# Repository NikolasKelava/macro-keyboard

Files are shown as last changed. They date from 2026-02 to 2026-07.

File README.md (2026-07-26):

# Macro Keyboard

A custom, wireless **Bluetooth LE macro keypad** with 12 mechanical keys, a magnetic rotary
encoder, and a 128×64 OLED built on a Nordic **nRF52840** module and running
[**ZMK**](https://zmk.dev). Keys and profiles are configurable live over ZMK
Studio; the encoder is a per-profile knob (volume / vertical scroll / horizontal
scroll / browser tabs). Battery-powered (2000 mAh LiPo) with USB-C charging.

This project was submitted to the **Hack Club Horizons** program. Its progress is logged
in [JOURNAL.md](./JOURNAL.md). The admission is still pending.

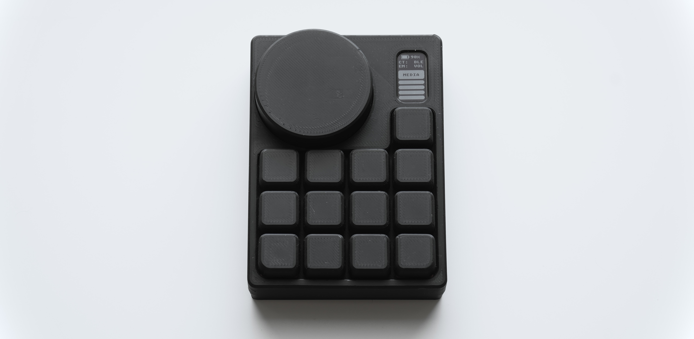
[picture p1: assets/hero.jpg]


---

## What is a macro keyboard?

A macro keyboard is a **Human Interface Device** (HID), which executes **macros** on a connected
host computer. In this sense, it functions like a conventional keyboard, serving as the 
interface between human input and a computer action.

The difference between a standard keyboard and a macro keyboard lies in their respective 
functionalities. A standard keyboard performs "normal" key bindings (e.g., numbers, letters,
and function buttons), while a macro keyboard performs macros. These can be media keys 
(e.g., volume up/down, skip title), open applications on the host computer or executing 
entire commands, performing actions that would otherwise require **multiple keystrokes on a 
standard keyboard**.

This makes it easier to navigate the operating system by **removing friction** between the user
and the host.

## What is my macro keyboard and what does it do?

**My macro keyboard has 12 macro keys, a rotary magnetic encoder, an OLED display, is battery 
powered and supports up to 7 profiles.**

The **macro assigned to each key** can be configured **per profile**. Depending on which profile is 
active, a key can have up to seven different functions. Consequently, we can perform up to **84
different actions** with our 12 keys.

The **encoder mode** can also be configured. It can act as a **scroll wheel** in both vertical and
horizontal direction, control the **volume** or switch between browser tabs on the host. These **modes 
are bound to each profile** and can be changed by assigning a key on a profile, that cycles through 
the modes of the encoder. When moving to the next keypad profile, the encoder mode changes to the 
active profile's encoder mode. Returning to the previous profile will revert the encoder mode to its 
previous state.

The **OLED display** shows the selected keypad profile, the battery capacity, the connection mode, and 
the encoder mode.

You can think of the keypad profiles as the **user layer** of the macro keypad. These profiles are 
called the "keymap", and they are the layers where the macro keyboard's functionality is configured. 
This user layer live directly on the macro keyboard, so the macros stay **the same even when changing 
host devices.** A **profile** button on the macro keyboard is used to switch between profiles.

You can **configure** the keymap and profiles in real time without recompiling or reflashing the keypad 
through [**ZMK Studio**](https://zmk.studio), a graphical user interface for ZMK keyboard firmware.

The macro keyboard connects as a keypad **via Bluetooth** or **USB**. Hosts are cross-platform (Windows, 
macOS, Linux, and iOS). The keypad can be paired with up to five hosts and conveniently switch 
between them via assigned keys on the keymap.

## Layout

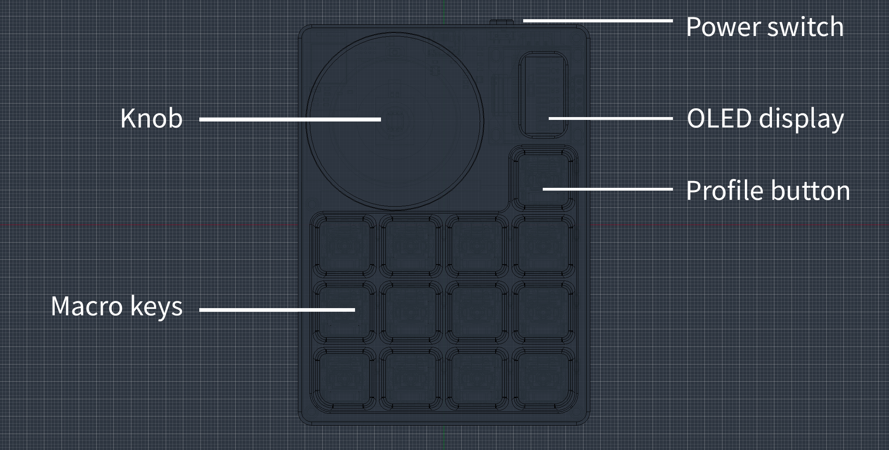
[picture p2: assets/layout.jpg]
Macro Keyboard layout


## Demo & photos

### Demo video:

[Quick demo video on youtube](https://youtube.com/shorts/6OSJ7Yoke_U)
 
### Photos: 

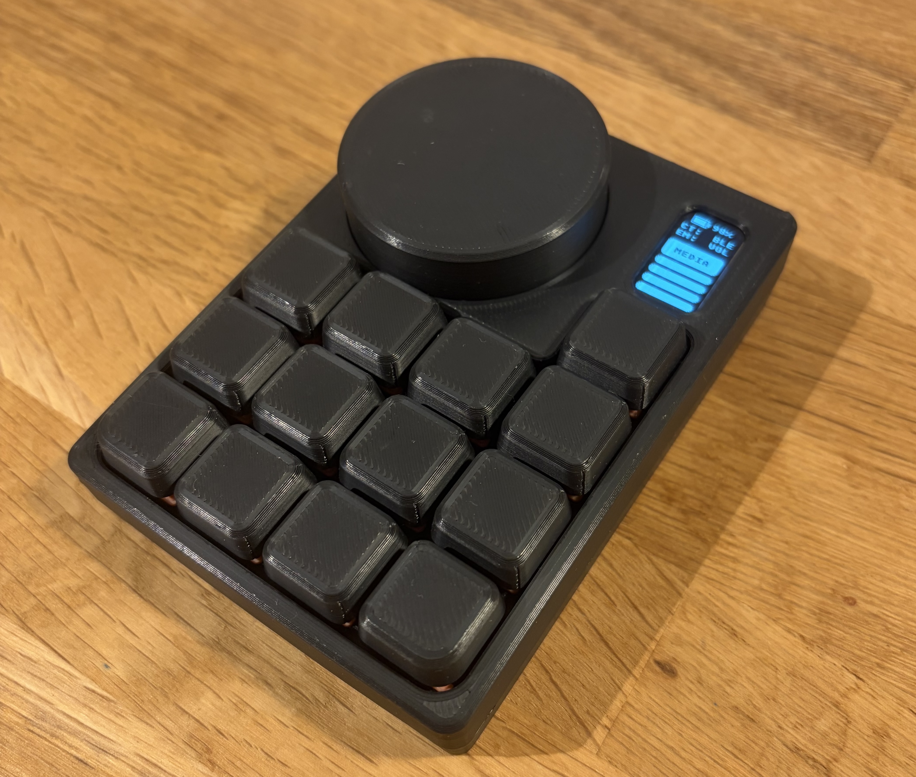
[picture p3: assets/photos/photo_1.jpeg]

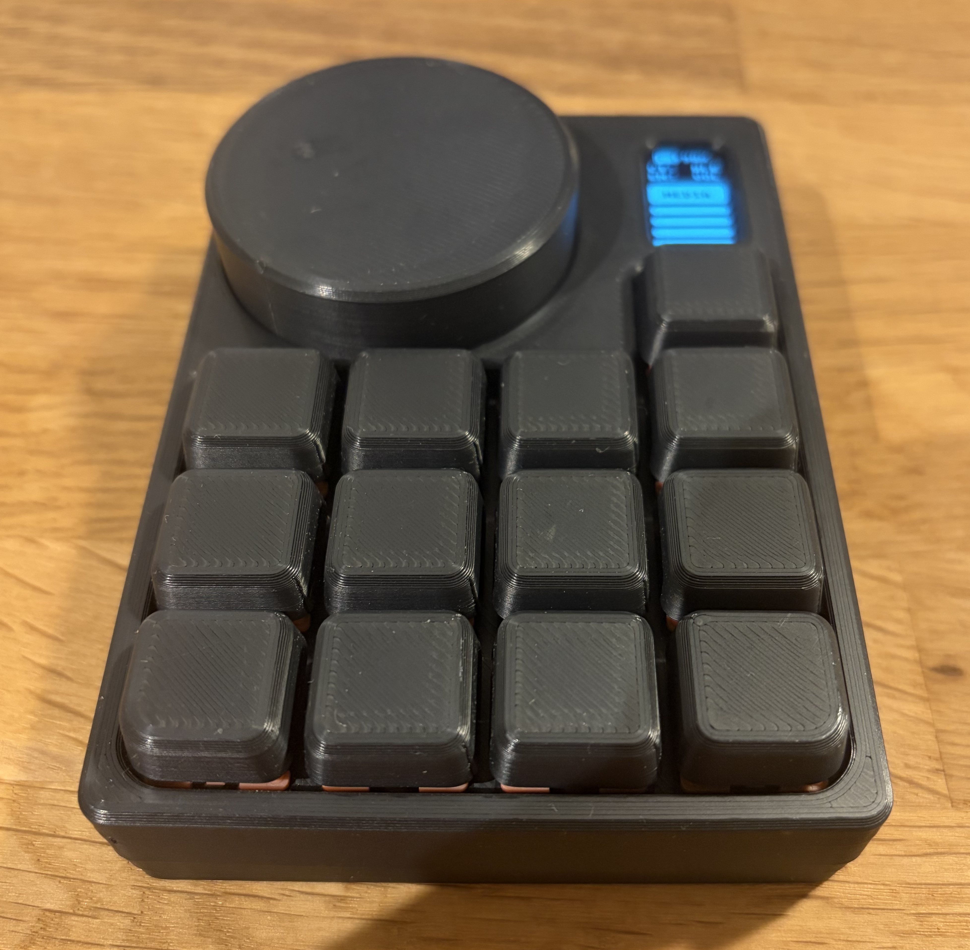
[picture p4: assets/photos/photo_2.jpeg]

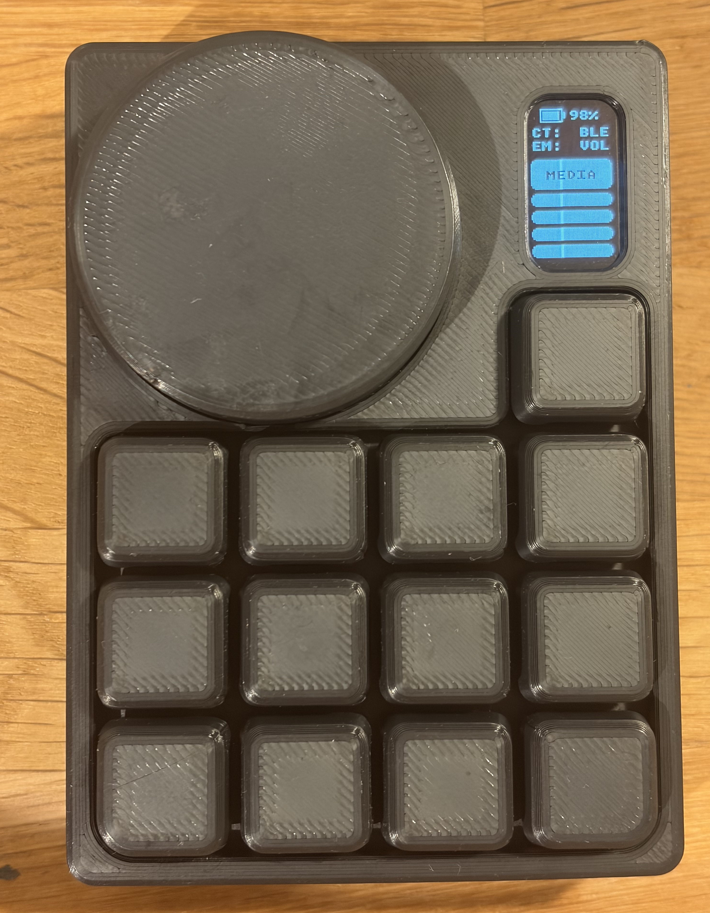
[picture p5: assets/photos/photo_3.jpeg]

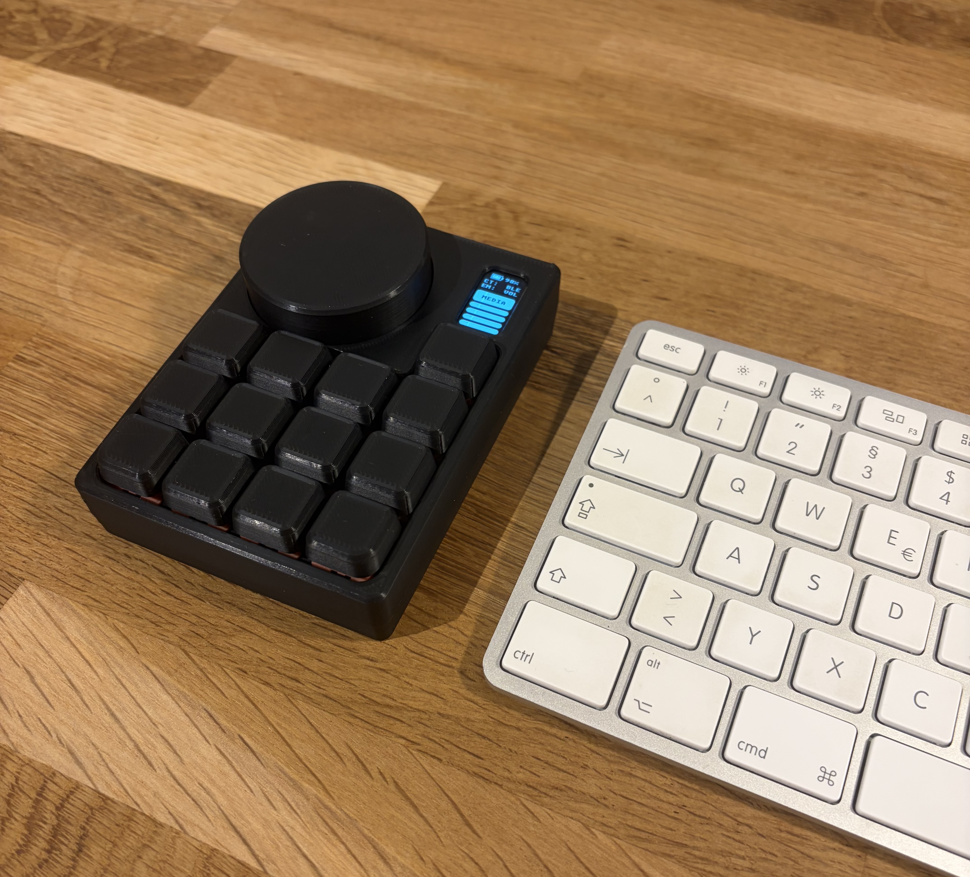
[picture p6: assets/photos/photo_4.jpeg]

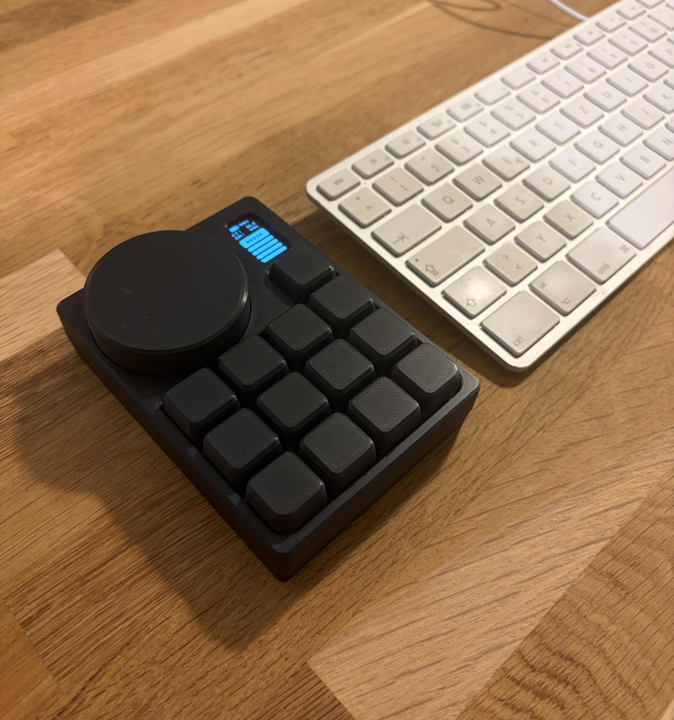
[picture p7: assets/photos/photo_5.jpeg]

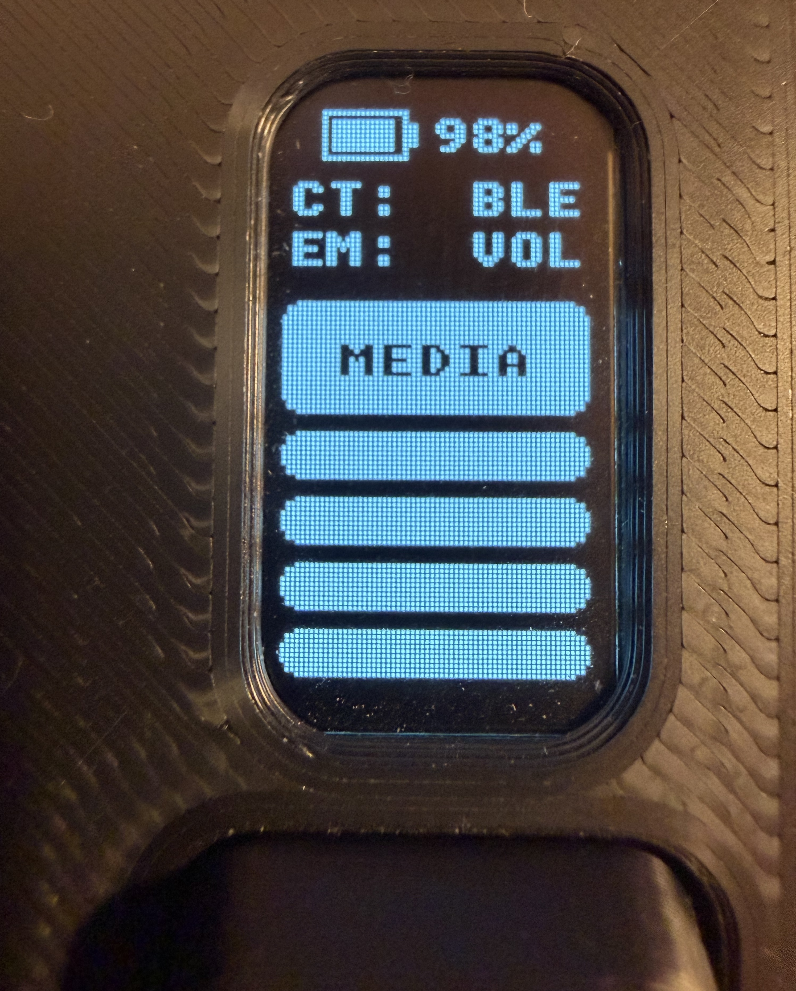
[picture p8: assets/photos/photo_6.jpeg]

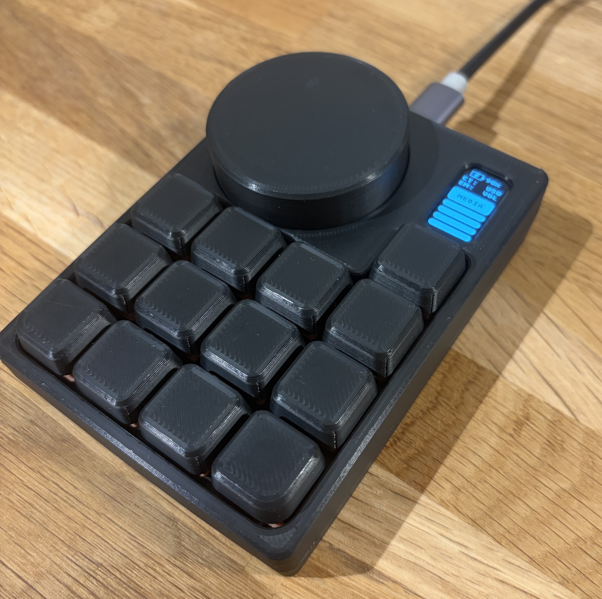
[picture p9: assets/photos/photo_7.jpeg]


## Hardware overview

| | |
|---|---|
| **MCU** | Raytac MDBT50Q-1MV2 (nRF52840 Module) |
| **Input** | 12-key matrix with mx switches (3 rows × 4 cols) + 1 profile button |
| **Encoder** | AMS AS5600 magnetic rotary encoder (over I2C) |
| **Display** | 128×64 SSD1306 OLED (over I2C, with 1 bpp) |
| **Power** | 2000 mAh LiPo, BQ24040 charger, USB-C |
| **Enclosure** | 3D printed |

## Firmware overview

The macro keyboard runs custom ZMK Firmware, configured and built over a local toolchain.
> "ZMK Firmware is an open source (MIT) keyboard firmware built on the Zephyr™ Project Real Time Operating System (RTOS)." ([Introduction to ZMK](https://zmk.dev/docs))

Full toolchain and architecture notes are in [firmware/CLAUDE.md](./firmware/CLAUDE.md).

## Repository layout

```
macro_keyboard/
├── README.md               ← you are here
├── JOURNAL.md              ← build devlog
├── assets/journal-assets/  ← images referenced from the journal
├── firmware/
│   ├── CLAUDE.md               full firmware architecture & build notes
│   ├── IMPLEMENTATION_PLAN.md  milestone-by-milestone history
│   ├── zmk-config/             ZMK config: custom board files, module, 
│   │                           AS5600 driver, behaviors
│   └── zmk                     ZMK submodule (ZMK version for my toolchain)
└── hardware/
    ├── BOM.csv          build BOM
    ├── BOM_PCB.csv      per-component board BOM (JLCPCB SMT + hand-soldered)
    ├── BUILD.md         full build and assembly guide to reproduce the macro keyboard
    ├── PCB/KiCad/Macro-Keyboard-v4/   schematic, board, Gerbers, KiCad design files
    └── CASE/                          3D-printed enclosure (Fusion + mesh exports)
```

## Bill of Materials

- **[hardware/BOM.csv](./hardware/BOM.csv)** — **Master/build cost BOM**:
  PCB fabrication, JLCPCB assembly (the parts JLC populates), shipping, the on-PCB parts I 
  solder myself (OLED, key switches, JST, SWD header), and all off-PCB parts (encoder bearing/
  magnet/knob, battery, keycaps, enclosure, screws) with the approximated cost per element.
  -> in the end: what it cost to build one unit of my macro keypad.
- **[hardware/BOM_PCB.csv](./hardware/BOM_PCB.csv)** — **PCB BOM**:
  every component that physically sits on the board; some of the parts, that need to be soldered
  onto the PCB, can't be soldered in the PCBA step, usually because those parts are to big. So I
  solder those manually. (e.g. key switches, OLED display, JST connector for LiPo)
- **[production/bom.csv](./hardware/PCB/KiCad/Macro-Keyboard-v4/production/bom.csv)** — **PCBA BOM**: 
  After manufacturing the PCB, its populated with the components in this BOM. 
  This step is the PCB assembly. Only the parts for this manufacturing step are in this 
  BOM. (e.g. nRf module, caps, resistors, usb port, etc.)

Part numbers are given only for parts that can't be substituted; common passives (resistors, 
capacitors) are specified by value/footprint and left flexible. Prices are only in `BOM.csv`.

**Per-unit cost caveat:** JLCPCB sells PCBs in quantities of at least 5. 
The per-unit total in BOM.csv is the amortized build cost, meaning that building one yourself will
cost more than the per-unit cost alone.

## Schematic, PCB & Gerbers

- **Schematic (PDF):** [Macro-Keyboard-v4.pdf](./hardware/PCB/KiCad/Macro-Keyboard-v4/Macro-Keyboard-v4.pdf)
- **KiCad source:** [hardware/PCB/KiCad/Macro-Keyboard-v4/](./hardware/PCB/KiCad/Macro-Keyboard-v4/)
- **Gerbers:** [production/Macro-Keyboard-v4.zip](./hardware/PCB/KiCad/Macro-Keyboard-v4/production/Macro-Keyboard-v4.zip)
- **SMT Assembly:** [`bom.csv` + `positions.csv`](./hardware/PCB/KiCad/Macro-Keyboard-v4/production/)
- **Case:** [hardware/CASE/](./hardware/CASE/) — Fusion source + the meshes exported for 3D printing



## Pinout

From the Macro-Keyboard-v4 schematic:

| Function | Net |
|---|---|
| Matrix columns | col0=P0.16, col1=P0.14, col2=P0.15, col3=P0.13 |
| Matrix rows | row0=P0.20, row1=P0.21, row2=P0.19 |
| I²C bus (OLED + AS5600) | SDA=P0.24, SCL=P0.25 |
| Profile button | P1.02 (diode to GND, polled) |
| Battery ADC | P0.04 (AIN2, ÷ voltage divider) |

## Firmware — build & flash

Full toolchain and architecture notes are in [firmware/CLAUDE.md](./firmware/CLAUDE.md).
In short (especially for reproducing the macro keyboard):

**Flashing:** I installed a Adafruit nRF52 bootloader on my board. With this bootloader I
can use UF2 drag and drop to flash the firmware by just double-tapping the reset button,
which mounts the keypad as a USB drive (`NRF52BOOT`), and then dragging `zmk.uf2` onto it - the build format for UF2 bootloaders. The board reflashes and reboots into the new firmware.

By default my pipeline will give both .hex and .uf2 build artifacts (that contain the
firmware) for flashing the macro keyboard. Flashing the .hex artifact over SWD with a 
debugger probe will work, but the macro keypad won't boot into the firmware!

This is because the UF2 bootloader sits right at the start of the flash partition. When 
flashing, the actual Zephyr firmware receives a place after the bootloader. It has an 
offset. The bootloader then points to the firmware when booting. When the keypad is in 
UF2 drag-and-drop mode (by double-tapping reset), the firmware after the bootloader in 
the partition is replaced. The cool thing I noticed is that the user-layer keymap won't 
be replaced because it's located farther away from the firmware. Therefore, you can 
update the firmware without losing your keymaps.

However, the defined offset for the bootloader will be applied to all artifacts when 
building the firmware. If no bootloader is installed on your macro keyboard and you flash 
via SWD, there won't be a bootloader to point to your firmware and boot it.

If you don't want to install a bootloader and want to flash the firmware directly with 
your debugger, read the section in [firmware/CLAUDE.md → Bootloader](../firmware/CLAUDE.md) "If the bootloader has to be removed".

**Build (from `firmware/zmk_toolchain/app`, ZMK toolchain):**

```bash
source /firmware/zmk_toolchain/.venv/bin/activate

west build -p -d build/macro_keyboard/m3 -b macro_keyboard -- \
  -DZMK_CONFIG="$PWD/../../zmk-config/config" \
  -DZMK_EXTRA_MODULES="$PWD/../../zmk-config/module"
```

Add `-S studio-rpc-usb-uart -DCONFIG_ZMK_STUDIO=y` for the ZMK Studio variant.
The build emits both `zmk.uf2` (drag-drop) and `zmk.hex` (SWD via `west flash -r pyocd`).

Before doing so: Follow the official [ZMK firmware document](https://zmk.dev/docs/development/local-toolchain/setup) on setting up the local Zephyr toolchain to build the ZMK firmware with macro_keyboard config. Install the current version of ZMK, which is added as a submodule to this repo. Install under the path `firmware/zmk_toolchain/`.

## Steps to reproduce

Full instructions: **[hardware/BUILD.md](./hardware/BUILD.md)**.

## Safety notes

- **LiPo battery (2000 mAh):** observe correct polarity; do not puncture, crush, or short. Charge
  only through the on-board **BQ24040** charger via USB-C. Disconnect and isolate a swollen or 
  damaged cell — do not charge it.
- The board periphere is **3.3 V** logic; do not back-feed 5 V into signal pins.
- Powered by USB-C — use a compliant cable/supply.

## AI disclosure

Firmware:
I used Claude Code when developing the firmware. It helped me with tasks such as setting up the ZMK 
firmware, configuring my custom board, writing additional modules for the OLED display and a AS5600 
driver, and behaviors. Especially for debugging, I used Claude Code.
Although it may sound like I completely handed over the firmware work to Claude, in a sense, this is
true. However, I am obviously deeply involved in the development and manage it. Claude's role is to 
speed up the process by taking over tedious tasks and also giving me good overviews on how things 
can be implemented.
I did the research on the available firmware choices and how to design the hardware around them.

Hardware:
The hardware portion of the project, which is the largest part of the project, was completely done 
without the use of an LLM or any other AI.

Anything that Hackclub specifically prohibited the use of AI for was done without it (e.g. this README.md).

## License

| Part | License | File |
|---|---|---|
| Firmware, ZMK config, scripts, docs (everything outside `hardware/`) | **MIT** | [LICENSE](./LICENSE) |
| Hardware design — KiCad schematic/PCB, Gerbers, CAD/case, BOMs (everything in `hardware/`) | **CERN-OHL-S v2** | [hardware/LICENSE](./hardware/LICENSE) |

If you reuse the hardware design, keep a notice like this with it:

```
Copyright (c) 2026 Nikolas Kelava
This source describes Open Hardware and is licensed under CERN-OHL-S v2.
You may redistribute and modify this source and make products using it under
the terms of CERN-OHL-S v2 (https://ohwr.org/cern_ohl_s_v2.txt).
This source is distributed WITHOUT ANY EXPRESS OR IMPLIED WARRANTY, INCLUDING
OF MERCHANTABILITY, SATISFACTORY QUALITY AND FITNESS FOR A PARTICULAR PURPOSE.
Please see the CERN-OHL-S v2 for applicable conditions.
Source location: https://github.com/NikolasKelava/macro-keyboard
```

Third-party code keeps its own license: [ZMK](https://github.com/zmkfirmware/zmk)
is MIT, the [Zephyr RTOS](https://github.com/zephyrproject-rtos/zephyr) is
Apache-2.0, and the [Adafruit nRF52 bootloader](https://github.com/adafruit/Adafruit_nRF52_Bootloader)
in `firmware/bootloader/` is MIT.

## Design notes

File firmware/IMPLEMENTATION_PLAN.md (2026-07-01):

# MacroKeyboard — Implementation Plan & Milestone History

> This file is the historical record of how `macro_keyboard` was built: the
> **initial functional requirements** the project started from, and the
> **milestone-by-milestone implementation strategy** that realised them.
>
> For the **current** device description, functional requirements, pinmap,
> build/flash procedure, and the distilled load-bearing constraints, see
> [CLAUDE.md](./CLAUDE.md). Where the initial requirements below differ from
> the current behaviour (e.g. a fixed 4 profiles became a flexible 1–7), the
> current behaviour in CLAUDE.md wins — this file preserves the baseline the
> plan was designed against.

## Initial Functional Requirements — Behavioral Overview

*(The original requirements at project start. Retained as the baseline; some
have since evolved — see CLAUDE.md for current behaviour.)*

1. **Connectivity**
   - Acts as a BLE HID keyboard/media device; should work OS-agnostically (Windows/macOS/Linux/iOS/Android) via standard HID.
2. **Profiles (4 total)**
   - A single hardware button cycles active profile 1→2→3→4→1.
   - Each profile defines:
     - Key macros (media keys, shortcuts, app-launch sequences where supported by host OS)
     - Encoder behavior (volume or scroll; direction/axis can differ per profile)
3. **Display**
   - Always shows:
     - Battery indicator (percentage/level derived from ADC measurement)
     - Profile list 1–4, with active profile visually marked
   - Display updates on profile change and periodically for battery status.
4. **Macros / Keymap editing**
   - All macros and key bindings must be editable via ZMK Studio.
   - Ensure the configuration includes whatever is required by the current ZMK Studio workflow (per latest ZMK docs).
5. **Power**
   - Battery ADC reading is exposed to the firmware (and optionally to UI).
   - Aim for low-power behavior consistent with ZMK defaults (sleep/idle as supported).

## Implementation Strategy — Milestones

### Milestone 1 — Build reliably.   [DONE]

Board recognised by Zephyr/ZMK (board.yml, Kconfig.*, DTS, defconfig); matrix scans 3x4; profile button wired (input-only at this stage); dev + studio variants build pristinely.

### Milestone 2 — UI infra + battery sense.   [DONE]

I2C0 enabled (P0.24 SDA / P0.25 SCL); ssd1306@0x3c node + chosen `zephyr,display = &oled`; `CONFIG_ZMK_DISPLAY=y` enables LVGL; battery voltage-divider on AIN2 with `CONFIG_ZMK_BATTERY_REPORTING=y`. Visuals not yet exercised on hardware.

### Milestone 3 — Profiles + profile-button cycle.   [DONE]

- `macro_keyboard.keymap` defines 4 layers (media / productivity / browser / bt). Each layer's pos-12 binding is `&profile_next`.
- `&profile_next` is a custom ZMK behavior in `module/src/behavior_profile_next.c` that reads `zmk_keymap_highest_layer_active()` and advances mod 4 — so cycling is consistent regardless of which layer's binding fires.
- Profile button uses kscan-composite combining the 12-key matrix (`zmk,kscan-gpio-matrix`) and a 1-key direct kscan (`zmk,kscan-gpio-direct` on P1.02) at row_offset=3. Matrix-transform is 4r x 4c with map[12] = RC(3,0). The diode-clamped pressed voltage (~0.7V) is marginal for nRF52 GPIO interrupts, so `CONFIG_ZMK_KSCAN_DIRECT_POLLING=y` polls instead. Matrix kscan unaffected.
- Physical layout places the profile button at (300, 0) — above the top-right matrix key — so Studio renders it where the user actually presses.
- `&studio_unlock` retained on layer 0 key 8 (FR §4: at least one layer).
- macOS-style shortcuts: productivity / browser layers use LG (Cmd), not LC (Ctrl). Edit in Studio for non-Mac hosts.
- Hardware-verified: profile cycling works; per-layer keypresses produce correct HID output. Studio's active-layer indicator is currently not showing — deferred to M6.

### Milestone 4 — Display.   [DONE]

`macro_keyboard.conf` selects CUSTOM:

```
CONFIG_ZMK_DISPLAY=y
CONFIG_ZMK_DISPLAY_STATUS_SCREEN_CUSTOM=y
CONFIG_ZMK_WIDGET_BATTERY_STATUS=y   (kept to pull LV_USE_LABEL in)
```

`module/src/status_screen.c` is the screen body, gated on `CONFIG_ZMK_DISPLAY_STATUS_SCREEN_CUSTOM` in `module/CMakeLists.txt`.

**Layout** (logical 64w x 128h portrait — the panel is physically 128x64 landscape and we rotate via a custom flush callback, see "Rotation"):

- battery row, centred horizontally at the top of the rotated canvas: a custom battery icon ("[==] NN%"). Drawn crisp for the 1bpp panel — LVGL renders the 4bpp anti-aliased Montserrat font (and the FontAwesome LV_SYMBOL battery/charge glyphs baked into it) by thresholding luminance at 127 onto I1, which makes them bulky/fuzzy with stray edge pixels. So the row uses NO fonts/symbols for the icon: the percentage is lv_font_unscii_8 (true 1bpp, 8 px, no AA) and the battery is full-opacity axis-aligned rectangles (body outline + nub + level-proportional fill). While charging the interior is filled solid and a 7x9 lightning bolt (hand-drawn 1bpp lv_canvas, OFF/dark pixels on the lit fill, spanning the full interior height) is overlaid as a cut-out. battery_update re-centres the whole row each update. NOT a polarity bug — polarity is correct (else the whole screen would invert). Requires `LV_FONT_UNSCII_8=y` and `LV_USE_CANVAS=y` (pinned in board Kconfig.defconfig). Subscribes to zmk_battery_state_changed + zmk_usb_conn_state_changed for live cable/SoC updates.
- centred column below: four 52x22 cells (radius 8) stacked vertically (6 px gap, first cell top at y=16, last cell bottom at y=122). The 6 px left/right margin and 6 px bottom margin to the screen edge are equal by design. Each cell is an lv_obj container; default style is a rounded outline with transparent fill, active style (LV_STATE_CHECKED) is a solid fill with an inverted text_color the child digit label inherits. The digit uses lv_font_unscii_16 (1bpp) so the active (inverted) digit's stems stay pixel-identical to the inactive ones — a 4bpp font thresholds asymmetrically on inversion and the selected digit renders ~1 px thinner. profile_update toggles LV_STATE_CHECKED. Cells need to be containers (not bare labels with bg styles) because in LVGL v9 lv_label doesn't draw its own background reliably.
- "active profile" is derived from `zmk_keymap_highest_layer_active()`, same source the profile_next behavior advances. Layers 0..3 map 1:1 to profiles 1..4; indices outside that range fall back to slot 0.

Both widgets use ZMK_DISPLAY_WIDGET_LISTENER (see `app/include/zmk/display.h`), which marshals state updates from the system work queue onto the dedicated display work queue under a mutex — same pattern used by ZMK's stock battery_status / layer_status widgets.

**Rotation.** LVGL v9's `lv_display_set_rotation()` only updates the logical resolution; Zephyr's `lvgl_flush_cb_mono` writes LVGL's logical coords straight to the panel and does not transform pixels, so on this stack the call alone is a no-op for rendering. `status_screen.c` installs its own rotated_flush_cb via `lv_display_set_flush_cb` after rotation is set: the callback walks the LVGL 1bpp pixel buffer bit by bit, rotates 270° CW into a static 1100-byte scratch buffer, recomputes the area from logical (64x128) to physical (128x64) coordinates, then delegates to `lvgl_flush_cb_mono` (declared extern from `zephyr/modules/lvgl/lvgl_display_mono.c`) which handles the SSD1306 page-major packing. Direction (270° vs 90°) was picked by hardware test; the device is mounted with the panel's physical left edge at the user's top. The default `lvgl_rounder_cb_mono` is reused unchanged because it aligns both x and y to 8 (the SSD1306 is MONO_VTILED), and both axes stay 8-aligned through our rotation.

**Polarity.** The DTS has no `inversion-on`, so the SSD1306 driver reports PIXEL_FORMAT_MONO01 — in that format `lv_color_white()` maps to an OFF pixel and `lv_color_black()` to a LIT pixel. theme_mono is calibrated for this convention, so the screen leaves bg/text to the theme and only swaps white<->black inside the cell styles where we want the inverse (lit cell outlines/fill, OFF digit when active).

**Six Kconfig settings are load-bearing** (all pinned in board Kconfig.defconfig under `if LVGL` / `if ZMK_DISPLAY`). Removing ANY of them silently hangs the firmware at boot and BLE/USB never enumerate:

1. `LV_COLOR_DEPTH_1` + `LV_Z_BITS_PER_PIXEL=1` — match the 1bpp SSD1306. Default RGB565/32bpp makes LVGL allocate a framebuffer too large for the LV mem pool; you see noise + hang.
2. `LV_Z_VDB_SIZE=64` — Zephyr default of 10% trickles partial flushes faster than I2C can serve; display work queue starves.
3. `ZMK_DISPLAY_WORK_QUEUE_DEDICATED` — isolates display work from the system work queue (where BLE advertising + USB-HID TX run). Without this any LVGL stall takes BLE/USB down with it.
4. `LV_USE_THEME_MONO=y` — BUILT_IN auto-implies it, CUSTOM does not. Without it LVGL has no default font on the display, lv_label_create renders with NULL font → hardfault → BLE/USB die too.
5. `LV_FONT_MONTSERRAT_16` + `LV_FONT_DEFAULT_MONTSERRAT_16` — same story: BUILT_IN sets them inside its `if` block; CUSTOM doesn't.
6. `LV_Z_MEM_POOL_SIZE=12288` — ZMK's `app/src/display/Kconfig` sets this default to 4096 only when STATUS_SCREEN_BUILT_IN is selected. With CUSTOM it falls back to Zephyr's 2048-byte default — not enough for even theme_mono + screen + one label, so lv_obj_create silently returns NULL and the next deref hardfaults, taking BLE/USB down. 8192 covered the original M4 layout; the crisp battery-icon rework added the body/nub/fill objects + the charge-bolt canvas, so we pin 12288 in board Kconfig.defconfig with measured headroom. (~4 KB extra RAM, well within budget.)

#### M4 — Resolved: CUSTOM Hang Root Cause Was LV_Z_MEM_POOL_SIZE

The "all 5 Kconfig settings match BUILT_IN exactly and CUSTOM still hangs" puzzle was solved by diffing a pristine CUSTOM `.config` against the working BUILT_IN `.config`. The only meaningful difference (beyond the screen choice and the widgets we don't enable) was:

```
CONFIG_LV_Z_MEM_POOL_SIZE: 4096 (BUILT_IN) vs 2048 (CUSTOM)
```

ZMK's `app/src/display/Kconfig` has `default 4096 if STATUS_SCREEN_BUILT_IN` on that symbol — so flipping to CUSTOM silently drops the LVGL allocator pool to Zephyr's 2048-byte default. theme_mono + screen + label can't all fit, lv_mem_alloc returns NULL, and the next deref hardfaults the display thread — which the kernel can't recover from since several init-time submitted works share the same crashed context, explaining why BLE/USB never enumerate either.

Fix: pin `config LV_Z_MEM_POOL_SIZE default 4096` in board Kconfig.defconfig under `if LVGL` so it applies regardless of screen choice. After the fix the pristine CUSTOM `.config` differs from BUILT_IN only in the intended places (screen choice + widget enables). (Later bumped to 12288 for the battery-icon rework — see load-bearing setting #6 above.)

### Milestone 5 — AS5600 magnetic encoder.   [DONE]

**Driver** (`module/drivers/sensor/as5600/`). Custom DT compatible `nikolas,as5600` — NOT Zephyr's built-in `ams,as5600`, which would double-instantiate (Zephyr ships a driver for that compatible). The AS5600 has no IRQ wired to the MCU (its OUT pad P0.29 is unused), so the driver POLLS: a dedicated thread (kept off the system work queue so a blocked I2C read on the OLED-shared bus can't stall BLE/USB) reads RAW ANGLE (0x0E/0x0F) every poll-period-ms (5), and synthesises the SENSOR_TRIG_DATA_READY trigger ZMK's keymap-sensors subsystem requires. It reports rotation **delta in degrees** on SENSOR_CHAN_ROTATION (val1 whole, val2 micro), only once ≥1° has accumulated (carrying the remainder) — a report with val1==0 hits a legacy "val2 is a raw tick count" path in ZMK's sensor-rotate behaviour.

Two signal-conditioning stages (both Kconfig, in the driver's Kconfig):

- `AS5600_SMOOTHING_SHIFT` (1): light wrap-aware EMA low-pass on the angle.
- `AS5600_DEADBAND_COUNTS` (4): ignore motion within N counts of a reference angle; advance the reference only on real movement.

The deadband is LOAD-BEARING, not cosmetic: a still magnet jitters ±1-2 LSB on RAW angle; without the deadband that random-walks past the 1° report threshold ~1×/s, raising spurious sensor events. ZMK's activity monitor (`app/src/activity.c`) subscribes to zmk_sensor_event, so those events reset the idle timer — the board never idles (display never blanks, never deep-sleeps) AND the constant sensor→behaviour→HID churn eventually hung the board over USB. Adding the deadband fixed both.

Also load-bearing: `AS5600_STARTUP_DELAY_MS` (1000) — the thread waits before its first I2C read so the OLED/BLE/USB finish init first (touching the shared bus during OLED init was an intermittent boot hang); and `AS5600_THREAD_STACK_SIZE` (2048) — the thread is the context in which the whole sensor→behaviour→HID chain runs synchronously.

**Per-profile mode** (custom firmware — ZMK STUDIO CANNOT EDIT ENCODER/SENSOR BINDINGS in this ZMK version: keymap proto is key-position only). `encoder_mode.c` holds one mode per profile (= per layer) in RAM: volume / vertical-scroll / horizontal-scroll / TABS. Defaults {vol, vscroll, tabs, vol} (browser profile defaults to tabs). `&enc_dispatch` is the sensor-binding on every layer; it reads the active profile's mode each tick and acts. `&enc_mode_next` (key, pos 11) cycles the mode. (Persisting across reboot deferred — M6.)

**Actions & resolution** (all DT props on `&enc_dispatch`; it quantises accumulated micro-degrees per-mode, carrying the sub-tick remainder):

- volume → `&kp C_VOL_UP/DN`, coarse (volume-triggers-per-rotation 14).
- tabs → `&kp LC(TAB)/LC(LS(TAB))` (next/prev browser tab; Ctrl+Tab works cross-browser on macOS), coarse (tab-triggers-per-rotation 12).
- V/H scroll → wheel reports to the `&msc` input device, finer (scroll-triggers-per-rotation 120). Needs `CONFIG_ZMK_POINTING=y`. NOT the `&msc` *behavior* (a velocity×time model for held keys, ≈0 per tick) — uses input_report_rel on the `&msc` input device.
- CW = volume-up / scroll-up / scroll-right / next-tab.

**Scroll feel is HOST-OWNED, not firmware** (hard-won; don't re-litigate). macOS:

- IGNORES the high-res Resolution Multiplier for this device (SMOOTH_SCROLLING on vs off builds felt identical);
- VELOCITY-CAPS the report RATE — more reports/s does NOT scroll faster (verified with 10× reports, and USB vs BLE: all identical);
- honours per-report MAGNITUDE, but native macOS adds its own accel "jump" and LinearMouse normalises magnitude to a fixed distance.

So firmware emits a CLEAN LINEAR line-delta stream (d_scroll = ticks × scroll-units, scroll-units=1, NO firmware acceleration) and a host smooth-scroll app owns smoothing+accel+inertia. Mac Mouse Fix (set to "use macOS settings") gives smooth+accel+precision and also fixes VS Code fast-scroll. Base scroll speed = scroll-triggers-per-rotation. SMOOTH_SCROLLING left y (harmless on macOS, helps high-res-aware hosts).

**USB HANG (resolved).** The sensor→behaviour→HID chain runs synchronously in the AS5600 poll thread (sensors.c non-ISR path runs the trigger in caller ctx), and each USB HID send blocks on a 30 ms semaphore (`app/src/usb_hid.c`). A fast spin fires the sensor ~200 Hz; ONE HID REPORT PER TICK sustained wedges USB HID TX and hangs the board (a host polling hiccup → 30 ms stall). Fix: `&enc_dispatch` COALESCES scroll line-deltas and emits at most once per scroll-min-interval-ms (12 ≈ 83/s, below the always-stable BLE rate), carrying the signed remainder so no rotation is lost; macOS rate-cap + app smoothing make it imperceptible. (The rate is what hung it, not the report path.)

Hardware-verified: volume + V/H scroll + tabs per profile, mode key cycles, display blanks at rest, no USB/BLE hang under sustained scrolling.

### Milestone 6 — Power + ZMK Studio polish.   [MOSTLY DONE — core HW-verified; remaining: user HW checks (BLE multi-host, battery % calibration, on-battery power draw)]

**Status-screen rework** [DONE, HW-verified]. Reworked the M4 layout: top battery row (unchanged), then `CT:` (connection type USB/BLE, from `zmk_endpoints_selected().transport`, subscribed to `zmk_endpoint_changed`) and `EM:` (encoder mode VOL/VSCR/HSCR/TABS, subscribed to the new `zmk_encoder_mode_changed` event) split labels (prefix left edge / value right edge, unscii_8), then a vertical profile column. The active profile is a full-height rounded cell with its layer name (unscii_8, ≤7 chars) inverted inside; inactive profiles are squeezed filled bars whose height scales to the live profile count. Cells are hand-drawn into a 1bpp `lv_canvas` (a sub-pixel symmetric rounded-rect rasterizer — crisp corners, no LVGL bevel) with direct bitmap writes + one `lv_obj_invalidate` per update (per-pixel `lv_canvas_set_px`/`fill_bg` invalidate per call → switch lag; avoid). Canvas gotcha: the I1 buffer has an 8-byte in-buffer palette that `lv_draw_buf_goto_xy` skips but `LV_CANVAS_BUF_SIZE` doesn't reserve — size the buffer with `+ palette_bytes` and take the bitmap base from `lv_draw_buf_goto_xy(buf,0,0)`.

**Flexible profile count + Studio add/delete** [DONE, HW-verified]. Keymap is now 5 blank profiles (`&none` except pos 3 `&enc_mode_next`, pos 12 `&profile_next`; P1 keeps `&studio_unlock` pos 8) + 2 `status = "reserved"` spare slots (P6, P7) → up to 7 (the screen's `MAX_PROFILES`). With reordering on (auto-selected — see below), `ZMK_KEYMAP_LAYERS_LEN` counts all 7; only the 5 okay layers start active, reserved ones are INVAL spares Studio's "add layer" fills. The dev variant (Studio RPC transport absent) excludes reserved layers entirely (stays at 5). `&profile_next` (`behavior_profile_next.c`) and `encoder_mode.c` size/wrap on the *live* valid-layer count, so cycling tracks adds/removes. `menuconfig ZMK_STUDIO` (in `macro_keyboard.conf`) selects `ZMK_STUDIO_RPC` for non-split boards → which selects BOTH `ZMK_KEYMAP_LAYER_REORDERING` and `ZMK_KEYMAP_SETTINGS_STORAGE`, in *both* variants. So Studio add/remove/rename of profiles persists in NVS.

**AS5600 activity-gating (power)** [DONE, HW-verify pending]. The poll thread now backs off from `poll-period-ms` (5 ms) to `CONFIG_AS5600_IDLE_POLL_PERIOD_MS` (100 ms) whenever `zmk_activity_get_state() != ZMK_ACTIVITY_ACTIVE` — cutting the ~200 wakeups/s that blocked the SoC's low-power idle while the (deadbanded, event-free) magnet sits still. The first notch after idle raises a sensor event → activity resets to ACTIVE → fast poll resumes next loop (self-correcting; worst-case first-notch latency = the idle period). The driver is its own `zephyr_library` subdir, so its `CMakeLists.txt` needs the `app/include` path added explicitly to reach `<zmk/activity.h>`.

**Encoder-mode persistence** [DONE, HW-verified]. `encoder_mode.c` persists the per-profile modes array to NVS under `encmode/modes` via a `SETTINGS_STATIC_HANDLER_DEFINE` (loaded by ZMK's `settings_load()` at boot) + a `settings_save_one` on each `encoder_mode_cycle()`. The save is dispatched **immediately** (`k_work_reschedule(..., K_NO_WAIT)` on the system wq, NOT the 60 s `ZMK_SETTINGS_SAVE_DEBOUNCE`) so a mode change survives an immediate power-off; rapid cycles in one wq tick still coalesce. Blob size is stable (compile-time `PROFILE_COUNT`); a length mismatch on load falls back to the firmware defaults.

**Status-screen cell geometry** [DONE, HW-verified]. Two refinements over the rework above: (1) every cell (active + inactive) uses one fixed `CELL_RADIUS` (5) for its round-off — the old radius = squeezed/2 only looked right at count 5, giving a bevel/too-small corner at other counts; (2) inactive cells are capped at `MAX_SQUEEZED_H` (10 px) and the column is NOT stretched to the bottom edge, so e.g. with 2 profiles the unselected cell is a 10 px pill with free space below rather than a giant bar. Inactive height only shrinks below 10 px (to the 5 px floor) when too many profiles exist to fit.

**USB crash — root cause: clipped I1 canvas image → LVGL RGB565 layer OOB** [RESOLVED, HW-verified]. Symptom: with USB connected the board went totally unresponsive (a few minutes at first; once `HW_STACK_PROTECTION`+reboot were added it became an immediate reboot-loop on USB), recovering the instant USB was unplugged; never on BLE. The one thing drawn ONLY on USB is the **battery charging icon** (the lightning bolt). Diagnosed on-screen, no debugger: (1) `FLT display queue r26` = a fault in ZMK's **display work queue**; the PC was garbage because r26 = `K_ERR_ARM_BUS_IMPRECISE_DATA_BUS` (imprecise → the stacked PC points at a *later* instruction). (2) Setting `ACTLR.DISDEFWBUF` (disable the Cortex-M write buffer) made faults **precise** → next capture `FLT display queue r19 pc=…` where r19 = `K_ERR_ARM_MEM_DATA_ACCESS` and the PC resolved to **`argb8888_image_blend` in `lv_draw_sw_blend_to_rgb565.c`** — LVGL blending through an **RGB565** path in a `LV_COLOR_DEPTH_1` build. Root cause: the bolt was an lv_canvas **image that was a clipped child of the bordered `batt_body` container and overlapped `batt_fill`**, so LVGL allocated an **RGB565 intermediate layer** whose buffer math is wrong for 1bpp, and the blend ran out of bounds → MPU data-access fault. `col_cbuf` never crashed because it's a **standalone, unclipped, direct child of the screen**. Fix: make the charge graphic exactly that — ONE interior-sized (16x9) standalone I1 canvas that is a direct child of `screen`, solid lit fill + bolt punched out, positioned in absolute coords in `battery_update`, with `batt_fill` HIDDEN while charging (no overlap). **Lessons: (a) on a 1bpp display, avoid making an lv_canvas/image a clipped child of a styled/bordered container or overlapping another obj — it triggers an RGB565 intermediate-layer path that's broken for `LV_COLOR_DEPTH_1`; keep decorative canvases as standalone direct children of the screen like `col_canvas`. (b) An imprecise bus fault (reason 26) has a useless PC — set `ACTLR.DISDEFWBUF` to force precise faults before trusting the captured PC. (c) Every I1 `lv_canvas` static buffer must add `LV_COLOR_INDEXED_PALETTE_SIZE(I1)*4` (=8 B, `I1_PALETTE_BYTES`) on top of `LV_CANVAS_BUF_SIZE` — a real latent bug fixed for both canvases, though not the crash cause here.**

Kept as resilience/robustness alongside the fix (permanent): `CONFIG_HW_STACK_PROTECTION=y` (MPU guard — was OFF despite `CONFIG_ARM_MPU=y`) and `module/src/fatal.c` overriding Zephyr's weak `k_sys_fatal_error_handler` (which spins forever) with `sys_reboot()` (needs `CONFIG_REBOOT=y`) so a fault recovers instead of hanging. The speculative stack bumps from the hunt (`USB_NRFX_WORK_QUEUE`, `MAIN`, AS5600) were **reverted** once the LVGL cause was found — they were never the issue. The USB-only timing was because on USB the board never deep-sleeps (`is_usb_power_present()` skips the sleep path) so it kept rendering the bolt, whereas on battery it deep-sleeps at the 15-min `ZMK_IDLE_SLEEP_TIMEOUT`.

*No-debugger fault-capture recipe (used here, since removed — reuse if a fault recurs).* A temporary `k_sys_fatal_error_handler` override recorded the faulting thread name (needs `CONFIG_THREAD_NAME=y`) + reason + PC into a `__noinit` struct — which survives the warm reboot AND a USB unplug while the LiPo keeps RAM powered — and `status_screen.c` showed `FLT <thread> r<reason> pc<hex>` on the next clean boot. Decoding: reason is `enum k_fatal_error_reason`, but ARM adds arch-specific codes at `K_ERR_ARCH_START = 16` (e.g. 19 = `K_ERR_ARM_MEM_DATA_ACCESS`, 26 = `K_ERR_ARM_BUS_IMPRECISE_DATA_BUS`); map the PC with `arm-zephyr-eabi-addr2line -e zmk.elf`. For an imprecise fault (26) the PC is useless until you set `ACTLR.DISDEFWBUF` (0xE000E008 bit 1) to force precise faults. All of that scaffolding (`fault_record.h`, the capture, the DISDEFWBUF init, `THREAD_NAME`) was stripped after the fix was confirmed.

**Studio active-layer indicator** [RESOLVED — not a firmware issue]. The keymap RPC `Notification` message (`zmk-studio-messages/keymap.proto`) carries only `unsaved_changes_status_changed`; there is no active-layer-changed notification in this ZMK Studio version, and the docs list no live active-layer indicator. So Studio cannot highlight the hardware-active layer — by design, not misconfig. The on-device OLED profile column already serves that role.

**Remaining (user HW verification only):**
- BLE multi-host: config supports 5 paired hosts (`BT_MAX_PAIRED=5`, `BT_MAX_CONN=5`). Host-switching keys (`&bt BT_SEL n`, `&bt BT_CLR`, `&out`) are NOT pre-bound (keymap is all-`&none` by request) — assign in Studio to test/switch across hosts.
- Battery divider: DTS scaling is correct for the measured hardware (330k Batt+→VD_ADC, 1M VD_ADC→GND → `output-ohms=1000000`, `full-ohms=1330000`, ×1.33). Remaining is calibrating the on-screen % against a multimeter reading of the pack.

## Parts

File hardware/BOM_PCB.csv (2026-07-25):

Reference | Value | Datasheet | Footprint | Qty | DNP
C1,C2,C4,C5,C8,C13 | 10uF | ~ | Capacitor_SMD:C_0603_1608Metric | 6
C3,C6,C7,C9,C11,C12,C14,C15,C16 | 0.1uF | ~ | Capacitor_SMD:C_0603_1608Metric | 9
D1,D13,D14,D15,D16,D17,D18,D19,D20,D21,D22,D23,D24 | Diode |  | ScottoKeebs_Components:Diode_SOD-123 | 13
IC1 | AS5600-ASOT |  | as5600-footprint:SOIC127P600X175-8N | 1
J2 | OLED_128x64 |  | ScottoKeebs_Components:OLED_128x64 | 1 | x
J5 | JST_03 |  | Connector_JST:JST_XH_B3B-XH-AM_1x03_P2.50mm_Vertical | 1 | x
JUSB1 | USB_C_Receptacle_USB2.0 | https://www.usb.org/sites/default/files/documents/usb_type-c.zip | Connector_USB:USB_C_Receptacle_GCT_USB4105-xx-A_16P_TopMnt_Horizontal | 1
L1 | 10 µH, ≥ 80 mA | ~ | Inductor_SMD:L_TDK_MLZ1608 | 1
R1,R2 | 5.1k | ~ | Resistor_SMD:R_0603_1608Metric | 2
R3 | 2k | ~ | Resistor_SMD:R_0603_1608Metric | 1
R4,R5 | 10k | ~ | Resistor_SMD:R_0603_1608Metric | 2
R6 | 240k | ~ | Resistor_SMD:R_0603_1608Metric | 1
R10 | 330k | ~ | Resistor_SMD:R_0603_1608Metric | 1
R11 | 1M | ~ | Resistor_SMD:R_0603_1608Metric | 1
R13,R14 | 4.7k | ~ | Resistor_SMD:R_0603_1608Metric | 2
R15 | 1k | ~ | Resistor_SMD:R_0603_1608Metric | 1
S1,S13,S14,S15,S16,S17,S18,S19,S20,S21,S22,S23,S24 | Keyswitch | ~ | ScottoKeebs_MX:MX_PCB_1.00u | 13 | x
SW1 | POWER-SWITCH | ~ | Button_Switch_SMD:SW_SPDT_PCM12 | 1
SW4 | RESET | ~ | Button_Switch_SMD:SW_SPST_B3U-1000P | 1
U2 | USBLC6-2SC6 | https://www.st.com/resource/en/datasheet/usblc6-2.pdf | ScottoKeebs_Components:ESD_SOT-23-6 | 1
U4 | BQ24040DSQR |  | BQ24040DSQR:SON40P200X200X80-11N | 1
U6 | MDBT50Q-1MV2 | https://www.raytac.com/download/index.php?index_id=43 | RF_Module:Raytac_MDBT50Q | 1
X1 | Q13FC1350000400 | https://www.lcsc.com/datasheet/lcsc_datasheet_2404180925_Seiko-Epson-Q13FC13500004_C32346.pdf | PCM_JLCPCB:FC-135R_L3.2-W1.5 | 1

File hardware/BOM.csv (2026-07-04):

Component | Qty per keyboard unit | Unit Cost (€) | Qty of components in line | Line Cost (€) | Notes | Vendor for non LCSC Parts
PCB fabrication (JLCPCB) | 1 | 5,11 € | 5 | 25,57 € | bare board; min order qty 5
PCB shipping | 1 | 8,35 € | 5 | 41,76 €
PCBA assembly + JLC-sourced parts | 1 | 21,67 € | 5 | 108,35 € | parts JLC populates — production/bom.csv
PCB customs duties & taxes | 1 | 6,21 € | 5 | 31,03 €
PCB order Total (Line) |  |  |  | 206,71 €
OLED 128x64 SSD1306 module | 1 | 3,53 € | 3 | 10,59 € | on-PCB, self-soldered | Amazon
(MX) switches (Akko Rosewood) | 13 | 0,44 € | 45 | 19,99 € | on-PCB, self-soldered | Amazon
JST XH 3-pin connector | 1 | 0,08 € | 100 | 8,19 € | on-PCB, self-soldered | Amazon
Encoder (608) ball bearing | 1 | 0,60 € | 10 | 5,99 € | off-PCB | Amazon
Encoder magnet (5*2 mm) | 1 | 0,07 € | 100 | 6,99 € | off-PCB | Amazon
LiPo battery 2000mAh | 1 | 11,00 € | 1 | 11,00 € | off-PCB | (2pin) Amazon
Enclosure + Keycaps + Encoder knob | 1 | 4,00 € | 1 | 4,00 € | 3D printed (ca. 150g)
Enclosure screws (M2*12) | 4 | 0,22 € | 25 | 5,40 € | ISO 14580 | Wuerth
Enclosure threaded inserts (M2*3) | 4 | 0,10 € | 100 | 9,90 € | for 3D printed enclosure | cnckitchen
TOTAL build cost (per unit) |  | 61,38 €

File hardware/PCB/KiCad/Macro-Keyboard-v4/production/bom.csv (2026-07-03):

Designator | Footprint | Quantity | Value | LCSC Part #
C1, C13, C2, C4, C5, C8 | 0603 | 6 | 10uF
C11, C12, C14, C15, C16, C3, C6, C7, C9 | 0603 | 9 | 0.1uF
D1, D13, D14, D15, D16, D17, D18, D19, D20, D21, D22, D23, D24 | Diode_SOD-123 | 13 | Diode | C81598
IC1 | SOIC127P600X175-8N | 1 | AS5600-ASOT | C79815
JUSB1 | USB_C_Receptacle_GCT_USB4105-xx-A_16P_TopMnt_Horizontal | 1 | USB_C_Receptacle_USB2.0 | C165948
L1 | L_TDK_MLZ1608 | 1 | 10 µH, ≥ 80 mA
R1, R2 | 0603 | 2 | 5.1k
R10 | 0603 | 1 | 330k
R11 | 0603 | 1 | 1M
R13, R14 | 0603 | 2 | 4.7k
R15 | 0603 | 1 | 1k
R3 | 0603 | 1 | 2k
R4, R5 | 0603 | 2 | 10k
R6 | 0603 | 1 | 240k
SW1 | SW_SPDT_PCM12 | 1 | POWER-SWITCH
SW4 | SW_SPST_B3U-1000P | 1 | RESET | C720477
U2 | ESD_SOT-23-6 | 1 | USBLC6-2SC6 | C2827654
U4 | SON40P200X200X80-11N | 1 | BQ24040DSQR
U6 | Raytac_MDBT50Q | 1 | MDBT50Q-1MV2
X1 | FC-135R_L3.2-W1.5 | 1 | Q13FC1350000400 | C32346

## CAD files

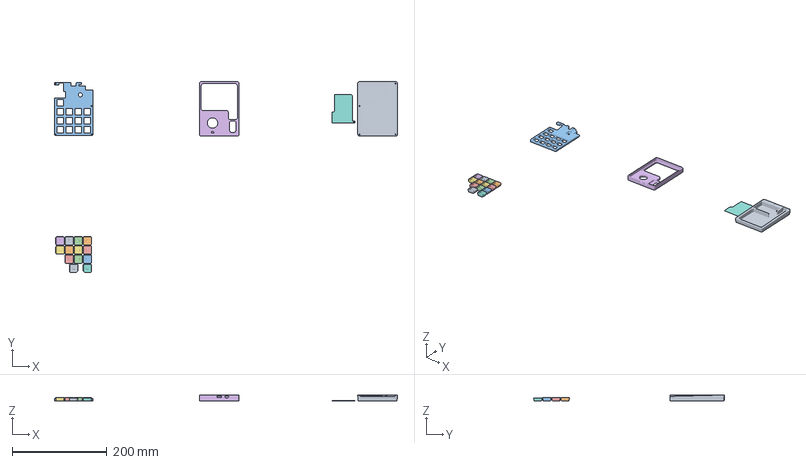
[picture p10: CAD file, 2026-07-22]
hardware/CASE/macro_keyboard_v4.3mf
723.9 x 402.7 x 12.9 mm
BOTTOM.obj
Körper5.obj x 11
SWITCHPLATE.obj
TOP.obj
BATTERYCOVER.obj
Körper1.obj x 2

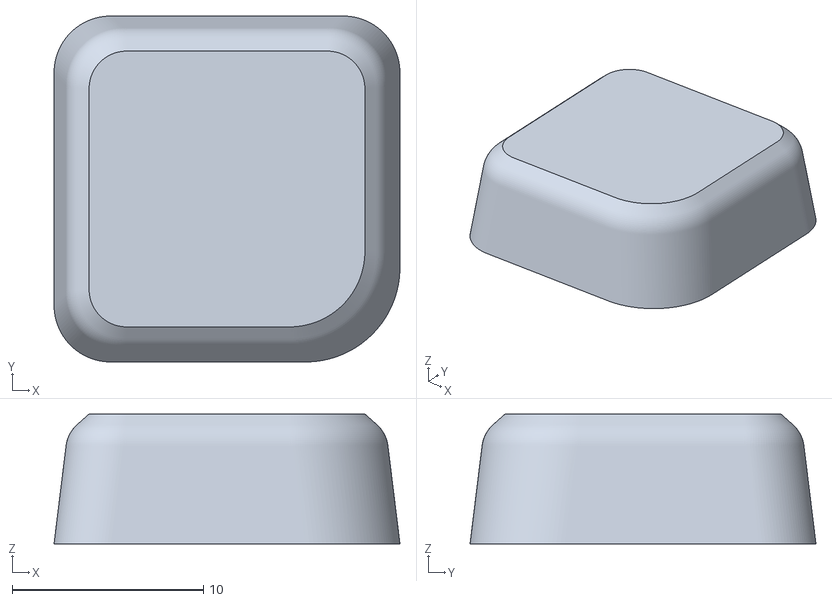
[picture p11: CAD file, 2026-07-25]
hardware/CASE/meshes/keycap-corner-right.obj
18.1 x 18.1 x 6.80

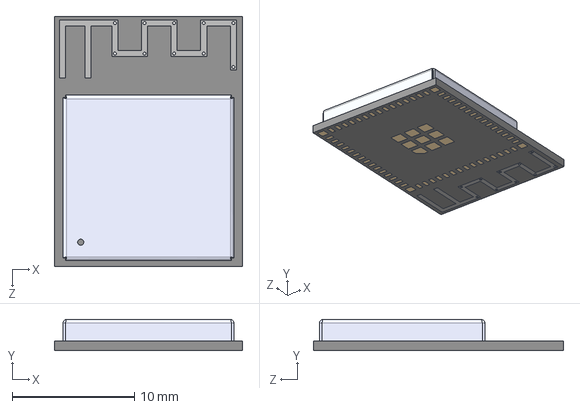
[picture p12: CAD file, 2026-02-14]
hardware/DATASHEETS:DATA/ESP32_S3_MINI_1_N8/ESP32-S3-MINI-1-N8.step
15.4 x 2.55 x 20.5 mm

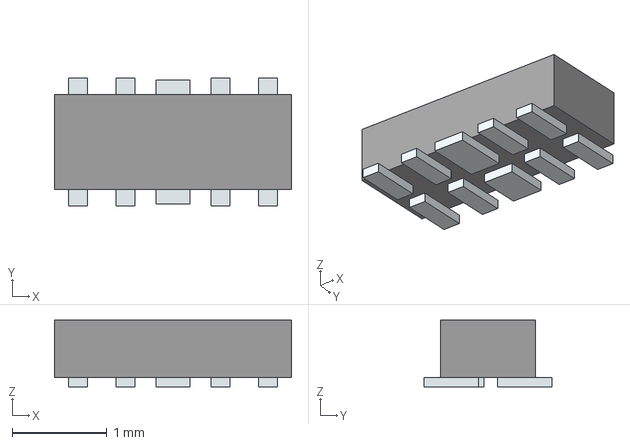
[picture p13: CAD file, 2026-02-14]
hardware/DATASHEETS:DATA/LIB_D3V3XA4B10LP-7/3D_MODEL_D3V3XA4B10LP-7.stp
2.50 x 1.35 x 0.705 mm
Pins

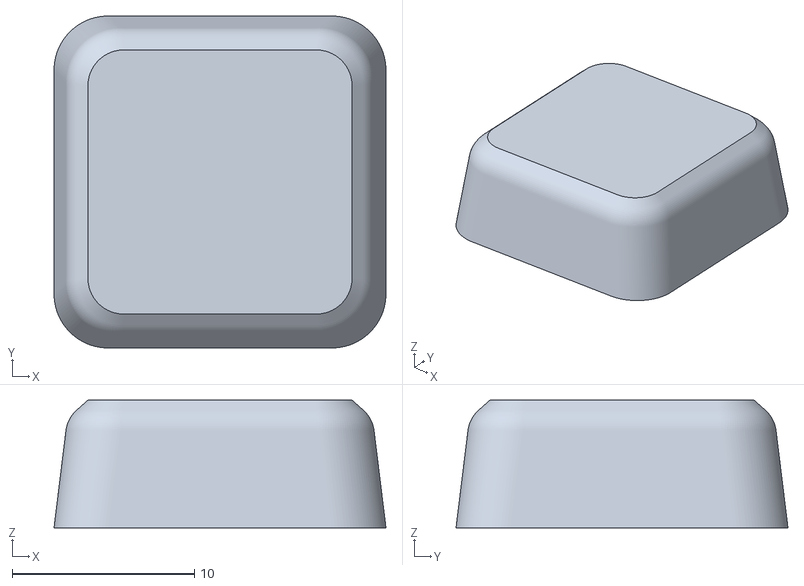
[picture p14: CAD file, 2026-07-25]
hardware/CASE/meshes/keycap.obj
18.2 x 18.2 x 7.00

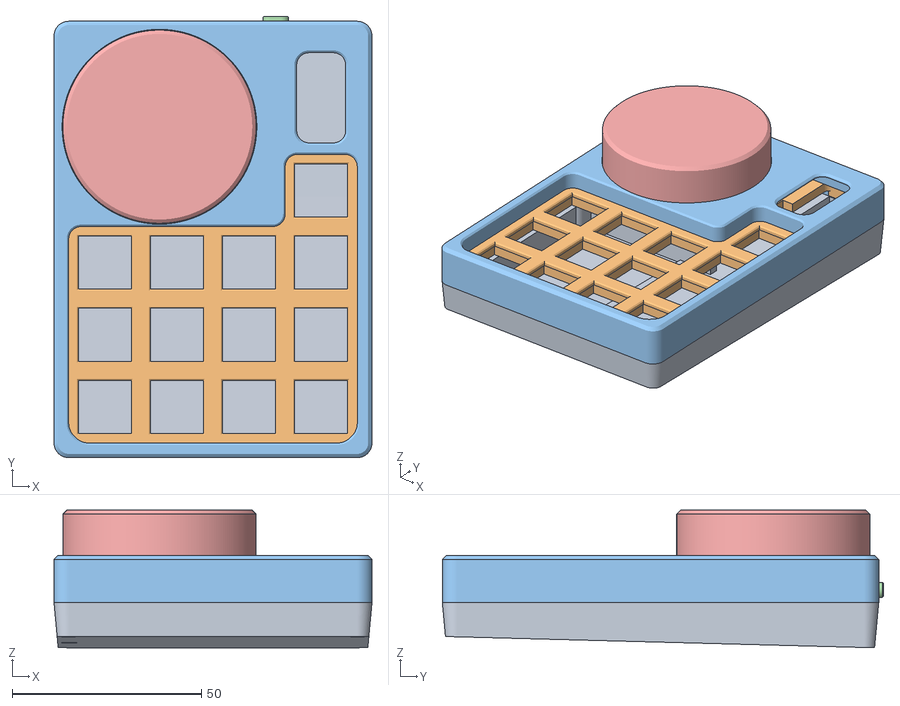
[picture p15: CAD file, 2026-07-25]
hardware/CASE/meshes/enclosure+knob.obj
84.0 x 116.5 x 36.3
BOTTOM
SWITCHPLATE
TOP
POWER-SWITCH
WHEEL

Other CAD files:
hardware/CASE/meshes/keycap-corner-left.obj

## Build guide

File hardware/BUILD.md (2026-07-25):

# Build & Assembly Guide

Full instructions to build one Macro Keyboard from scratch.

This guide is for the enclosure version #1 with PCB version #4 of the PCB (v4.1).
This PCB version currently has 2 major issues, which will be resolved in a future revision,
which is not released currently - this guide will help you fix these issues.
If you can wait on a revision (whose release date is not guaranteed), I would, because the
fixes are not beautiful.

## 1. Parts & tools

**Parts:** source full list in [BOM.csv](./BOM.csv); (on-PCB component list under [BOM_PCB.csv](./BOM_PCB.csv))

**Tools**
- for enclosure fabrication: 3D printer
- for soldering: soldering iron + solder + solder mat (+ flux + soldering wick)
- for assembly: TX6 screw driver (for screws) (+ double sided tape) 
- for first bootloader install: SWD programmer (DAPLink/pyOCD) or JTAG with [Cortex Debug (10-pin) connector](https://developer.arm.com/documentation/101416/0100/Hardware-Description/Target-Interfaces/Cortex-Debug--10-pin-)
- for alignment of the SwitchPlate: 4 M2 nuts

## 2. Order the PCB

Read up a little on PCB manufacturing so you know what PCBs are, which manufacturer 
to choose, and what settings to specify when you order the PCBs.
I used JLCPCB because they also offer a PCBA service with components that I can either 
send to them or have sourced directly from their LCSC warehouse, which makes it easy 
to select parts and have them assembled right away.

You can also assemble the components yourself, but I didn’t dare to do it because the
SMD components often have very small pads and it’s easy to damage them. Besides the risk,
there’s little point in doing it yourself because it isn’t significantly cheaper.

1. Fabrication files: Gerbers are under [production/Macro-Keyboard-v4.zip](./PCB/KiCad/Macro-Keyboard-v4/production/);
                      `bom.csv` and `positions.csv` for PCBA are under [production/](./PCB/KiCad/Macro-Keyboard-v4/production/)
                      
2. Upload Gerbers to JLCPCB; choose board options - the Gerbers usually carry the relevant information on the PCB,
like size, layer count, via positions, etc. Check that the layer count is set to 4 and the manufacturer can support
the required tolerances and other parameters with the selected service. - The manufacturer usually provides these
under their capabilities (have a look at there website).
My PCBs were manufactured without any problems by JLCPCB.

3. For SMT assembly, submit the parts in [bom.csv](./PCB/KiCad/Macro-Keyboard-v4/production/bom.csv) 
with the positions file. 
I checked that in this BOM only the parts to be populated are included, but checking again doesn't hurt.
So if you notice (for example), that mx key switches are included, take them out.
The parts, that should not be populated and are on the PCB, are marked as DNP (do not populate) in the
[BOM_PCB.csv](./BOM_PCB.csv): key switches, OLED display, JST connector for LiPo
Pic the top side of the PCB to be populated, check the capabilities of the SMT assembly service of your
manufacturer and then you should be good to go.

## 3. Print the enclosure + knob + keycaps

Case files: [CASE/](./CASE/)
There you can find the mesh exports (as .obj files) from CAD, the Autodesk Fusion source (my CAD program of choice) 
and my Bambu Studio project (if you wonder how to rotate the parts).
The enclosure is designed for FDM 3D printing.

Material:
I would recommend PETG for the Switch-Plate, because it needs to be more flexible then the rest of the enclosure
Everything else of the enclosure can be printed in every other rigid filament of your choice. I used PLA.

Print Bed:
I would recommend a smooth print bed for the surfaces of the prints.

In terms of print settings:
Those are not parts, which need to withstand a lot of force, nor do they need to be the most dimensionally
accurate: I designed the parts with tolerances for my FDM 3D Printer (a Bambulab P1S). If yours needs different
tolerances you can adjust them in the Fusion Source either in the related sketch or by moving the face manually.

For the whole enclosure and knob there are no supports need, but I would recommend to add support to the TOP part
at the place in the attached picture.

Place supports, where the print is colored dark blue:
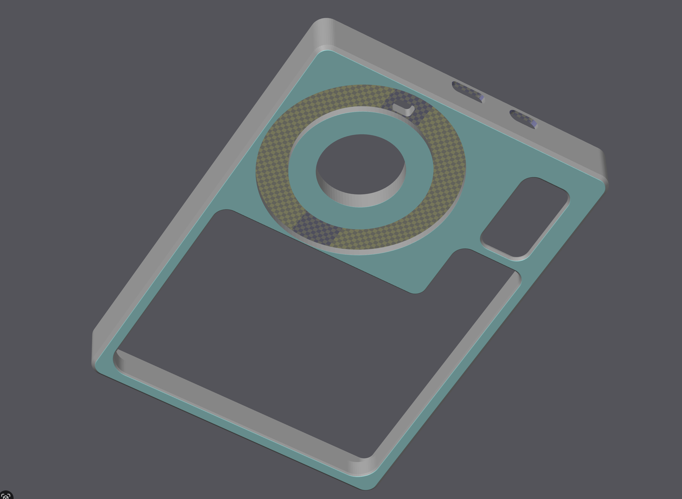
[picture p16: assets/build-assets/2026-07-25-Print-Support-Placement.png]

This is how it looks sliced:
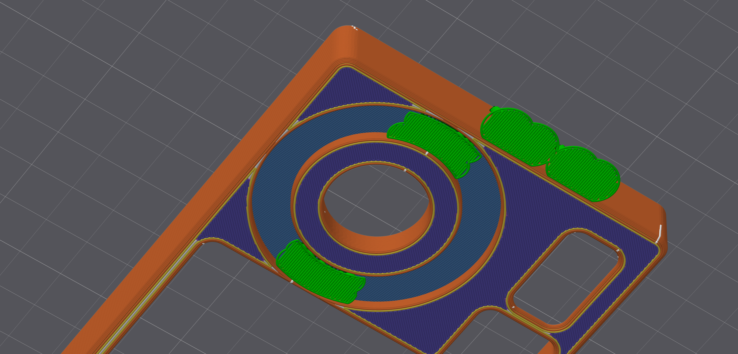
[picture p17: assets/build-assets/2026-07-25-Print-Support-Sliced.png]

This is how the part looks after the supports are removed:
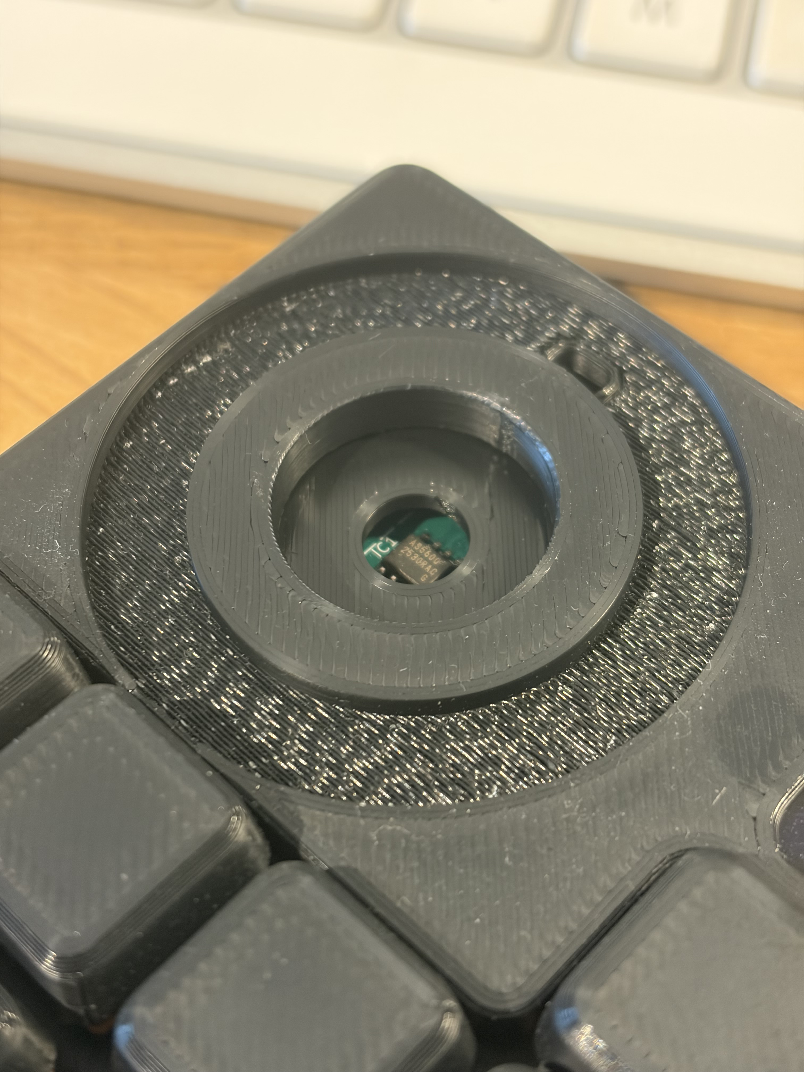
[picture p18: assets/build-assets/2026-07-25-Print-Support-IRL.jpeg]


Now Print the enclosure + knob + keycaps!

## 4. Assembly + Hand Soldering

All of the components are under the [BOM.csv](./BOM.csv). Make sure you have them, before you continue.

### Preparation: 
Before you can assemble the macro keyboard you need to
- install 4 threaded inserts into the TOP enclosure part.

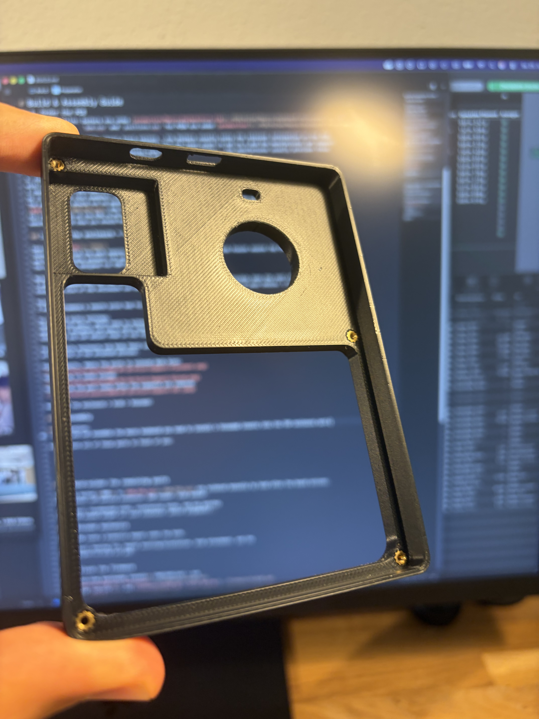
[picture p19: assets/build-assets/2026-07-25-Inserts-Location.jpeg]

- put the magnet into the slot of the knob + add the bearing.

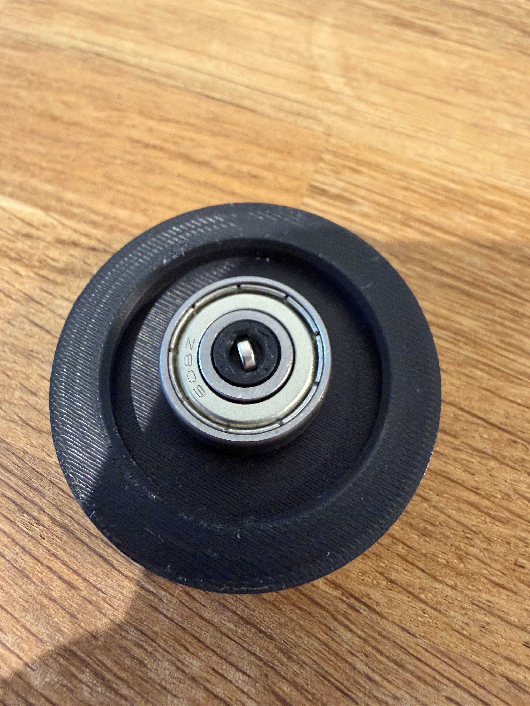
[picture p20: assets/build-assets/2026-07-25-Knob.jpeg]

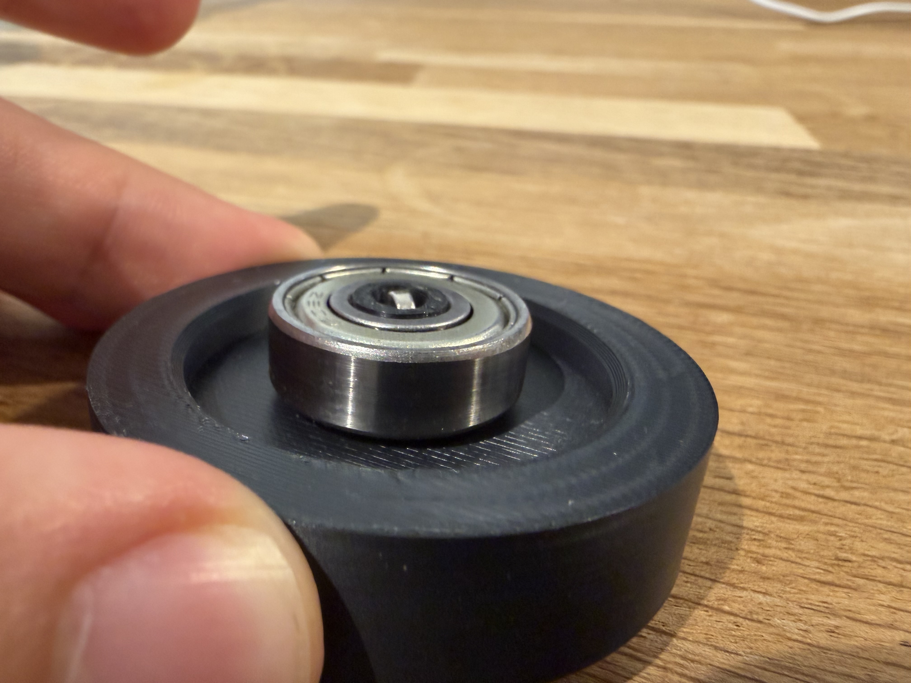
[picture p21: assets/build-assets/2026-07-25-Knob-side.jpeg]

- install double sided tape on the battery cover.

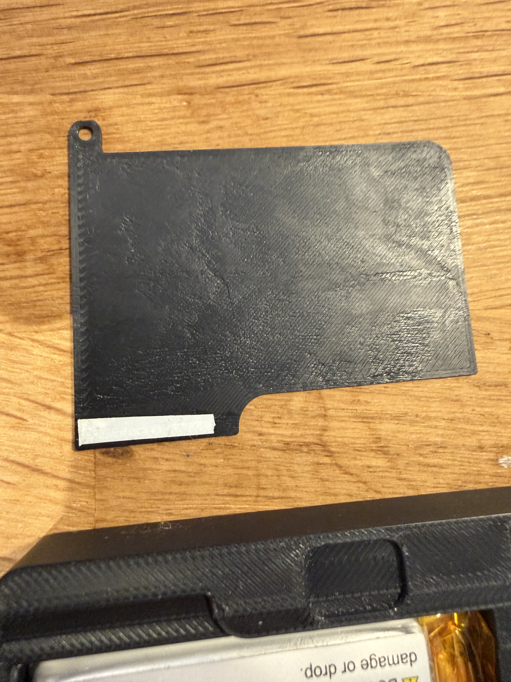
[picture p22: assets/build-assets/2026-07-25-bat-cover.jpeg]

- install double sided tape in the BOTTOM of the enclosure and put the battery in.

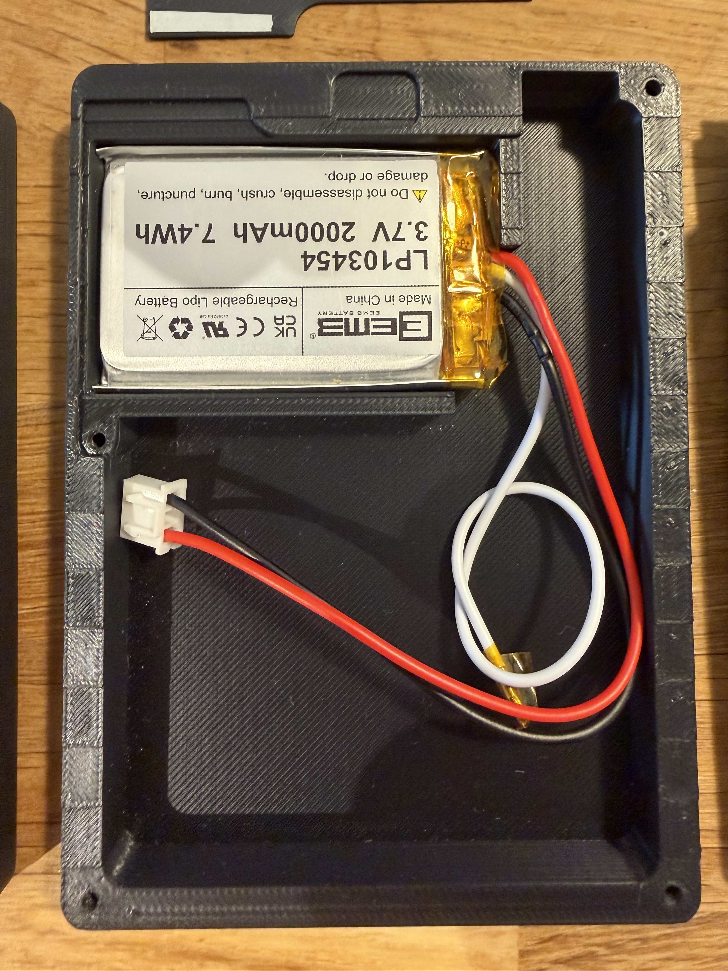
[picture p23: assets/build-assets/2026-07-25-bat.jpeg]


Now you have all of these parts in front of you:
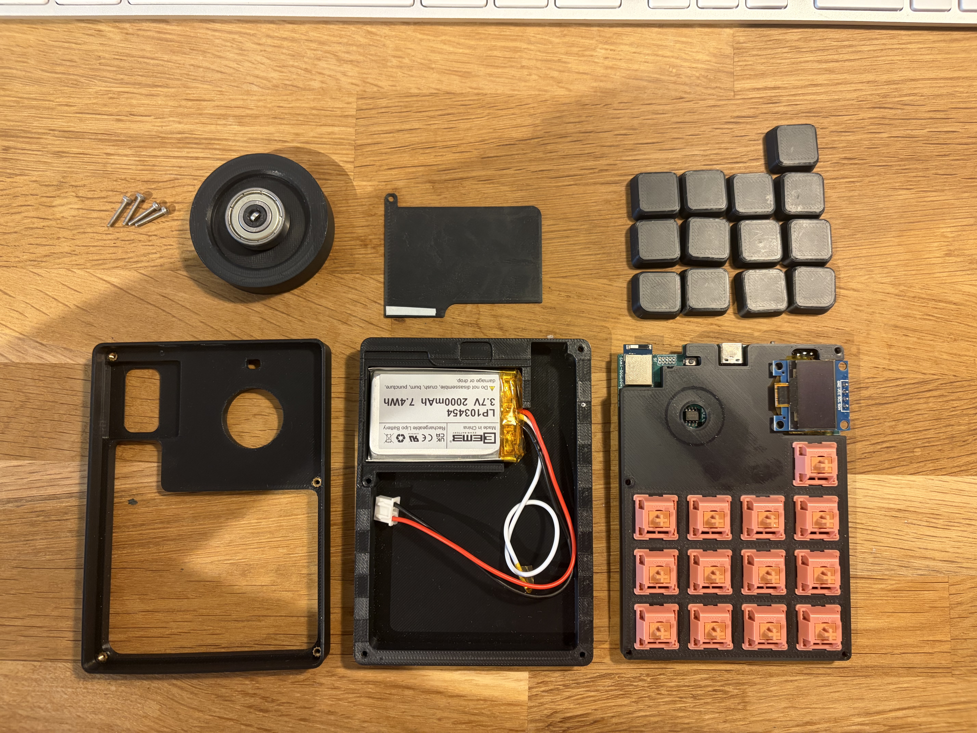
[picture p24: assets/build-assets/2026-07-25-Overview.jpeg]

(I already put the key switches and OLED display in place.)

### Hand soldering the remaining parts:
The parts marked **DNP** in [BOM_PCB.csv](./BOM_PCB.csv) are soldered manually by hand after the board arrives:
key switches, JST battery connector, SWD header, OLED module

Secure the SwitchPlate with 4 M2 nuts and make sure the Plate is aligned.
Then just pop in the Switches and solder them on from the backside of the PCB:

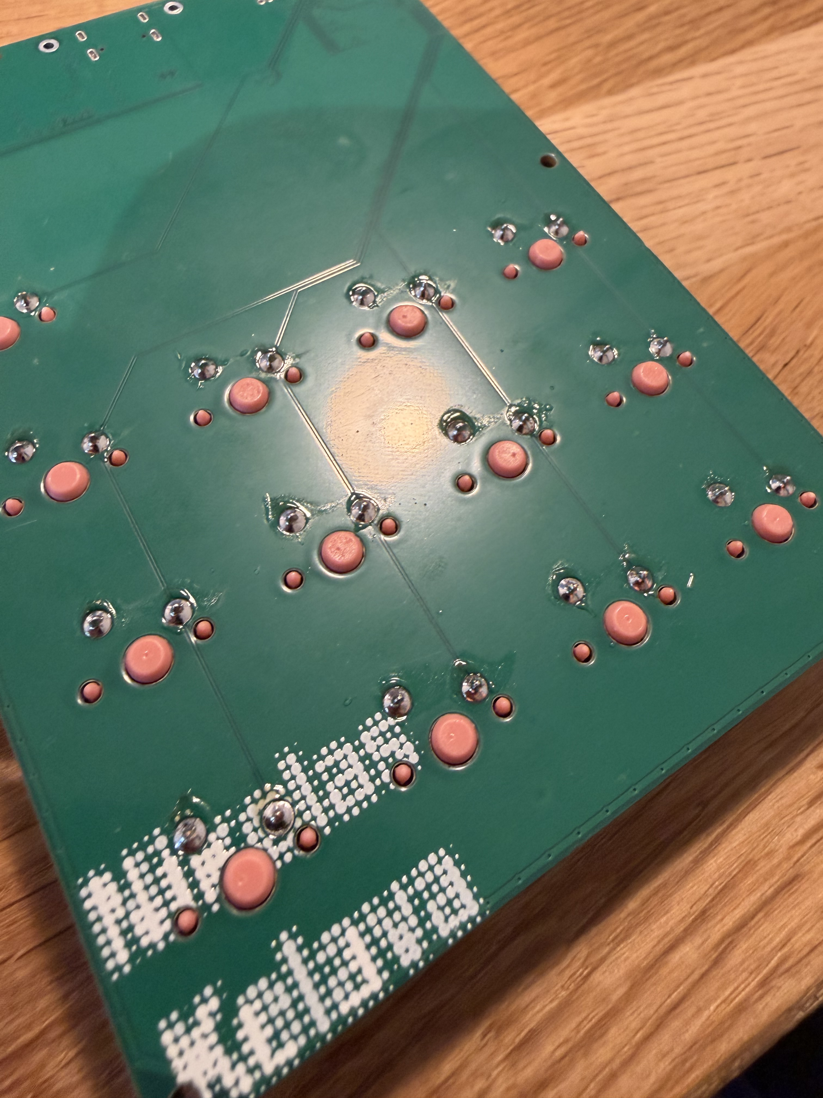
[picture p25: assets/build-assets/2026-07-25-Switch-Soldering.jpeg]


Put on the TOP of the enclosure and make sure the OLED is aligned: (When putting on the TOP, make sure to watch the power switch.)

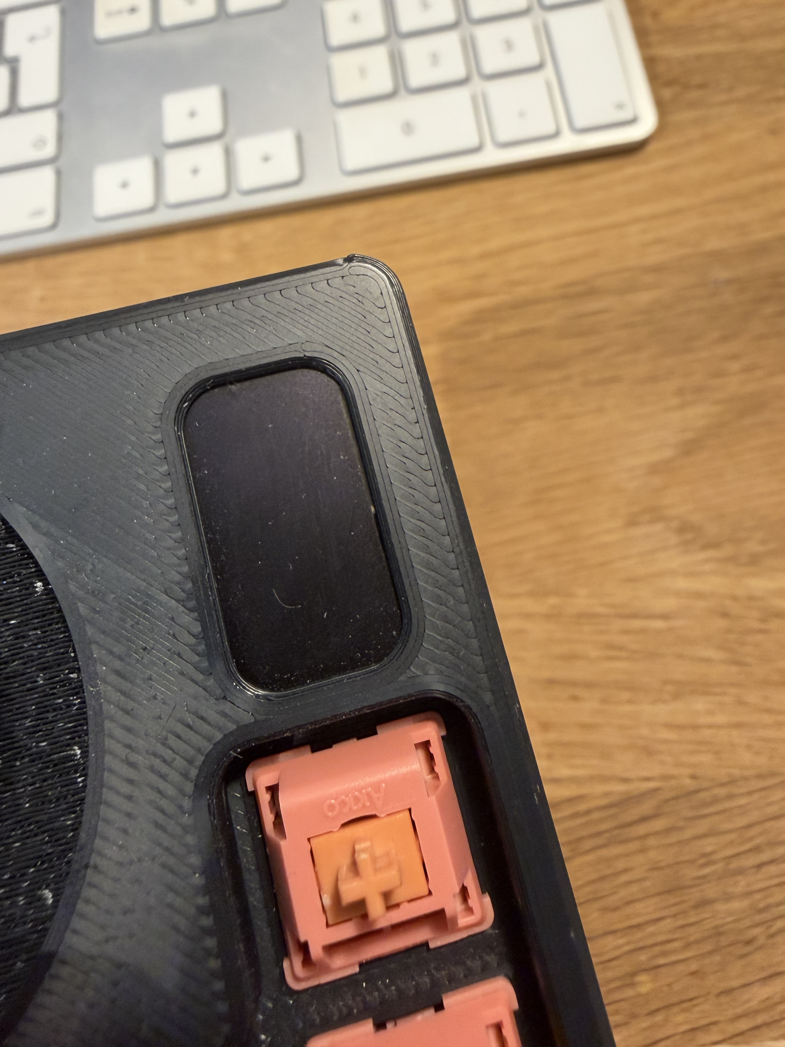
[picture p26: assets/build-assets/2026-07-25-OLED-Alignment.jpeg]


Solder the OLED.

Put in the JST connector on the bottom of the PCB and solder it.
But!!!! With the current version of the PCB, the JST XH2 connector has wrong polarity, because I forgot to flip
the blueprint in the PCB design! So what you will do is: Rotate the pins on the horizontal connector by 180°,
so when putting in the connector, it faces the right way into the PCB!!! (If you don't the polarity doesn't match
and you will notice it even before you get a short, because the connector would face outside of the PCB.)

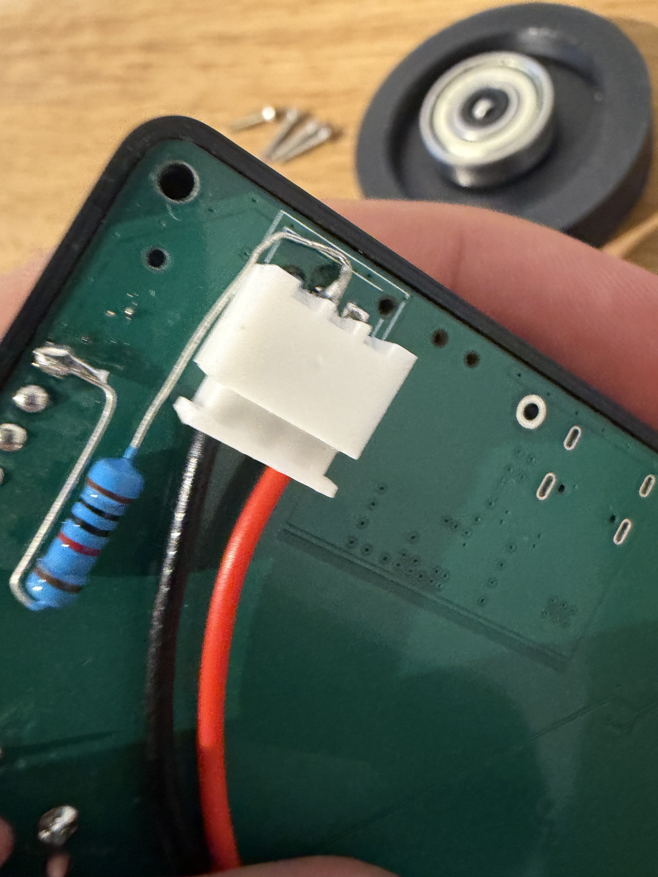
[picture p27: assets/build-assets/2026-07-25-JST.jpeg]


This is what it should look like.

I will release another version of the PCB, with 2 Fixes:
1. Moderate issue: "July 1: Fixed the LiPo not being charging" in JOURNAL.md
2. Plus the power delivery issue (brownout) that takes down the whole periphere of the PCB: OLED and AS5600 encoder

If I haven't removed this block, you will need to read the corresponding JOURNAL.md entry and it's fix.

### Assembly:

Put on the battery cover like so:

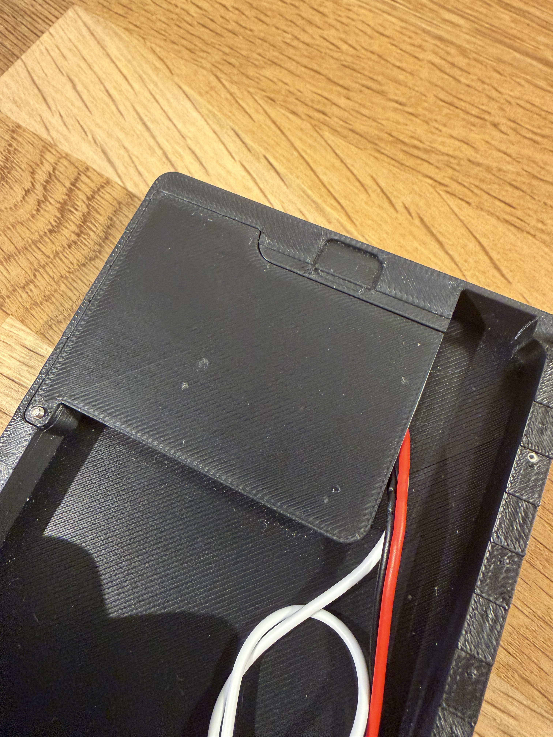
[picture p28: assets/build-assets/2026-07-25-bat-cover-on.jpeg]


Then connect the battery to the JST connector:



Then align the two halves of the enclosure as followed:

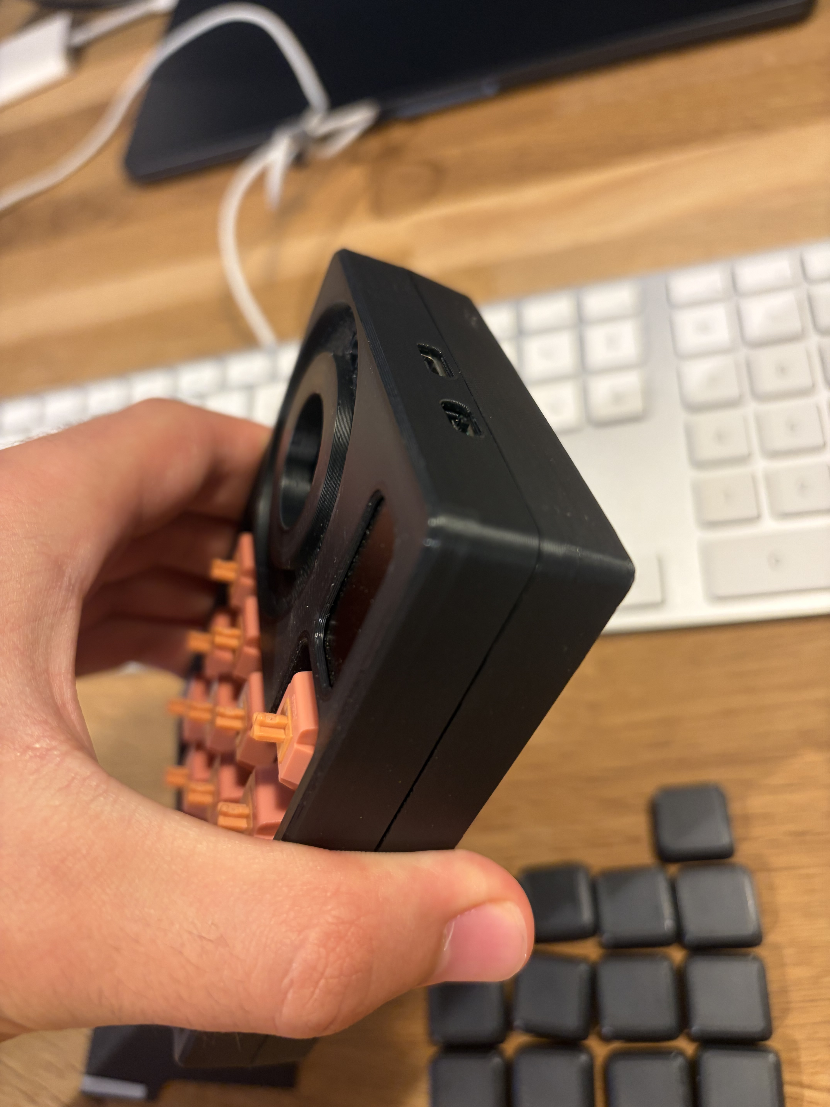
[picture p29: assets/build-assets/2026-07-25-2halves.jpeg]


Tighten down all 4 screws alternating:

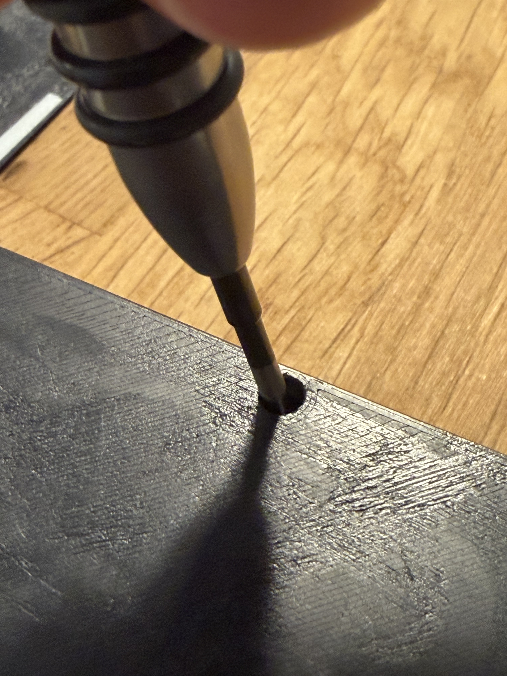
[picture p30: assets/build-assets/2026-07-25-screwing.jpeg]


Then you will be left with this:

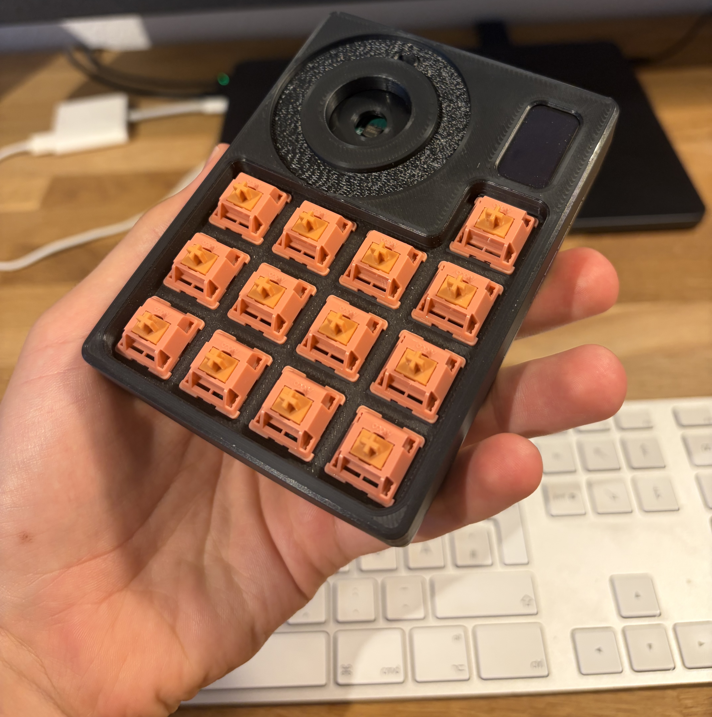
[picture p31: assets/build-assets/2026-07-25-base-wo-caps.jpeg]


Put on the keycaps:

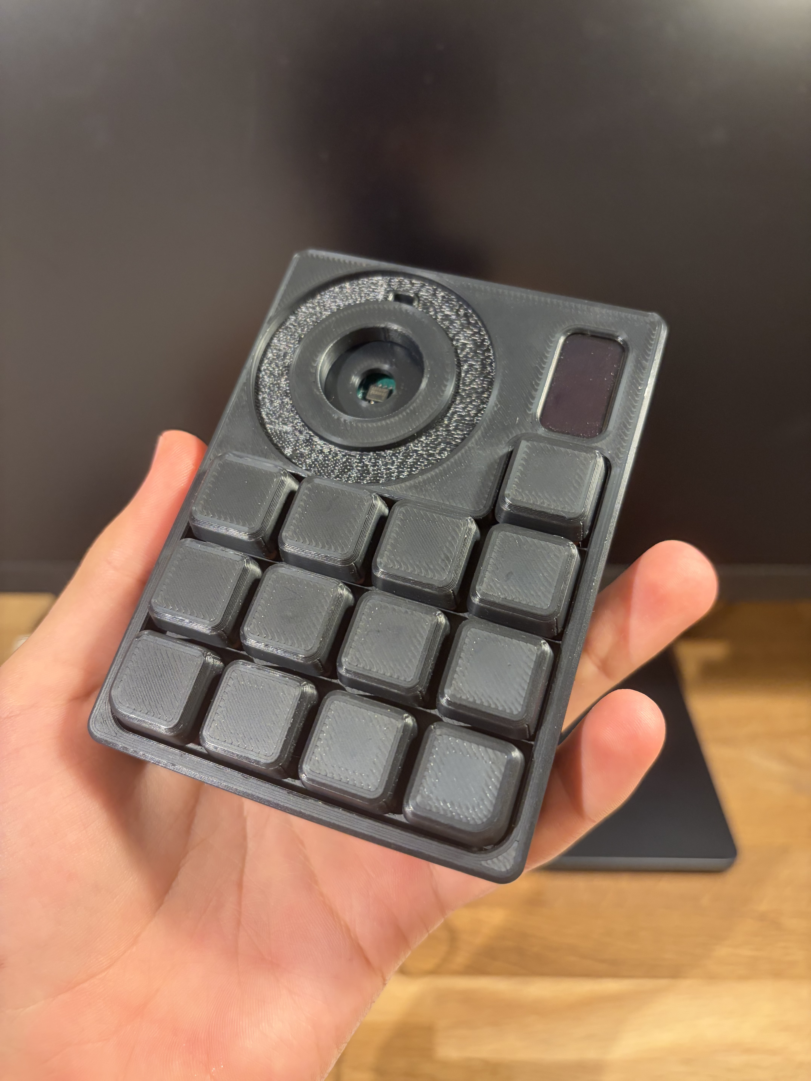
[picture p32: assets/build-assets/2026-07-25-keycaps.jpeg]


Press the knob into the enclosure and make sure the knob spins freely.

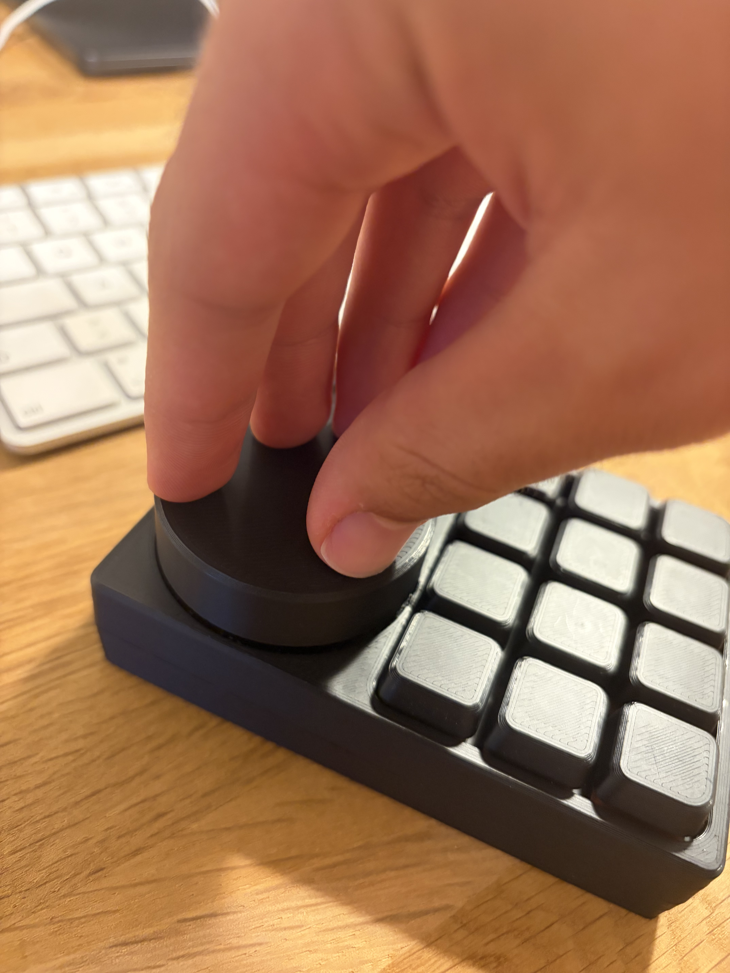
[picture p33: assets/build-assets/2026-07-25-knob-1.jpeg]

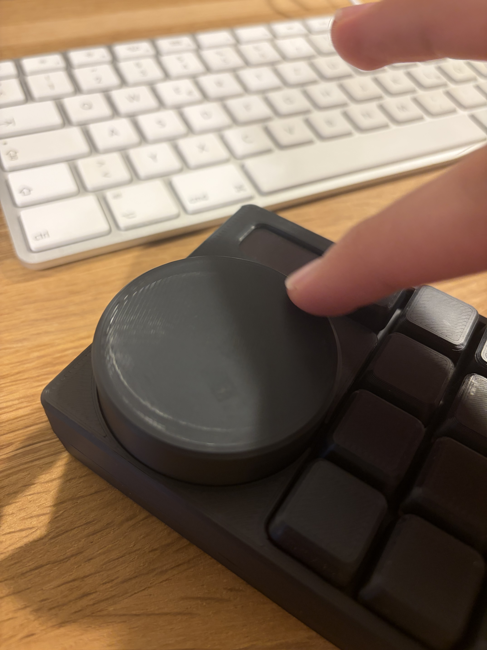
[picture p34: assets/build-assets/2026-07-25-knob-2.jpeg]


### Assembled:

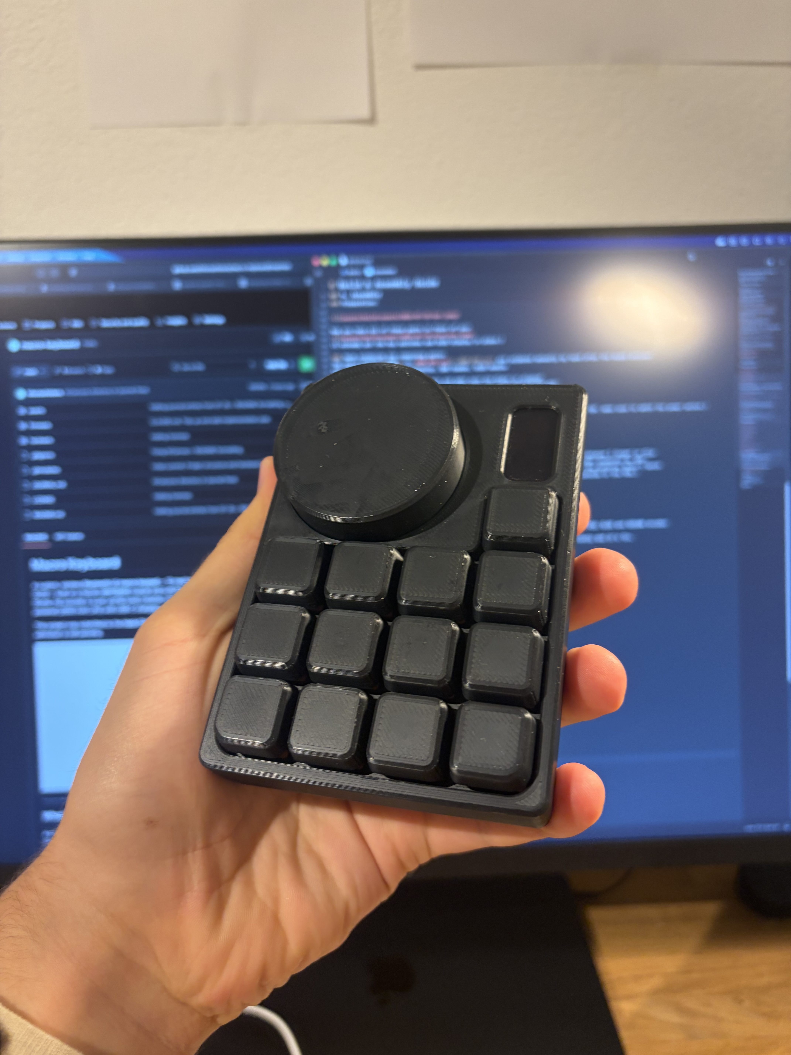
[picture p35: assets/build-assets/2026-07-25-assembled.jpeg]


## 5. Flash the firmware

### Notice:
- It can be that by the time you read this, that I have added the build artifacts for my firmware to GitHub.
  If so and you don't want to make your own modifications, you can just skip step #2 and flash the
  build artifacts I provide. 
  (Keymap can still be configured in ZMK Studio with studio version - default build will come without key assignments)

- I recommend to install the studio version as this firmware version makes configuring over ZMK Studio possible.

- Use whatever flashing protocol and program is supported by your debugger. With my DAPLink Debugger I use pyocd via SWD, which I conveniently installed into the venv of my local toolchain.
  This guide will be written for pyocd.

- I would recommend to install the UF2 bootloader as it will make your life easier later. If you ever need to update the firmware on the board later, you won't need to flash over SWD again.
  If you don't want to install a bootloader and want to flash the firmware directly with your debugger, read the section in [firmware/CLAUDE.md → Bootloader](../firmware/CLAUDE.md) "If the bootloader has to be removed".

- Follow the official [ZMK firmware document](https://zmk.dev/docs/development/local-toolchain/setup) on setting up the local Zephyr toolchain to build the ZMK firmware with macro_keyboard config. Install the current version of ZMK, which is added as a submodule to this repo. Install under the path `firmware/zmk_toolchain/`.

### 1. **First-time bootloader install** (SWD/DAPLink with pyocd):
(also in [firmware/CLAUDE.md → Bootloader](../firmware/CLAUDE.md).)

A UF2 bootloader (Adafruit_nRF52_Bootloader, MDBT50Q-1MV2 build) is the default flashing target. The binary lives at `firmware/bootloader/macro_keyboard_bootloader.hex`.

The build is wired for it by default — see `macro_keyboard_defconfig`:

```
CONFIG_USE_DT_CODE_PARTITION=y       (links app at code_partition = 0x26000)
CONFIG_BUILD_OUTPUT_UF2=y             (emits zmk.uf2)
CONFIG_BUILD_OUTPUT_UF2_FAMILY_ID="0xADA52840"   (Adafruit nRF52840 family ID)
```
**Bootloader install / re-install** (one-time, via SWD/DAPLink and pyocd):

Connect the debugger probe (you will need to take of the TOP of the enclosure) by pressing in the 10 pins of your probe into the 10 pins of the PCB (beside the MCU). Make sure to connect from the upper-side of the PCB and the direction of the connector will need to face inside the PCB.

Then run: (before you can "pyocd list" to list the debug probes with targets)

```bash
pyocd flash --target=nrf52840 \
  /Users/nikolaskelava/Documents/macro_keyboard/firmware/bootloader/macro_keyboard_bootloader.hex
```

After this, double-tapping reset mounts the USB MSC drive.

### 2.1 **Preparing the /config before building locally** with the toolchain:

If you choose the studio version, you don't need to configure the keymap in /config.

If you don't, you need to configure your keymap now, before you build.

### 2.2 **Build `zmk.uf2`**:
(also in [firmware/CLAUDE.md → Local Builds](../firmware/CLAUDE.md)
   or the [README build section](../README.md#firmware--build--flash))

Build (from `firmware/zmk_toolchain/app`, ZMK toolchain):

```bash
source /firmware/zmk_toolchain/.venv/bin/activate

west build -p -d build/macro_keyboard/m3 -b macro_keyboard -- \
  -DZMK_CONFIG="$PWD/../../zmk-config/config" \
  -DZMK_EXTRA_MODULES="$PWD/../../zmk-config/module"
```

Add `-S studio-rpc-usb-uart -DCONFIG_ZMK_STUDIO=y` for the ZMK Studio variant.
The build emits both `zmk.uf2` (drag-drop) and `zmk.hex` (SWD via `west flash -r pyocd`).

### 3.1 **Flash with UF2**:

Take off the knob and double-tap reset (mounts as `NRF52BOOT`) and drag `zmk.uf2` onto it.

### 3.2 The board will be dismounted and **boot into the firmware**.

### (4.0 Install Mac Mouse Fix or Linear Mouse on macOS:)
    With the current config the macOS scroll acceleration, which is applied to all scroll wheels, is awful.
    If you want to use scrolling, you can fix it by:
    1. Installing a 3rd party application like "Linear Mouse" to take out the scroll acceleration. But Linear Mouse will do so by applying a fixed step size per tick. This means that you wont be able to scroll as precisely.
    2. If you don't want any 3rd party app intersecting: In the /config you can configure the keymap node: scroll-triggers-per-rotation = <120>; to a lower trigger count. But this means, that it will also get less smooth.
    3. I landed on the application "Mac Mouse Fix". It works as expected by removing the scroll acceleration and enabling smooth scrolling multiplier.

## 6. Verify

- OLED shows battery + connection type on boot.
- Pair over BLE (or plug USB); the host sees an HID keyboard.
- Each of the 12 keys registers on the host.
- The encoder acts on the active profile's mode (volume / scroll / tabs).
- The profile button cycles profiles; the mode key cycles encoder modes. - with default setup.
- Battery %/charging indicator responds to USB plug/unplug.

- If you have installed the studio version:
  Plugin the macro keyboard via USB, go to zmk.studio, configure the keymap, upload it to the board and verify that the
  key presses execute the macros you configured.

## Safety

See [README → Safety notes](../README.md#safety-notes) — LiPo handling, 3.3 V
logic, USB-C power.

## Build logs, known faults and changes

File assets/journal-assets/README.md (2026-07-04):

# Journal images

Drop images referenced from [../JOURNAL.md](../JOURNAL.md) here.
Name them by date + topic, e.g. `2026-07-02-oled-battery-icon.jpg`, so they stay ordered.

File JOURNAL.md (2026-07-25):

---
title: Macro Keyboard
author: Nikolas Kelava
description: A custom, wireless Bluetooth LE macro keypad (12 keys + magnetic rotary encoder + OLED) built on an RF52840 module and running ZMK!
created_at: 2026-05-23 (Start of this devlog)
---

Devlog for my **Hack Club Horizons** hardware submission: a custom, wireless Bluetooth LE
macro keypad (12 keys + magnetic rotary encoder + OLED) built on an nRF52840
module and running ZMK.

Time is tracked with **Hackatime** (Wakatime → Hackatime) for firmware work since May.
Hardware/CAD/research sessions are recorded as **timelapses** (Lapse) and linked
per entry, since Lookout isn't supported for Horizons yet.

I actually started this project more than a year ago, and I've been documenting it the whole way — just not
in JOURNAL.md form. This file pulls all of that together into one devlog. It starts on May 23 because that's
the day I began tracking my time with Hackatime; plenty happened before then, I just wasn't logging the hours.

A few of these entries cover a work session that ran across more than one day — in that case the date is the
day the session wrapped up. 
To support me with much of the firmware work, especially debugging, I used Claude Code.
For the entries in which Claude Code was used, I placed the Claude code session name beneath the entry heading;
it doubles as the Git commit name for that chunk of work.

## Entries

#### May 23: Shorted my debugger probe - not my proudest journal entry

Back then I flashed firmware (M3) over SWD with a DAPLink probe instead of the UF2 bootloader (I moved to the
bootloader afterwards). Cortex-M 10-pin connector, pyocd, nothing fancy.

So one day I do the exact same thing I always do: connect the probe to the macro keyboard, kick off pyocd,
and... the progress bar just sits there and doesn't advance. No big deal — I unplug the probe, plug it back in,
re-run pyocd, and flash again.

And then the debugger probe starts smoking and then the little activity light that tells you something's happening 
just goes dark.

So what happened? Nothing was different from every other time I'd flashed this thing. The only way to
physically cook the probe like that is a mismatch on the connector pads. So I pulled up the schematic and
went pin by pin — the on-PCB connector vs. the probe's connector.

And then it hit me: I'd plugged the connector in from the *other* side of the PCB. Mirrored.
I did that because I couldn't reach the other side - and I just didn't think through that this 10 pin connector with
specific pins is not reversible like a USB port...

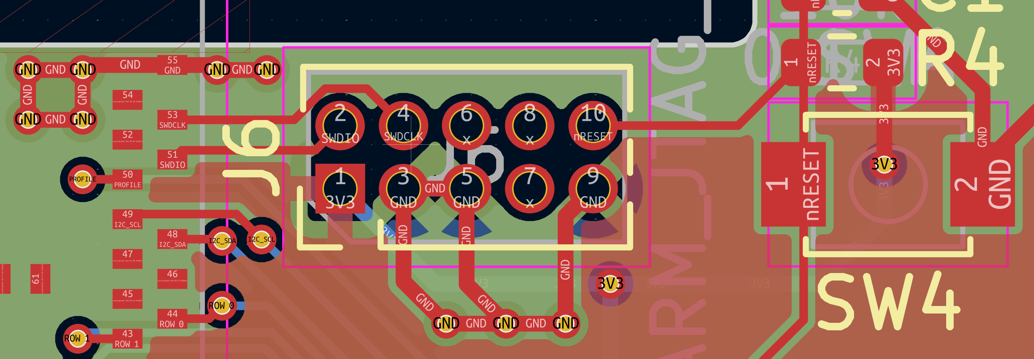
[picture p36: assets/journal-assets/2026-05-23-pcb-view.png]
The actual orientation the connector should go in


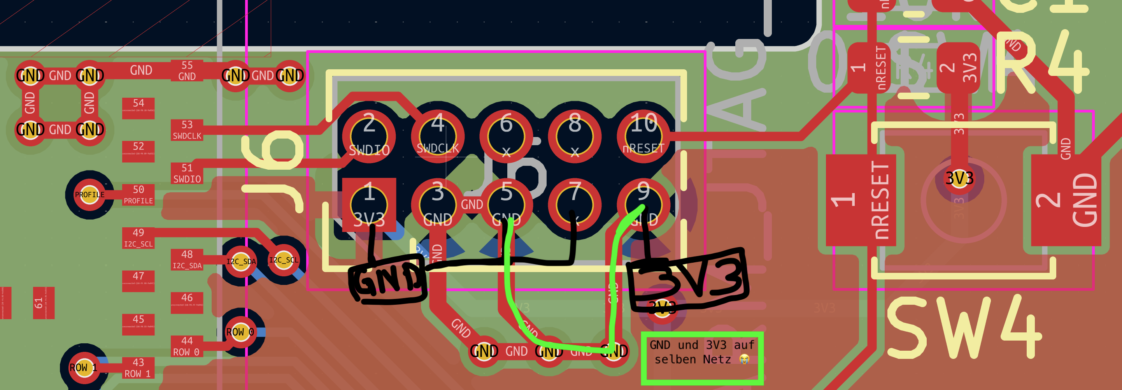
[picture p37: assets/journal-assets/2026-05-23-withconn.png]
Schematic with the mismatched nets marked in my handwriting


In the schematic you can see the nets that were *supposed* to line up, and (in my handwriting) the nets that
actually got connected once the plug was flipped around. Ground and 3V3 ended up on the same net → dead short
straight through the probe. Hence the smoke.

I reordered the debugger probe on amazon for 5€, so it could have been worse than just my probe shorting. If I 
shorted the keypad or (worse) my mac, this would have been WAY worse. It's still very embarrassing.

**tl;dr:** Flashed over SWD like always, but plugged the 10-pin Cortex-M connector in mirrored (from the wrong
side of the PCB). That put GND and 3V3 on the same net, shorted the probe, and let the debugger smoke. For the
future I will make sure to pay attention to the correct orientation of connectors.

**Time spent this session: 1.5 hours**

#### May 28: The OLED lights up, and takes Bluetooth down with it

*Milestone 4; Claude Code session: "Milestone 4: BUILT_IN screen"*

This was supposed to be the fun milestone: Turn the screen on, draw a status UI, done. Instead I learned that
on this board the display and the radio share a lifeline, and if you mess up the display the whole keyboard
will be messed up too.

Some context: the OLED bus had been switched off at the config level for a while because of an unrelated
power-delivery problem (Journal entry before this one) on the hardware side. That was finally sorted, so the plan 
was to bring the display up in firmware — in two steps. First get ZMK's *stock* status screen rendering, so that 
any problem is clearly the bus or the LVGL setup and not my own screen code. Then swap in my custom screen. 
Good call, because step one alone took two rounds.

**Quick explainer on what's actually stacked up behind this screen**, because "the display" is really four things
and every bug in this entry comes from different one:

- **The panel** — a 128×64 SSD1306 OLED, monochrome, talking over I2C. Monochrome here means *one bit per pixel*:
  a pixel is lit or it isn't, there is no grey. It's also addressed in 8-pixel-tall horizontal "pages" rather
  than row by row, which turns out to be a useful diagnostic later.
- **The Zephyr display driver** — knows how to push a buffer of pixels into that panel over I2C.
- **LVGL** — the graphics library that does the actual drawing (labels, boxes, fonts) into a buffer, then hands
  finished rectangles to the driver in what's called a *flush*.
- **ZMK's display layer** — decides *what* to draw: it defines a status screen and a set of widgets, and runs the
  whole thing on a **work queue** (a queue of jobs handled by a background thread).

That last word is the one to remember. By default the display's work runs on the *system* work queue — which is
the same queue ZMK uses for Bluetooth advertising and USB-HID transmits. Everything in Act 1 follows from that.

**Act 1: the screen lights up and shows TV static.**

I flipped `CONFIG_ZMK_DISPLAY` back on with the built-in screen, built it and flashed it. The OLED lit up and showed
pure snow. It was actual static, reshuffling artifacting (or idk how to call it) on every power cycle. Even worse was,
the board was dead with no USB enumeration, no Bluetooth advertising. Additionally my Mac started cooking itself, 
because the bad USB ejection left a couple of macOS processes running.

gif - hope it works

This is what the artifacting looked like on screen: 

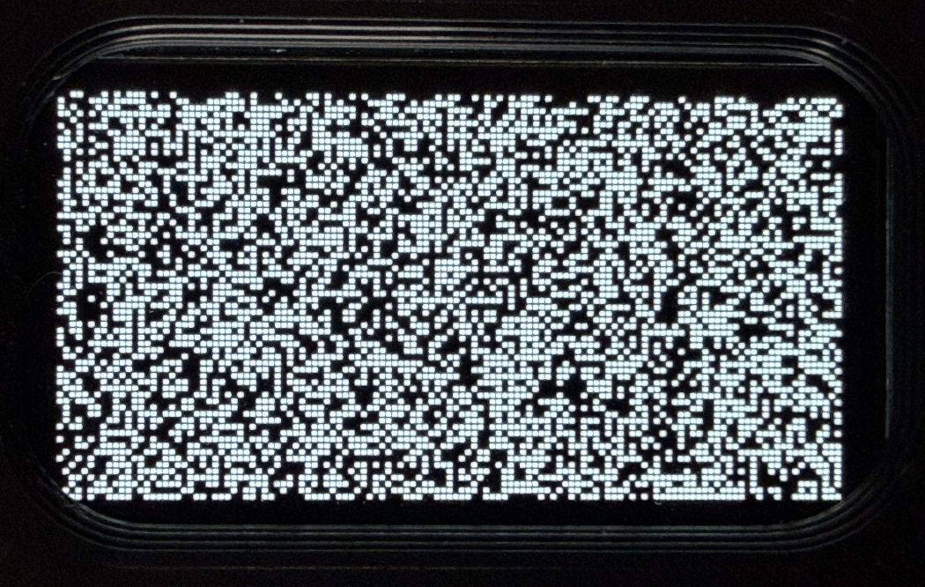
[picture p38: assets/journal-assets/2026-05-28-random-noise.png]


So what makes a 1bpp OLED show static *and* take the whole board down with it? Claude and I went through the
generated `.config`, and the problem was near the top:

```
CONFIG_LV_COLOR_DEPTH=16
CONFIG_LV_Z_BITS_PER_PIXEL=32
```

The panel is a monochrome SSD1306 — **one bit per pixel**. Zephyr's LVGL glue defaults to RGB565 at 32 bits per
pixel. Two things fall out of that single mismatch:

1. LVGL hands the SSD1306 driver fat 16-bit colour words, the driver writes them into display memory as raw
   bytes, and every "colour" becomes 16 unrelated pixels. That's the snow.
2. A 32bpp framebuffer for 128×64 is about 32 KB, roughly eight times the size of the LVGL memory pool. The
   first flush chokes on that — and it chokes *on the system work queue*, which is also where ZMK runs its
   Bluetooth advertising and USB-HID transmits. So the radio never got the chance to come up at all.

This doesn't only result in just a cosmetic problem, but it is a whole "your keyboard is now bricked" type problem,
because they ride the same queue. Very good.

Pinning the panel to 1bpp in the board's Kconfig is the fix — it's a property of the board, the OLED is soldered on,
and every upstream ZMK board with an SSD1306 does exactly this. Rebuilt both variants (I always build the plain one
*and* the ZMK Studio one, since a config change can pass one and break the other), flashed, and... still noise.

But the noise had *changed*. It was no longer full static, but it was organised into clean horizontal bands, 8 pixels
tall. The SSD1306 lays its memory out in 8-pixel-tall pages, so the panel was finally receiving structurally valid
1bpp data. LVGL just wasn't pushing a coherent frame yet. So Progress, not a win.

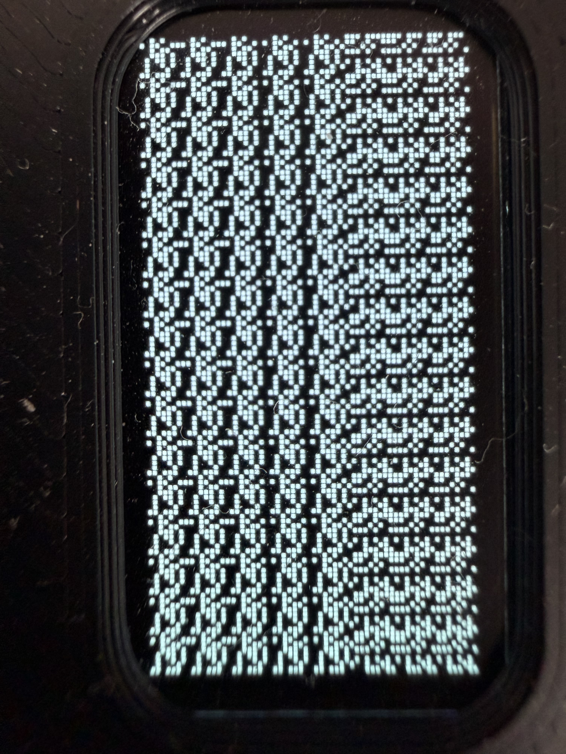
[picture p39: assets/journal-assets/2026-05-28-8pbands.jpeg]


Round two, two changes, both of which just bring my board in line with what the established 128×64 SSD1306 ZMK
boards already do:

1. Give the display its **own** work queue instead of sharing the system one
2. Bump the LVGL draw buffer from 10% to 64% of the screen. The tiny default puts out lots of little partial
   flushes, faster than the I2C bus can serve them, which starves the display queue.

Flashed it, and **the stock screen came up.** Connection icon with the paired-device count, active profile,
battery indicator. USB enumerated, Bluetooth paired, ZMK Studio saw the board. Both changes were needed.

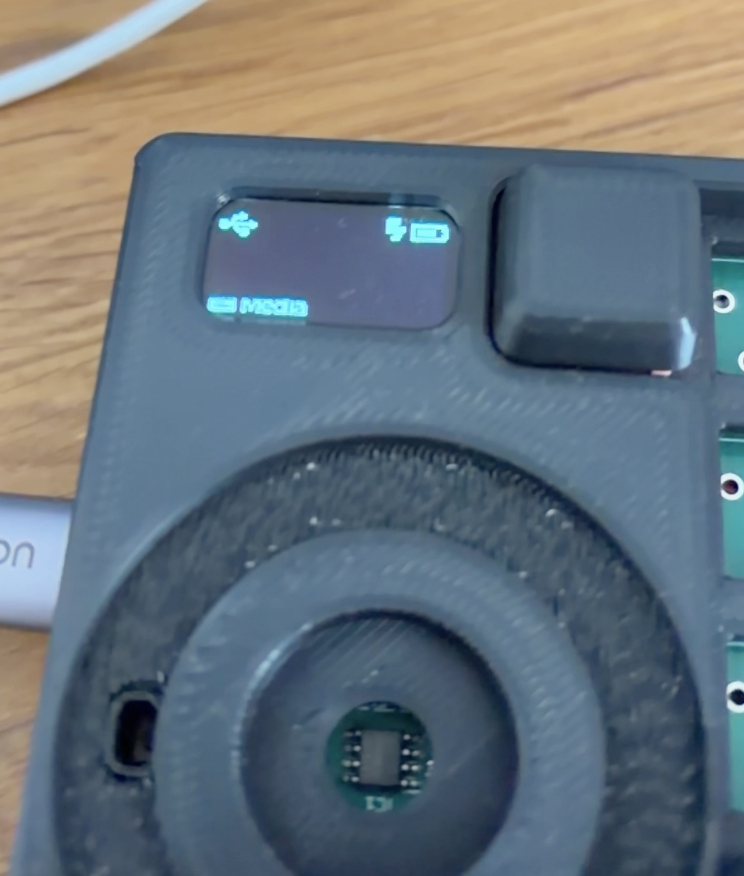
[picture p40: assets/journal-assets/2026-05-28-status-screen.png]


**Act 2: my own screen refuses to boot, and I lose (for now).**

The stock screen only really gives me battery plus the name of the current profile. What I want is all the
profiles at once with the active one highlighted.

One thing worth stating plainly here, since the rest of the journal leans on it: **a "profile" on this keyboard is
a ZMK layer.** ZMK keymaps are stacks of layers, each one its own set of key bindings, and my profile button just
activates the next one. So everything I call a profile — the boxes on the screen, the per-profile encoder mode,
the things Studio can add and delete later — is really a layer wearing a friendlier name. That's also why the
screen can just ask ZMK which layer is currently on top and trust the answer.

So I wrote the custom screen with this layout:
Battery top-right, four numbered slots/cells along the bottom, where the active slot inverted, refreshing whenever
the layer changes (because we can save some resources by not constantly checking change of state of particular
elements, but let the corresponding elements trigger a refresh). 

It built clean and flashed.

The static came straight back and the board was dead again. Yes of course.

Back into the config diff. The culprit this time looked obvious: choosing the *custom* screen silently drops a
pile of things the built-in screen quietly pulls in behind the scenes — specifically the mono theme and the
default font. Without the theme LVGL has no default font set, so the first text label renders against a null
font pointer and hardfaults. A hardfault takes the entire chip down, dedicated work queue or not, which is
exactly why Bluetooth and USB died alongside the display again.

So I pinned the theme and the fonts explicitly, and while I was in there fixed a polarity detail: this panel
reports its format such that LVGL "white" is actually an *off* pixel and "black" is a *lit* one, so my
inverted-slot colours were backwards. Confirmed in the compiled binary that the theme and both fonts were now
actually linked in. Built both variants, flashed —

And still static and still dead.

At that point I did the thing you do when you're sure and you're still wrong:  I stripped the screen down to the
absolute minimum:
create a screen, create one label and set its text, return. 
In the unlikely case that it boots, add pieces back one at a time until it breaks. And this basic screen with a
label still hung the board with a config that now matched the working built-in screen on every setting we'd found.

To be honest: I have no debug console wired to this board, so every hypothesis costs a full reflash-and-stare cycle 
with zero visibility into the actual fault.
Because it was already a long session, with a one-label screen still hanging and no obvious next suspect, the right
move wasn't to keep throwing firmware changes at it. So I reverted to the stock screen, which means I still have a 
fully working keyboard, and then wrote the entire state up for a Claude Code debugging session with every current
hypothesis and the config to reproduce it.

**tl;dr:** Brought the OLED up in firmware. The stock ZMK screen showed pure static and took USB + Bluetooth down
with it, because LVGL defaulted to 16/32-bit colour on a 1-bit panel and because the display shares a work queue
with the radio. Pinning the panel to 1bpp, giving the display its own work queue and enlarging the draw buffer got
the stock screen live and the board fully working. My *custom* screen still hardfaults at boot even stripped down
to a single label, so I stopped it with a full writeup and kept the working stock screen.

**Time spent this session: 12 hours**

#### May 29: The one Kconfig line I couldn't see

*Milestone 4 · Claude Code session: "Milestone 4: Custom screen"*

Picking up exactly where the last session died: the moment I flip to my custom status screen, the board hangs at
boot. The OLED shows 8-row-page garbage (that's just uninitialised display RAM), USB never enumerates, BLE never
advertises. And it does this *even with a minimal screen body*.

What made it so infuriating is that I'd already convinced myself the config was identical between the working
built-in screen and mine. Same mono theme, same font, same dedicated display work queue. So what's different?

I asked Claude for the hypotheses:
1. Something structural about how I create the screen object — maybe LVGL v9 changed the "right" way to build a
   custom screen and the built-in one does it differently.
2. A missing font/theme init that the built-in screen quietly does for me and I don't.
3. Some Kconfig symbol that the built-in screen implies and the custom path doesn't — something I *hadn't*
   actually checked, despite thinking I had.

So instead of guessing at #1 or #2, we went after #3: build the broken custom firmware *without* fixing anything,
and diff its generated `.config` against the known-good built-in one, line by line. Whatever's different is either
the cause or not, but at least it's ground truth instead of my own assumptions.

The diff was almost nothing. The screen-choice symbol flipped (expected), a couple of widgets the built-in screen
enables and mine doesn't (expected)... and one line I did *not* expect:

```
< CONFIG_LV_Z_MEM_POOL_SIZE=4096
> CONFIG_LV_Z_MEM_POOL_SIZE=2048
```

There it is. The built-in screen was getting a 4096-byte LVGL memory pool; my custom screen was getting 2048. The
why is in ZMK's own display Kconfig:

```
config LV_Z_MEM_POOL_SIZE
    default 4096 if ZMK_DISPLAY_STATUS_SCREEN_BUILT_IN
```

That `if` is the whole story. ZMK bumps the pool to 4096 **only** for its built-in screen. Pick the custom screen
and you silently fall back to Zephyr's default of 2048 — and 2048 isn't enough to allocate the mono theme plus a
screen object plus a single label. LVGL's allocator returns NULL, the very next line dereferences it, and the
display thread takes a hardfault. Because that happens during init, where a bunch of other work is queued, it
drags USB and BLE down with it. Which is also why the "dedicated work queue is supposed to protect BLE/USB"
reasoning never saved me: the problem wasn't a *stall* the queue could isolate, it was a *crash*.

The fix is one line in my board's `Kconfig.defconfig`, pinning the pool to 4096 under `if LVGL` so it applies no
matter which screen I pick. Rebuilt both variants clean, flashed it. 

And the OLED showed my label! The board enumerated over USB, was BLE paired and configurable over ZMK Studio.

After all that, the actual bug was a default value hidden behind an `if` I never thought to look inside.
Lesson: When two builds "should be identical", but aren't behaving identically, diff the generated config instead
of comparing the config you have written to define your board/or its functionality in the toolchain.

**tl;dr:** My custom OLED screen hung the whole board at boot (no USB, no BLE) even with a one-label body. I was
sure the config matched the working built-in screen — it didn't. Diffing the generated `.config` showed ZMK only
bumps `LV_Z_MEM_POOL_SIZE` to 4096 for its *built-in* screen; the custom path falls back to 2048, too small for
theme + screen + label, so LVGL handed back NULL and the display thread hardfaulted. Pinned the pool to 4096 in
my board config and the custom screen finally boots.

**Time spent this session: 7 hours**

#### May 30: Making my custom screen do its job

*Milestone 4 · Claude Code session: "Milestone 4: Custom screen"*

With the custom screen finally *booting*, this session was about making it do its job: show the battery (icon +
charging bolt + percentage) and show all my profiles as a set of boxes with the active one clearly marked. Sounds
like an afternoon. It was not an afternoon, because this little 1-bpp OLED had two surprises.

I wired the widgets up the proper ZMK way: each piece uses ZMK's display-listener macro, so state changes get
marshalled safely onto the display work queue, the same pattern the stock widgets use. Battery subscribes to
battery and USB events; the profile row subscribes to layer changes and reads the active profile straight from
`zmk_keymap_highest_layer_active()` — the same source my profile-cycle button advances, so the two can't
disagree. Flashed it and...

...the board hung again. Same garbage-on-screen, no-enumerate symptom as last session. But I knew this one
instantly, because I just spent seven hours learning it: the real screen has far more LVGL objects than my
one-label test, and 4096 wasn't enough for *it* either. Bumped the pool to 8192 and it came up. (I'm now paying a
kilobyte or two of RAM for headroom, which on a 256 KB part I will happily pay.)

And then the fun started.

**Surprise one: everything was the wrong colour.** White background, the "unselected" boxes also white-on-white
(i.e. invisible), and the selected box black with a white number. The exact photographic negative of what I'd
designed. My first instinct was that my styles were backwards, but I'd written `lv_color_white()` for the outlines
and `lv_color_black()` for the fill like any sane person would. So why inverted?

1. The mono theme is fighting my explicit colour overrides.
2. Something about how *this specific panel* maps LVGL colours to lit pixels is inverted.

It was #2, and it's genuinely counterintuitive. My display's device tree doesn't set `inversion-on`, which means
the SSD1306 driver reports its format to LVGL as `MONO01`. In that format `lv_color_white()` maps to a pixel
that's **off**, and `lv_color_black()` maps to one that's **lit**. Backwards from every intuition (what we already
discussed)— but ZMK's mono theme is already calibrated around it. So I stopped with my own background and text 
overrides, and just swapped white<->black inside the box styles where I wanted the inverse of the theme and 
everything worked: Lit rounded outlines for the inactive profiles and a solid lit box with an unlit number for the
active profile.

Just imagine there's a picture here. I was so locked in that I forgot to take any. Sorry.

**Surprise two: rotation.** The display is physically mounted sideways, so I want the whole UI rotated 90° —
battery under the short top edge, profile boxes stacked down to the short bottom edge. LVGL has an obvious API
for this: `lv_display_set_rotation(disp, LV_DISPLAY_ROTATION_90)`. I called it, flashed, and the layout came out
completely wrong — profile boxes marching off the right edge, only three of the four visible, battery gone
entirely. It clearly hadn't rotated my "rendered screen", but it had just resized the logical canvas and left 
the pixels where they were...

Digging into the Zephyr/LVGL glue confirmed it. On this stack `lv_display_set_rotation()` only updates the
*logical* resolution — it flips what LVGL thinks the width and height are. But the mono flush callback that
actually pushes pixels to the panel writes LVGL's coordinates straight through, untransformed. So software
rotation is effectively useless here unless you rotate the buffer yourself.

Which is what I ended up doing: a custom flush callback that takes LVGL's 1-bit buffer, walks it bit by bit into
a small static scratch buffer while rotating each pixel, recomputes the dirty area from the logical portrait
coordinate system into the panel's native 128×64, and then hands the rotated buffer off to Zephyr's own mono
flush (which knows how to pack it into the SSD1306's page-major memory). Install that over the default flush
callback, and the rotation works.

First rotated flash came up upside down. One more pass to flip the direction — rotating the other way and
mirroring both the pixel mapping and the area math to match — and it landed right way up.

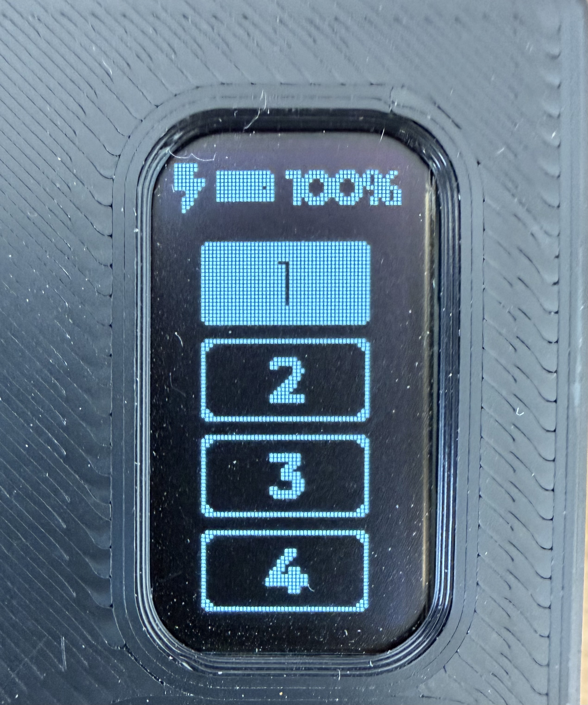
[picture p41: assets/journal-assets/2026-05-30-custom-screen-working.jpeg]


**tl;dr:** Built out the real OLED screen — battery and a row of profile boxes with the active one inverted. Three
things: The bigger screen blew past the 4096 LVGL pool too, so I bumped it to 8192; with no `inversion-on` in 
the device tree the panel runs `MONO01`, where `lv_color_white()` is an *off* pixel, so my colours came out as
a photographic negative until I swapped them and let the mono theme drive; and LVGL's `set_rotation` is a no-op
on this stack because Zephyr's mono flush writes coordinates untransformed, so I wrote a custom flush callback
that rotates the 1-bit buffer myself. Landed upside down first, flipped it, done.

**Time spent this session: 7 hours**

#### May 31: Fixed bugs from my custom screen (font)

*Milestone 4 · Claude Code session: "Milestone 4: Cosmetic screen"*

The screen was basically done, so this session was pure cosmetics: making the little OLED status screen actually
look good. Three things bugged me:

1. The battery icon looked way too bulky — the outlines were fat.
2. The percentage font was bulky too, sat about 2 px too high, and had weird stray pixels floating *outside* the
   glyph outlines.
3. The whole battery row was jammed into the top-right corner instead of being centred.

My first instinct was that this was a black/white inversion problem again. The panel is 1-bit and I'd already been
burned by which colour means "lit", so the working theory was that the font was being drawn in the wrong polarity.

That theory died fast. If the polarity were actually flipped, the *entire* screen would invert — a fully lit
background with dark text, and I'd notice that immediately. The profile boxes rendered fine. Only the battery text
and icon looked bad. So it wasn't the colours.

Claude and I went digging into how the text actually gets rendered, and the real culprit turned out to be
anti-aliasing:

1. The font I was using (Montserrat) is a **4-bit-per-pixel** font — 16 levels of anti-aliasing, smooth grey
   edges, designed for a proper grayscale display.
2. The battery and charge icons aren't a separate icon set — they're FontAwesome glyphs *baked into that same
   Montserrat font*. So they're 4bpp and anti-aliased too. There is no crisper battery symbol hiding anywhere;
   they all come from the one fuzzy font.
3. My panel is 1-bit. Every pixel is on or off, no in-between. So when the graphics library draws a 4bpp glyph
   onto a 1-bit surface, it renders the glyph as a grey mask and then **thresholds each pixel's brightness at
   127**.

And there's the whole problem. All those soft anti-aliased edge pixels sit *right around* that 127 threshold, so
whether an edge pixel lights up or not is basically a coin flip — which is exactly what "bulky outlines" and
"stray pixels outside the glyph" are. On top of that, Montserrat 12 has a 15 px line height, which is why the text
read as too tall.



On the 100% reading in that picture the edge bleeding doesn't look as awful as it does on the other percentages,
but you can still see how much bolder and thicker the font is compared to the next picture.

Once I understood *that*, the fix wrote itself: stop feeding an anti-aliased font to a display that can't
anti-alias.

- The percentage now uses UNSCII 8, a true **1bpp** bitmap font — no grey edges to threshold, so every glyph is
  pixel-exact. Bonus, it's 8 px instead of 15, so it stops sitting too high.
- The battery icon I stopped drawing as a glyph entirely. It's now built from plain full-opacity rectangles — an
  outlined body, a little terminal nub, and a fill bar whose width tracks the actual charge level. Axis-aligned
  opaque rectangles never get anti-aliased, so they stay crisp no matter what.
- The charging bolt I hand-drew pixel by pixel into a tiny 1bpp canvas.
- And the row position is recomputed on every update so the whole thing stays centred.

That first pass already looked miles better. Then I looked at it properly and started nitpicking, which turned
into a second round of changes.

**Charging.** I decided that when it's plugged in, the battery should fill up solid and show a dark lightning bolt
cut *out* of the fill — like the bolt is punched through it — spanning nearly the full height. So I redrew the
bolt bigger and inverted the idea: the canvas background is lit and the bolt itself is the OFF pixels.

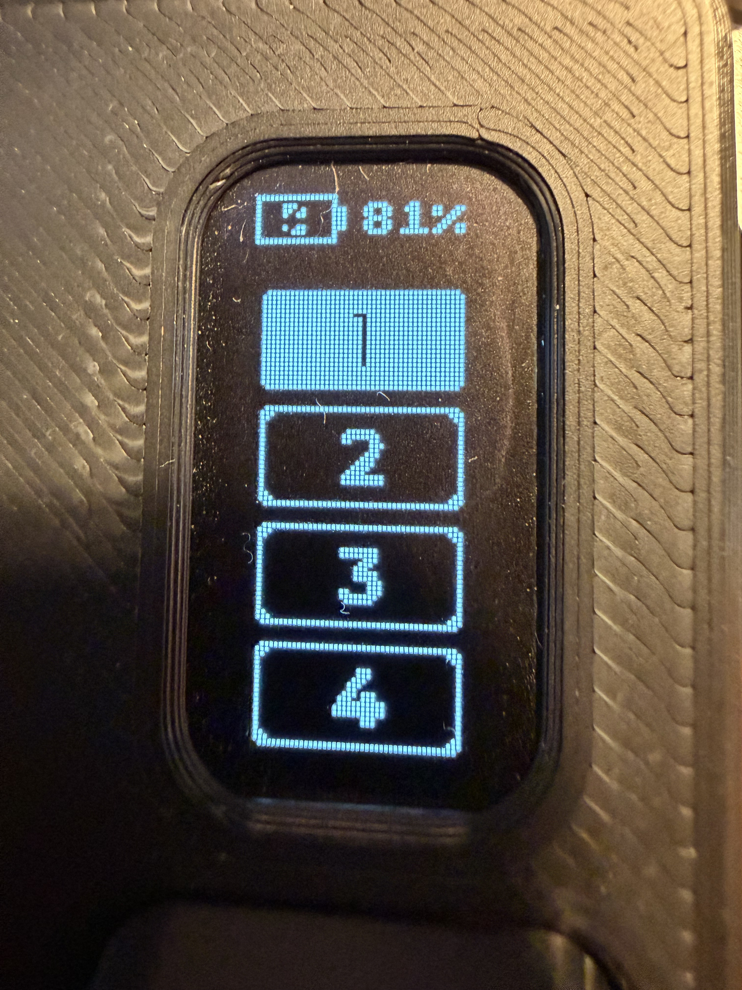
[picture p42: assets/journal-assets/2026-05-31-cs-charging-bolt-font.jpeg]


Except that's not quite what's in the picture — the battery icon isn't filled there, it's the bolt bitmap overlaid
on top of it. It looks weird, and I left it that way, because for this session I only wanted to prove I *can* draw
it on the right event. Getting the cut-out actually right is an M6 problem.

**The profile boxes.** Too narrow and floating with mismatched margins. I widened them, moved the whole column up
so it starts right under the battery, and lined the numbers up so the gap on the sides equals the gap at the
bottom. Then I rounded the corners more, because I thought they'd match the enclosure's round-offs better.

**The selected digit.** This is the part I liked. The numbers looked great when a box was *un*selected — nice and
bold. But the moment a box became the active one (which inverts it: dark digit on a lit fill), the digit's stems
shrank to about 1 px wide. Selected and unselected didn't match, and it looked cheap.

And it was the *same bug from the start of the session*. The digits were still an anti-aliased 4bpp font, and the
127 threshold doesn't treat the two polarities symmetrically — the edge pixels that survive one way get eaten the
other way. Same villain, second appearance, same fix: swap the digits to UNSCII 16, a 1bpp font, pixel-identical
no matter which way you invert it.

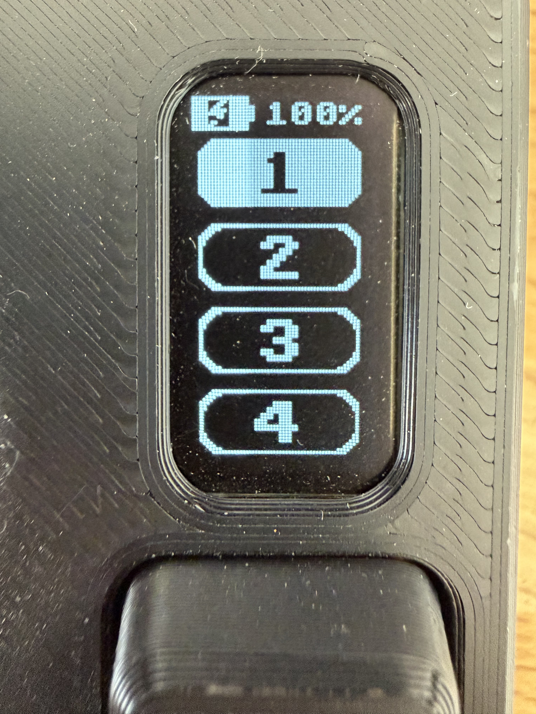
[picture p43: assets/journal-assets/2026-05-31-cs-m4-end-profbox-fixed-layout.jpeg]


Both variants built clean and I flashed it to the actual hardware to check.

One thing still open at the end: the battery cut-out. Right now the battery icon is filled white with the bolt
bitmap sitting on it as a black square with a white bolt inside, which is not the punched-through look I wanted.
That one carries into M6, when I kind of wrap up the firmware.

**tl;dr:** The battery readout looked fuzzy and bulky and I assumed a black/white polarity bug. It wasn't — it was
anti-aliasing. The 4bpp Montserrat font (and the FontAwesome battery icons baked into it) gets
luminance-thresholded at 127 onto the 1-bit panel, so every soft edge pixel becomes a coin flip. The fix was to
stop using anti-aliased fonts here: 1bpp UNSCII for the text and digits, and a battery icon built from plain
rectangles plus a hand-drawn bolt. The same threshold asymmetry also explained why the *selected* profile digit
rendered ~1 px thinner than the unselected ones. Battery cut-out still isn't right — carrying that into M6.

**Time spent this session: 7 hours**

#### June 7: Starting to implement the encoder

*Milestone 5 · Claude Code session: "Milestone 5: Encoder"*

[](assets/journal-assets/2026-06-07-Knob-Location.jpeg)!

This was the session where the implementation of the encoder was finally started. 
On the board of my macro keyboard I placed an AS5600 magnetic encoder. This is a little chip that reads the 
angle of a magnet, that is attached to the knob, and reports it over I2C. The goal was to turn the knob and have
it perform *different actions per profile*, that the keypad is in (volume on one, scroll on another, and so on).

First surprise: ZMK has no driver for the AS5600. There's an encoder driver in ZMK, but it's for the classic
mechanical EC11 quadrature encoders (the ones with two square-wave pins). The AS5600 is a totally different
animal — an absolute angle sensor you talk to over I2C. So the driver had to be written from scratch.

**A short explainer, because the rest of this entry depends on it: how ZMK actually consumes an encoder.**

ZMK doesn't think in terms of "encoder." It thinks in terms of a Zephyr *sensor* — the same abstraction Zephyr
uses for thermometers and accelerometers — that happens to report rotation. The chain has four links:

1. **The driver** decides when there's new data and raises a `data ready` trigger.
2. **ZMK's keymap-sensor subsystem** catches that trigger and asks the sensor for one value: rotation on the
   `SENSOR_CHAN_ROTATION` channel, expressed in **degrees** (a whole part and a millionths part).
3. It converts those degrees into **ticks** using a `triggers-per-rotation` number — "how many times should the
   knob fire per full 360° turn." That's the knob-feel dial: 14 per rotation means one action every ~26° of
   turn, 120 per rotation means one every 3°.
4. Each tick runs whatever **sensor behavior** the keymap bound to that knob, on that layer.

That last link matters for how the whole thing ended up structured: the binding is per layer, and since a profile
*is* a layer on this keyboard, every profile can bind the knob to something different.

The EC11 driver fires the trigger in step 1 off GPIO interrupts. But on this board the AS5600's one spare output
pin isn't even wired to the MCU, so there's nothing to interrupt on — the only way to know the knob moved is to
keep *asking*. So my driver polls.

**Writing it.** I hadn't written a Zephyr sensor driver before, so the way Claude and I worked it was:
read first, then write. We pulled up Zephyr's sensor driver API and ZMK's own EC11 driver side by side and used
them as the shape to copy — what a driver has to register, which API functions are mandatory (`sample_fetch`,
`channel_get`, `trigger_set`), and how the devicetree instance macros stamp one driver instance out per node.
Then I described what mine had to do differently (poll instead of interrupt, absolute angle instead of
quadrature) and we built it up (piece by piece).

What it does, concretely: read the 12-bit RAW ANGLE register (0x0E/0x0F) over I2C. The AS5600 divides a full
revolution into **4096 counts**, so one count is about 0.088° and one whole degree is roughly 12 counts. Take the
difference from the last reading, handle the wrap when the magnet crosses the 4095→0 boundary, and accumulate.
Once at least one whole degree has piled up, report it and carry the remainder forward. All of that runs on its
own dedicated thread at a 5 ms poll — deliberately kept off ZMK's system work queue, because that queue also runs
the Bluetooth and USB sending, and a blocked I2C read there would take the whole radio down with it.

**Wiring it into the firmware.** The driver doesn't live in ZMK's tree — it sits in my own out-of-tree module
alongside my custom behaviors and status screen, which gets pulled into the build as an extra Zephyr module. From
there the hookup is all devicetree: the chip gets a node on the I2C bus at address 0x36 with my own compatible
string, a `zmk,keymap-sensors` node points at it to tell ZMK "this is the keymap's sensor," and then each layer
in the keymap gets a `sensor-bindings` entry naming the behavior that should run on a tick. Kconfig turns the
driver on when the devicetree node is present, and the tunables (poll period, smoothing, deadband, startup delay)
are Kconfig options so I can change the feel without touching the code.

A few Zephyr/ZMK potholes on the way:

1. **The compatible-string collision.** Zephyr actually *does* ship a bare AS5600 driver, just not one ZMK can
   use. If I named my devicetree node with the same `ams,as5600` string, both drivers would try to claim the chip
   and the build would fight itself. So mine is `nikolas,as5600` — my own name, my own driver.
2. **A Kconfig dependency explosion.** My first attempt had the driver `select` the sensor subsystem while also
   depending on I2C, and Kconfig spat out a giant recursive-dependency wall of text. The fix was to nest it under
   an `if SENSOR` block the way the stock drivers do, instead of forcing it on.
3. **A macro that no longer exists.** The obvious way to embed a thread's stack in a struct
   (`K_THREAD_STACK_MEMBER`) was quietly removed in this Zephyr version; it's `K_KERNEL_STACK_MEMBER` now.

And then the genuinely sneaky one, which Claude caught reading through ZMK's rotation handling: there's a
backwards-compatibility trap where a report of "zero whole degrees" makes ZMK reinterpret the *fractional* field
as a raw count of clicks. So if my driver ever reported a tiny sub-degree nudge, ZMK would read that as something
like 175,000 clicks and go berserk. The fix is to make the driver hold its motion until at least a whole degree
has built up before reporting, carrying the leftover forward so nothing is lost.

With all that, **volume worked.** Turn the knob, volume goes up and down. Great.

**Scroll was a bigger rabbit hole.** ZMK has a mouse-scroll behavior, so I wired the knob to it — and turning the
knob did *absolutely nothing*. Turns out that behavior is a *velocity* model built for holding down a mouse key:
When you press and hold a pointing key, ZMK starts a timer and applies an internal velocity curve. Instead of sending
the same delta value repeatedly, ZMK dynamically calculates the exact speed at that specific millisecond, generates 
the appropriate delta for that speed, and injects it into the standard HID report. To the host operating system, it 
looks exactly like a standard USB or Bluetooth mouse being physically pushed faster and faster.
An encoder tick is an instantaneous nudge, not a hold, so the math worked out to roughly zero movement per tick. 
Wrong tool. I ended up bypassing it entirely and reporting discrete scroll-wheel notches straight into the input 
system — one clean notch per tick, exactly like a real scroll wheel clicks.

**Per-profile modes** had their own twist. My plan was to pick the knob's job per profile inside ZMK Studio.
Except Studio, in this version, literally can't touch encoders — its editing protocol only understands key
positions, not knobs. So there's no version of "configure the encoder in Studio", and the whole thing had to live
in firmware instead: each profile remembers its own mode, a little dispatcher reads that mode at every tick and
does the right thing, and a dedicated key cycles the current profile's mode.

Last thing: the scroll *feel*. Turning slowly felt precise, but turning fast made the page suddenly rocket. And
that is not good and surprisingly not my firmware at all; it's macOS's built-in scroll acceleration, which it
applies to every scroll wheel on earth.
MacOS has notoriously aggressive, non-linear acceleration curves built into its standard HID scroll wheel drivers:
- Low frequency reports: If you send scroll ticks slowly, macOS scrolls the page a painfully small amount.
- High frequency reports: If you send them rapidly, macOS accelerates the scroll exponentially, violently launching
  you to the bottom of the page.
My firmware sends a perfectly linear stream of ticks. I killed the scrolling speed up of macOS host-side with a
free app (LinearMouse), watched it go apply a linear acceleration, and called it solved. 
(It was not solved. That "fix" created a different problem which was hard to understand for another five days.)

Resolution: I divided the resolution per mode by giving multiple `triggers-per-rotation` dials from the explainer
above to each mode (every mode has it's own). Volume stays coarse at 14 ticks per full turn (one volume step every
~26°, so a small twist is one step), tabs coarser still at 12, and scroll is fine at 120 per turn (one every 3°) so
it actually uses the encoder's precision.

[Demo Video of scrolling with default macOS acceleration](assets/journal-assets/2026-06-07-Demo-Volume+macOS-acc-in-vscroll.mov)!

The video still has macOS acceleration doing its thing in the scroll section — this is from before LinearMouse.

**tl;dr:** Wrote an AS5600 sensor driver from scratch because ZMK doesn't have one, polling the chip over I2C on
its own thread since there's no interrupt line. Dodged a compatible-string clash, a Kconfig recursion, a removed
macro, and a "zero degrees means raw click count" trap. Volume was easy; scroll needed me to ditch ZMK's
velocity-based mouse behavior and emit real discrete wheel notches; per-profile modes had to be firmware because
Studio can't edit encoders at all. And I thought I'd solved the scroll feel with LinearMouse. I had not.

**Time spent this session: 11.5 hours**

#### June 8: The hang that was really the encoder never shutting up

*Milestone 5 · Claude Code session: "Milestone 5: Encoder"*

This is a debugging story with a clean twist at the end, so bear with me.

After the encoder was working, I noticed the keypad would sometimes just freeze. Non-responsive and it needed a
power cycle. Not constantly, but it occurred with a 30% chance over a five-minute run. And weirdly, it only
ever happened over **USB**; on Bluetooth it never froze once.

The first batch of fixes were mostly looking at the startup, that could cause this problem:

- Make the encoder's poll thread wait a second before its very first I2C read, so it isn't hammering the shared
  I2C bus while the OLED is still running its own boot sequence on that same bus.
- Seed the starting angle from inside the thread, so it can't fire one enormous bogus "you turned the knob 300°"
  event at power-on.
- Double the poll thread's stack, since that thread is where a whole chain of ZMK work runs.

Those helped — the boot-time freezes stopped. I also caught a self-inflicted wound: at one point I'd tried firing
one USB report *per scroll tick* to fight the acceleration, and a fast spin absolutely flooded the USB sending
path and hung it. Reverted that to one report per event.

But the freezes *during use* didn't go away, and I was still guessing. Then came the clue that cracked it, and it
came from a completely different direction: ever since the encoder work, **the screen had stopped turning off by
itself.** Normally the display blanks after you leave the keypad alone for a bit. Now it never did.

The screen blanks when the keypad decides it's idle. If it never blanks, the keypad thinks it's *never* idle, which
means something is constantly telling it the user is doing things. I put that to Claude:

1. The poll thread just waking up every few milliseconds — but simply running shouldn't register as user activity.
2. Some stray mouse/input event stream leaking out.
3. The encoder itself raising a constant drizzle of "the knob moved!" events, even though nobody's touching it.

It was #3, and it's kind of beautiful once you see it. ZMK's activity tracker — the thing that decides idle vs
active — treats *every sensor event as user activity* and resets its idle timer. And the AS5600, like any real
sensor, has noise: the raw angle it reports jitters by a count or two even when the magnet is bolted in place and
dead still. My driver reports motion once about a degree has piled up… and that one-or-two-count jitter
random-walks its way past a degree roughly **once a second**, forever. So the encoder was raising a phantom "it
moved" event every second of every minute. The idle timer never got a chance to expire — hence the screen never
sleeping. And that same relentless churn, running the full sensor→behavior→USB chain over and over for eternity,
is what was eventually wedging the USB path and freezing the board.

Two symptoms — "won't sleep" and "randomly hangs on USB" — one single cause: **the encoder never stopped talking.**

The fix is a *deadband*: pick a reference angle, ignore any wiggle smaller than a few counts around it, and only
move the reference when the knob *actually* turns. A resting magnet now produces exactly zero events. Flashed it,
and both problems vanished together — the screen blanks on idle again, and the hangs are gone. I later added a
light smoothing filter on the raw angle too, so the deadband can stay nice and tight without noise creeping back
in.

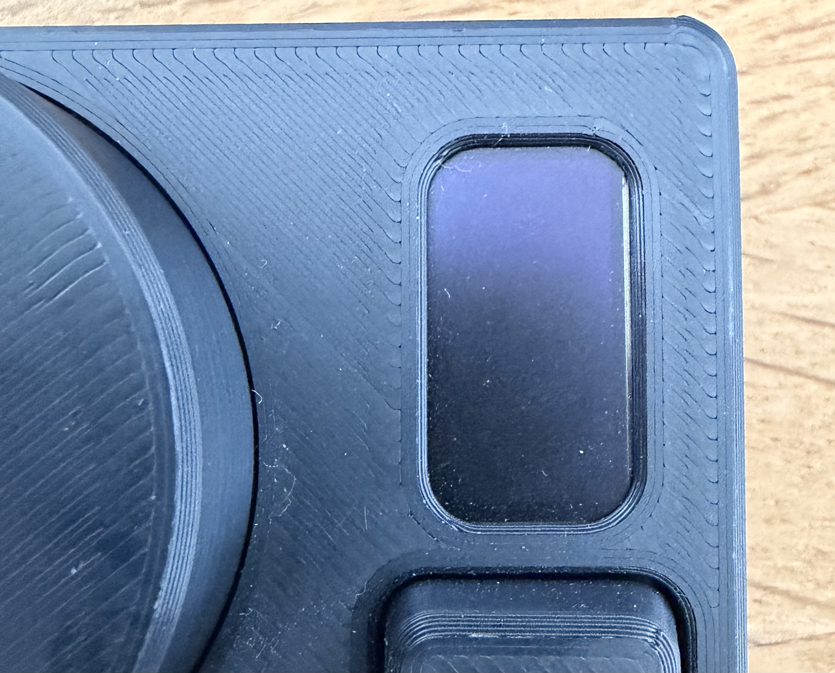
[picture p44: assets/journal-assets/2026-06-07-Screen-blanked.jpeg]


The lesson I'm taking from this: two bugs that look unrelated are worth staring at together, because sometimes
"the display won't sleep" and "the thing crashes" are the exact same problem wearing two hats.

**tl;dr:** The keypad kept freezing (only on USB, ~30% over five minutes) and, separately, the screen had stopped
ever turning off. Same root cause: ZMK counts every sensor event as user activity, and the AS5600's still-magnet
noise random-walked past my one-degree report threshold about once a second, so the encoder was raising phantom
"it moved" events forever — which blocked idle/sleep *and* slowly wedged USB. A deadband killed the phantom events
and fixed both at once.

**Time spent this session: 4.5 hours**

#### June 12: Chasing smooth scrolling (and losing to macOS)

*Milestone 5 · Claude Code session: "Milestone 5: Adding high res scroll + tab mode"*

Quick recap of where the encoder was: the AS5600 knob works, and one of its modes is scrolling. The problem was
the *feel*. I run my mouse with acceleration turned off (LinearMouse — see the last entry), and the encoder fires
a lot of scroll triggers per rotation, so scrolling ended up painfully slow: every trigger nudged the page a tiny
fixed amount and there was no acceleration to make a fast spin actually fast. So the plan sounded simple — speed
the scrolling up and add acceleration, on the firmware side.

That turned out to be optimistic.

[Demo Video of scrolling with default macOS acceleration](assets/journal-assets/2026-06-07-Demo-Volume+macOS-acc-in-vscroll.mov)!

(How it was before.) That's the only "before" video I'm putting in, and there'll be exactly one "after" at the
end, because scroll feel is genuinely hard to show on video — you can't really *see* smoothness, you have to have
your hand on the knob. Anything in between would just be more footage of a page moving.

**Explainer first, because none of the rest of this entry makes sense without it: what actually happens between
turning the knob and the page moving.** There are more layers here than I expected going in, and the whole
session is really a story about finding out which one is in charge.

Starting at the knob and walking outward:

1. **Magnet → counts.** The AS5600 splits a full revolution into 4096 counts (~0.088° each). My driver polls that
   every 5 ms and accumulates the difference.
2. **Counts → degrees.** Once a whole degree has built up, the driver reports it to ZMK as rotation in degrees,
   carrying the remainder.
3. **Degrees → ticks.** ZMK converts degrees into ticks via `triggers-per-rotation`. For scroll I set 120 per
   revolution, so one tick every 3° of turn. **This number is the base scroll speed**: more ticks per rotation =
   more scrolling per rotation.
4. **Ticks → line-deltas.** Each tick becomes a wheel movement of `scroll-units` "lines" (I keep this at 1). This
   is the *magnitude* — the actual number that goes in the report.
5. **Line-deltas → HID reports.** ZMK's pointing subsystem packs that into a standard HID mouse report — the same
   wheel field a normal mouse uses — and ships it over USB or BLE.
   The HID report only preserves a Signed 8-bit Integer for the vertical scroll - so just scroll units, that where
   performed in between of HID reports/last report. That the datatype is an int, will be a problem for me - although
   it makes sense that it is for the rest of the mouse HIDs...
6. **HID reports → scrolling pixels.** The host reads the wheel value and decides how far the page actually moves.

**High-resolution scrolling** is worth its own paragraph, since I spent hours on it. A traditional mouse wheel is
notched, and classically one unit in the report will be interpreted into one line of scrolling on the host. That's
chunky: you can't express half a notch (because the HID report carries an int). The HID fix is the **Resolution 
Multiplier**: the device tells the host "my wheel sends 16 units per notch," so the host divides by 16 and can scroll
in fractions of a line, which is what makes modern trackpad-style scrolling smooth. ZMK exposes this as smooth 
scrolling and advertises a multiplier of 16. That sounds perfect for an encoder with 120 ticks per rotation — except
 a multiplier only does anything if the host honours it.

So by the time the movement reaches the screen, three separate things *could* be scaling it: the **resolution
multiplier** (step 5→6), the **report rate** (how many reports per second arrive), and the **magnitude** (the
number inside each report). My whole plan — "add acceleration in firmware" — assumed magnitude was in charge and
that firmware could shape it. Working out which of the three macOS actually cares about *is* the session.

With that, the debugging.

The first thing I tried was the obvious one: raise the base speed and add a velocity-based acceleration curve in
the firmware — measure how fast the knob is turning from the time between ticks, and multiply the scroll amount up
when it's spinning fast. Built it, flashed it. The acceleration part felt kind of nice, but two things were off:
the ceiling where it stopped accelerating was way too low, and — more confusingly — changing the base "scroll
units" knob did *nothing at all*. I could set it to 1 or to 32 and the scrolling looked identical.

The real question was: what does macOS actually *do* with the number I put in the scroll report? Claude and I 
read up on how ZMK's smooth scrolling works and how macOS interprets it, and then just ran experiments.

1. **Maybe high-res scrolling is dividing my value by 16.** ZMK's smooth scrolling advertises a HID "Resolution
   Multiplier" of 16, which on paper means the host treats 16 units as one notch. So I built two firmwares — one
   with smooth scrolling on, one off — identical except for that single flag. If macOS honoured the multiplier,
   the no-smooth build should have been ~16× faster. Result: *identical*. macOS just ignores the multiplier for
   my device.
2. **Maybe I'm not sending enough reports per second.** New idea: faster scrolling = more discrete steps. So I
   rewrote it to fire many more little steps, paced so they wouldn't flood the link. Tested over Bluetooth: no
   change. Then I made a build that massively over-produced steps (ten per tick) and compared Bluetooth against a
   USB cable — USB can push ~1000 reports/s, Bluetooth is capped around 66–133/s by the connection interval. If
   report *rate* mattered, USB should have blown Bluetooth away. Result: *exactly the same on both*. So macOS
   velocity-caps scrolling — past some low rate, more reports do nothing.
3. **So it has to be the magnitude — but which host layer eats it?** Turns out the value gets ignored
   *specifically because of LinearMouse*. LinearMouse's whole job is to remove acceleration, and the only way it
   can do that cleanly is to normalise every scroll event to a fixed distance — which throws my magnitude away.
   So my June 7 "fix" was the very thing blocking me now. When I turned LinearMouse off and let macOS handle the
   raw reports, magnitude suddenly mattered a lot… except now macOS applied its *own* acceleration, which is a
   nasty sudden "jump" at a very low speed threshold, and everything was way too fast.

So, to close the explainer from the top of the entry — **of the three things that could scale my scrolling, macOS
uses exactly one.** It throws away the resolution multiplier, it velocity-caps the report rate, and the only
input it genuinely consumes is the per-report magnitude. Then it runs that magnitude through *its own*
acceleration curve: macOS looks at how fast the scroll events are arriving and multiplies the distance up 
accordingly. On a trackpad that curve should feel natural. Fed by an encoder and it does not — it's flat and too
slow for a while, then crosses a threshold at a very low speed and *jumps*, and past that it saturates. That's
the behavior from the first video.



And that's why the firmware can't win. Acceleration in firmware means multiplying the magnitude — but macOS then
accelerates my already-accelerated magnitude, so I'd be stacking one curve on top of another curve I can't see or
disable. The only way to get a predictable result is to give macOS a boring linear stream and let one thing own
the curve.

So basically: **on macOS, the scroll feel belongs to the host, not the firmware.** My two native options were both
bad — LinearMouse (linear, but a fixed un-tunable step) or macOS default (a jumpy, uncontrollable accel curve). 
Neither gives you "smooth scrolling".

So the solution was being less delusional with the implementation of a HID, that doesn't use any extra companion
app... So there's a whole category of macOS apps built for exactly this: pixel-based smooth scrolling with a tunable
acceleration curve, without normalising every scroll unit.
I tried **Mac Mouse Fix** (Mos is the free alternative) and it worked right away. It offered smooth scrolling and also
inertia, which I wanted to implement into the firmware (but I don't need to anymore), and you could configure those
parameters very well. Bonus, it also fixed the separate problem where VS Code scrolls way to fast, because the too many
arriving scroll events get each one whole line. Another big advantage is that I can use the macOS scroll speed (can
also be configured with Mac Mouse Fix) and never need to open the app again, if I want to adjust the scroll speed.

In short:
That flipped the firmware's job. It is now very simple: a clean, linear stream of one line per tick, zero acceleration.
The app owns smoothing, acceleration, and even the little bit of scroll inertia I'd originally planned to add in firmware.

[Demo Video of scrolling with Mac Mouse Fix](assets/journal-assets/2026-06-12-Demo-Scroll-w-Mac-Mouse-Fix.mov)!

While I was in there I added an encoder mode I'd wanted for a while: scrolling through browser tabs. Clockwise =
next tab, counter-clockwise = previous, mapped to Ctrl+Tab / Ctrl+Shift+Tab (works across browsers on macOS).
It's coarse on purpose — about one tab per notch — so a small twist moves exactly one tab instead of flinging you
ten tabs over. The browser profile defaults to it now. That one just worked, first try.

And then, right when it all felt finished, the old USB hang came back — the board freezing during heavy scrolling
over USB. I was pretty sure it was the same family as the earlier flood-the-HID-TX bug, and it was, but the
mechanism was sneakier than I remembered:

1. **Is it just too many reports flooding USB?** Kind of, but not on paper — the USB endpoint polls every 1 ms and
   the send semaphore is capped, so a plain "too many reports" story didn't quite close.
2. **Where does the scroll report actually get sent from?** This was the key. ZMK runs the whole
   sensor→behavior→HID chain *synchronously on the AS5600's own poll thread*, and every USB HID send blocks on a
   30 ms semaphore. A fast spin fires the sensor ~200 times a second, and sending one HID report per tick,
   sustained, keeps that path pinned — one macOS polling hiccup becomes a 30 ms stall and the HID TX wedges. The
   reason it only resurfaced *now* is almost funny: the scrolling finally feels good, so I actually scroll
   continuously for long stretches, which I never did back when it was janky.

The fix is the same shape as the original, just more disciplined: the firmware still tracks every degree of
rotation, but it *coalesces* the scroll into at most one report every 12 ms (~83/s, comfortably under the
Bluetooth rate that never has this problem) and carries the leftover so nothing is lost. macOS caps the rate
anyway and Mac Mouse Fix smooths between reports, so you can't feel the difference — except it doesn't hang.
Tested by scrolling as hard and as long as I could over USB. Rock solid.

**tl;dr:** Spent the session trying to make encoder scrolling fast *and* smooth in firmware, and slowly proved
that on macOS the host owns the scroll feel: it ignores HID high-res, caps the report *rate* so more reports don't
help, and either normalises the magnitude away (LinearMouse) or applies its own bad acceleration (default OS). The
right answer was a smooth-scroll app (Mac Mouse Fix) plus firmware sending a clean line-per-tick stream with
zero acceleration. Also added a browser-tab encoder mode, and fixed a USB hang caused by firing one HID report per
tick during sustained scrolling — now down to ≤83/s.

**Time spent this session: 12 hours**

#### June 26: Studio profiles, fixed encoder modes, and a screen rework

*Milestone 6 · Claude Code session: "Milestone 6 + bug fixes"*

This was the "clear out the M6 backlog" session. A bunch of things I'd deferred while getting the encoder and the
screen working — all small on their own, but they'd been nagging at me.

**Adding and deleting profiles in ZMK Studio.** I wanted to be able to add or remove profiles from Studio instead
of hardcoding them in the keymap. It turns out ZMK's mechanism for this is "reserved" layers: you declare extra
layer slots with `status = "reserved"`, and they sit there inactive until Studio's "add layer" button fills one
in. So I ship 5 real profiles plus 2 reserved spares, which caps me at 7 — which happens to be exactly how many
profile cells fit on the OLED anyway, so that lined up nicely. Pleasant surprise along the way: just turning on
ZMK Studio already pulls in layer reordering *and* NVS keymap storage, so add/remove/rename all persist to flash
for free.

**Encoder modes that survive a reboot.** Each profile remembers its own encoder mode, but until now that lived
only in RAM, so a power cycle reset everything to defaults. I wired it up to save into NVS. The first pass used
ZMK's normal 60-second save debounce, but that felt wrong here — if I change a mode and immediately flip the power
switch, I want it to have stuck. So it saves immediately instead.

**The Studio active-layer thing that isn't a bug.** I'd been bothered that ZMK Studio doesn't highlight which
profile is currently live on the keyboard. Claude and I went digging through the Studio RPC protocol and the docs
expecting to find a setting I'd missed — and there just isn't one. The protocol has no "active layer changed"
message in this version of ZMK; it's simply not a feature. Not something wrong on my end. And the OLED already
shows the active profile anyway, so it doesn't matter.

**A small power fix.** The magnetic encoder has no interrupt line, so its driver polls the angle over I2C on its
own thread every 5 ms, forever. That's ~200 CPU wake-ups a second even when nothing's happening, which stops the
chip from ever settling into low-power idle. The poll thread now backs off to every 100 ms once the board goes
idle, and goes back to fast polling the moment you touch the knob again.

**The screen rebuild.** This was the biggest chunk of the session. The M4 screen showed the battery and a column
of numbered profile boxes and that was it — no indication of which encoder mode was live, or whether I was on USB
or Bluetooth, and the profiles were just digits. So I rebuilt the layout: battery row stays on top, then two split
status lines — `CT:` for connection type (USB/BLE) and `EM:` for encoder mode (VOL/VSCR/HSCR/TABS), prefix on the
left edge and value on the right — and then the profile column underneath. The active profile is now a full-height
rounded cell with the profile's actual *name* inverted inside it instead of a number, and the inactive ones are
squeezed filled bars whose height scales to however many profiles are actually live.

Two more problems with its solutions:

1. LVGL's own rounded corners are bevels at this size on a 1-bit panel, so I let Claude hand-draw every cell into
   a 1bpp canvas with my own symmetric rounded-rect rasteriser.
2. The obvious per-pixel canvas calls each trigger their own invalidate, and doing that per pixel made switching
   profiles visibly lag. Writing straight into the canvas bitmap and firing a single invalidate per update fixed
   it.

There's also a genuinely nasty gotcha in the canvas buffers: a 1-bit LVGL canvas has an 8-byte palette living
*inside* the buffer, which the addressing helper skips over but the buffer-size macro doesn't reserve space for.
So every canvas buffer needs those extra bytes added on top, and the bitmap base has to come from the helper
rather than the raw pointer. (This one comes back to bite me later.)

Then two layout bugs that took a couple of iterations to get right:

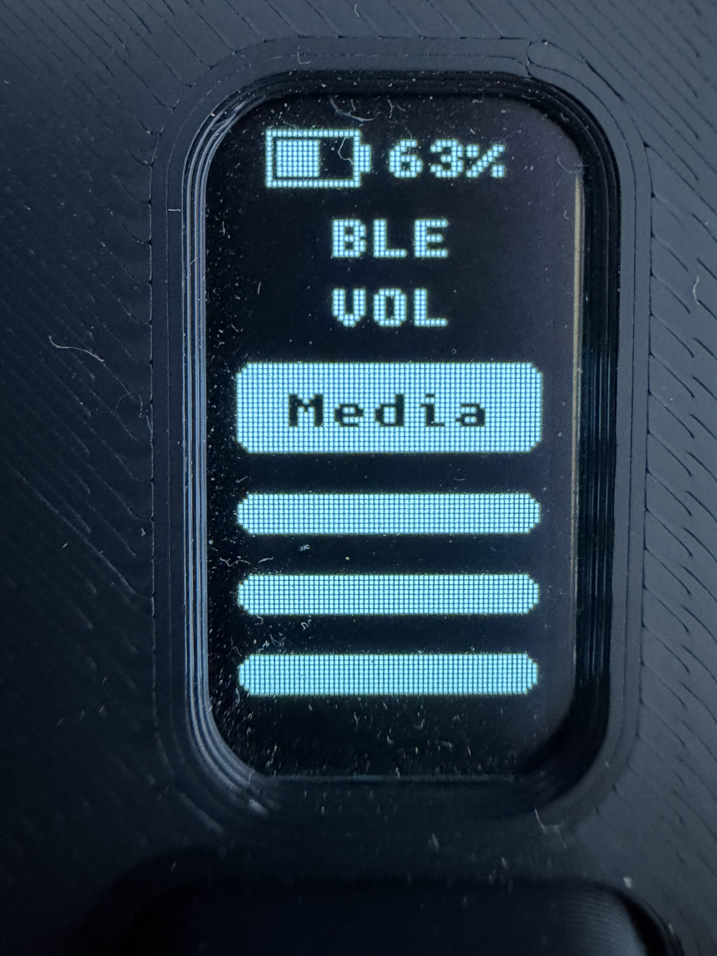
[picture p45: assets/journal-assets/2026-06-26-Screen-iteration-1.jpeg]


Round-off working, but inconsistent as soon as the profile count changed — I'd tied the corner radius to the cell
height, so at any count other than 5 the round-off went either too sharp or weirdly blobby.

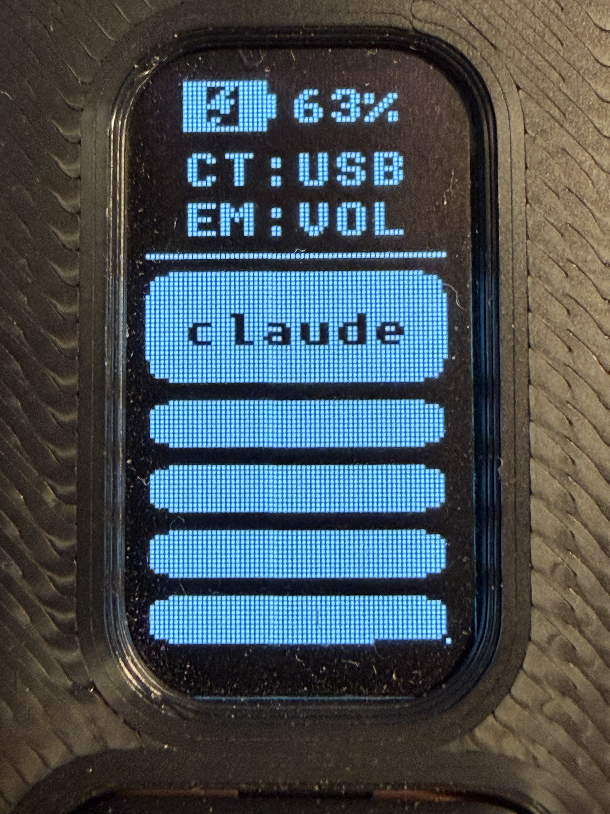
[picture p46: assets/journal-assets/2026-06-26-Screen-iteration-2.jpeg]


Better, but the radius still differed depending on whether a cell belonged to the selected profile or not. Fixed by
giving every cell one fixed radius, always. The other bug: with only 2 profiles the single inactive cell ballooned
to fill the entire column, because I was stretching everything down to the bottom edge. Now the inactive cells cap
at 10 px and just leave empty space below.

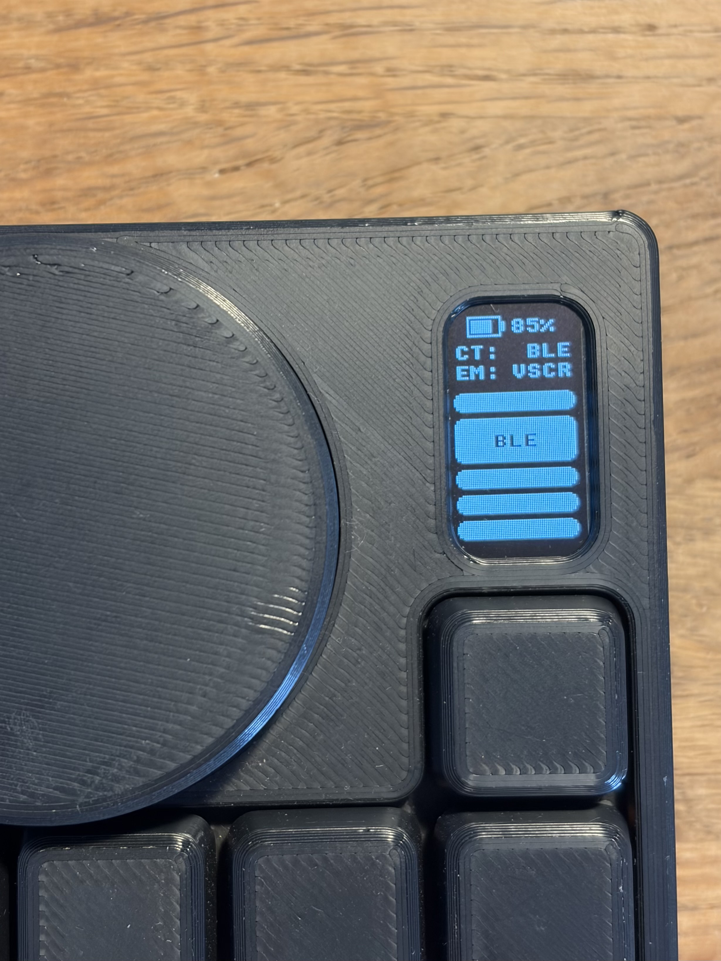
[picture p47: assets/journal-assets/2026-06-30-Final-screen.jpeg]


Final layout, consistent across every profile count.

**tl;dr:** Cleared the M6 backlog: Studio can now add and delete profiles via reserved layer slots (up to 7),
per-profile encoder modes persist to flash and save instantly, and the encoder poll backs off when idle to save
power. Also rebuilt the status screen — connection type and encoder mode get their own lines, the active profile
shows its name instead of a digit, and the cells are hand-drawn into a 1bpp canvas so the corners stay crisp — then
fixed two layout bugs so it looks right at any profile count. Also confirmed the "Studio doesn't show the active
layer" thing is a missing ZMK feature, not my bug.

**Time spent this session: 8 hours**

#### June 30: The USB crash that turned out to be a lightning bolt

*Milestone 6 · Claude Code session: "Milestone 6 + bug fixes"*

Great story though, so here's the whole thing.

**The report.** With the keyboard plugged into USB, it would go completely unresponsive after a few minutes —
screen frozen, keys dead, needs a power cycle. On Bluetooth it was rock solid for 15+ minutes. USB only. No
obvious trigger, it just... died.

The USB-vs-Bluetooth split was the biggest clue. What's actually different? On USB the board is always powered, so
it *never* deep-sleeps — every thread just keeps running forever. On battery it drops into deep sleep after a
while, which is basically a reset. So whatever was going wrong needed the board to stay awake and busy, and USB
kept it that way.

Claude's list of suspects:

1. A stack overflow somewhere, silently corrupting memory. The MPU (Memory Protection Unit) stack guard was turned 
   off, which means an overflow doesn't fault cleanly — it just quietly scribbles over whatever's next in RAM and the
   board falls over minutes later.
2. The encoder poll thread's stack (it runs the whole sensor→HID chain synchronously).
3. Some USB-side thread — the USB driver's work queue, or the main thread.
4. A deadlock on the shared I2C bus, since the OLED and the encoder are both on it.

First I turned on the MPU stack guard and added a fatal-error handler that reboots instead of hanging (Zephyr's
default is to just spin forever, which is exactly the dead-board behaviour). That immediately paid off as a
*diagnostic*: the board went from "hangs" to "reboots in a loop on USB." A reboot means the fatal handler is
firing, which means it's a genuine CPU fault, not a deadlock. Hypothesis 4, gone.

Then I started guessing at stacks, and this is the embarrassing part: three wrong guesses in a row.

- Bumped the encoder thread's stack. Nope. (That thread doesn't even start until a second after boot, and the
  fault was happening at boot — so it couldn't have been that. I should've caught that sooner.)
- Bumped the USB work-queue stack and the main stack. Nope.
- Found a genuine bug where the charge-bolt canvas buffer was 8 bytes too small — it wasn't reserving the palette
  space I'd just learned about. Real bug, worth fixing, but not the crash either.

At that point I was clearly poking in the dark, so we stopped guessing and built a proper diagnostic instead. No
debugger needed (thanks). The fatal handler stashes the faulting thread name, the reason code and the program counter
into a chunk of RAM that survives a reboot, and the boot-up screen prints it to the OLED. The neat part is that the
LiPo keeps that RAM alive even across a USB unplug, so the procedure is: plug in USB, let it crash-loop, unplug
USB, and the board boots on battery and shows me the last fault it hit. A tiny black-box recorder.

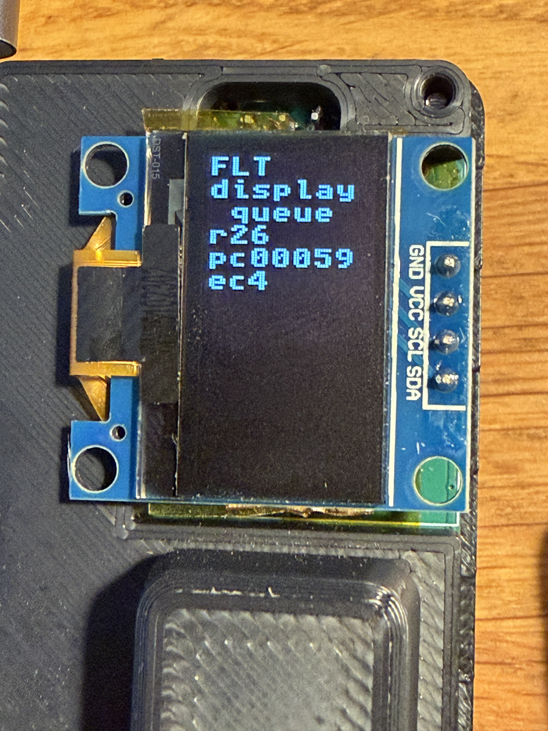
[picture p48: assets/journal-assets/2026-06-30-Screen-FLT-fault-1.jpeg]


First capture: `FLT display queue r26 pc00059ec4`.

So the fault is in the *display* thread. Good — that narrows it down by a lot. But the reason code `26` made no sense
(Zephyr's standard fault reasons only go up to 4), and the program counter pointed at a Bluetooth function, which
a display thread would never call.

Turns out `26` was the actual answer, I just didn't recognise it. ARM adds its own architecture-specific fault
reasons starting at 16, and 26 decodes to an **imprecise bus fault** — a bad memory write that the CPU buffers and
reports *later*, on whatever instruction it happens to be on when the fault finally surfaces. That's exactly why
the program counter was pointing at unrelated Bluetooth code: for an imprecise fault.

There's a fix for that: you can disable the Cortex-M write buffer with a single bit in a config register, which
forces bus faults to be *precise* — reported on the exact instruction that did the bad write. So I flipped that
bit and captured again.

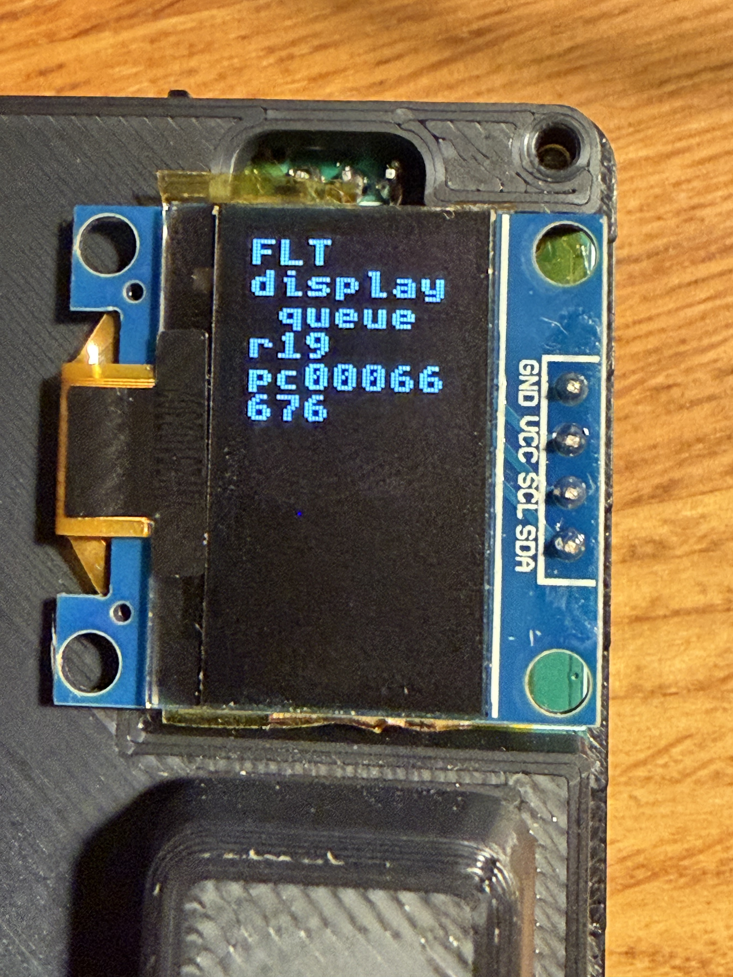
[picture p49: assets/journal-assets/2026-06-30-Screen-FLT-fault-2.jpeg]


Second capture: `FLT display queue r19 pc00066676`.

Now `r19` is a clean MPU data-access violation, and the PC pointed straight at `argb8888_image_blend` — inside
LVGL's "blend an image to RGB565" routine. Yeah... my display is one bit per pixel, black and white. There is no
RGB565 anywhere. Why is LVGL doing 16-bit colour blending?

The only thing that draws *only* while charging (i.e. only on USB) is the little lightning-bolt icon in the battery.
I'd built that bolt as a canvas image sitting *inside* the bordered battery-body box, overlapping the battery fill. 
On a 1-bit display, when LVGL has to composite an image that's clipped inside a bordered container like that, it spins
up a temporary RGB565 layer to do the blend in — and the buffer math for that path is wrong for a 1-bit build. So it 
blended out of bounds and tripped the MPU. The profile-column canvas, which is the same kind of 1-bit canvas, *never*
crashed — because it's a standalone element sitting directly on the screen, not clipped inside anything and not 
overlapping anything.

So the fix was to make the charging graphic behave like the profile column: one standalone canvas, the size of the
battery interior, sitting directly on the screen, with the plain fill hidden while it's showing. Same lightning
bolt, drawn a safe way — which also finally closes out the battery cut-out I'd left looking wrong back in M4.

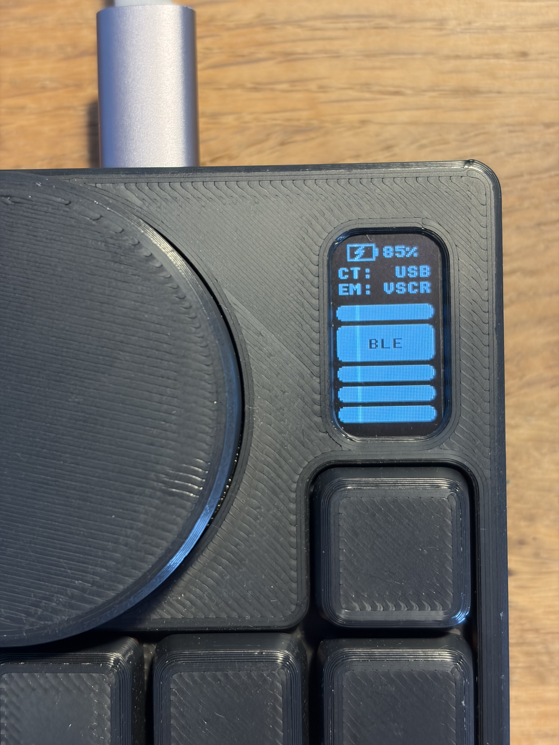
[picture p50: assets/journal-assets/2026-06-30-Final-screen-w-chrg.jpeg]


Then the cleanup pass: ripped out all the diagnostic scaffolding (the on-screen fault capture, the precise-fault
register hack, the thread naming) and reverted the three stack bumps that turned out to be red herrings. I kept
the two things genuinely worth keeping — the MPU stack guard and the reboot-on-fault handler — so if anything ever
does fault again, the board recovers on its own instead of hanging dead. Then I wrote the whole saga up in the
project notes, including the fault-capture trick, because I will 100% need it again someday.

Lessons I'm taking from this:
- On a 1-bit display, don't make a canvas or image a clipped child of a styled box, and don't let it overlap other
  things — keep decorative canvases standalone and directly on the screen.
- An imprecise bus fault has a useless PC. Force precise faults *first*, before you trust the program counter, or
  you'll chase ghosts. I chased three.
- When you catch yourself guessing at fixes, stop and build a way to actually *see* the fault. The OLED black-box
  recorder found in two captures what three blind guesses couldn't.

**tl;dr:** The keyboard kept dying on USB but not Bluetooth. After three wrong stack-size guesses I built an
on-screen fault capture (which survives a USB unplug thanks to the LiPo), forced the bus faults to be precise, and
traced it to LVGL blending the battery charge-bolt through a broken RGB565 layer — because the bolt was a canvas
image clipped inside the battery box. Rebuilt the charging graphic as a standalone screen-level canvas like the
profile column and it's stable, which also finally fixed the battery cut-out left over from M4. Kept the MPU stack
guard and reboot-on-fault as permanent safety nets.

**Time spent this session: 7 hours**

#### July 1: Fixed the LiPo not being charging

I got the LiPo battery of my macro keyboard to charge, so that's pretty neat.

Observation: When supplying the keypad with power, the charging indicator light up on the screen, but the
screen widget for the battery capacity would only show a static battery percentage.

What could cause this problem? Short answer:
1. Faulty screen indicator
2. Faulty resistors in the voltage divider
3. Charging IC not charging the LiPo: Could be due to something disabling the IC.

I was able to eliminate both cause #1 and #2 by measuring if the voltage of the battery increased when
supplying the charging IC. And it did not, this means the cap of the LiPo also stayed the same.
So it must be #3.

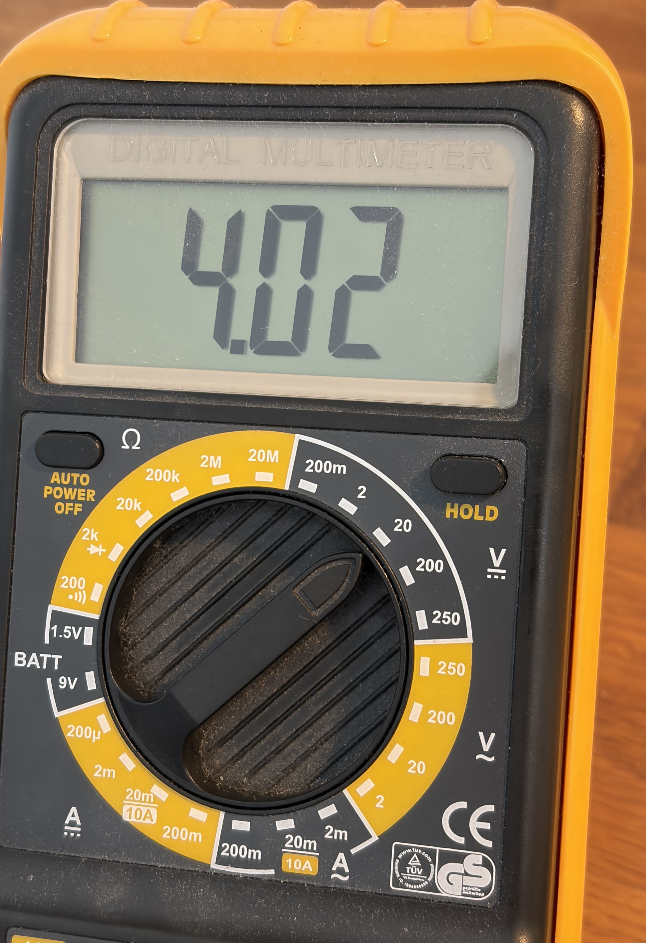
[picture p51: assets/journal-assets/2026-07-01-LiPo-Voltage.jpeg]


Because the ICs are usually fine, I looked into the schematic of the keyboard to see if I messed up something
there:

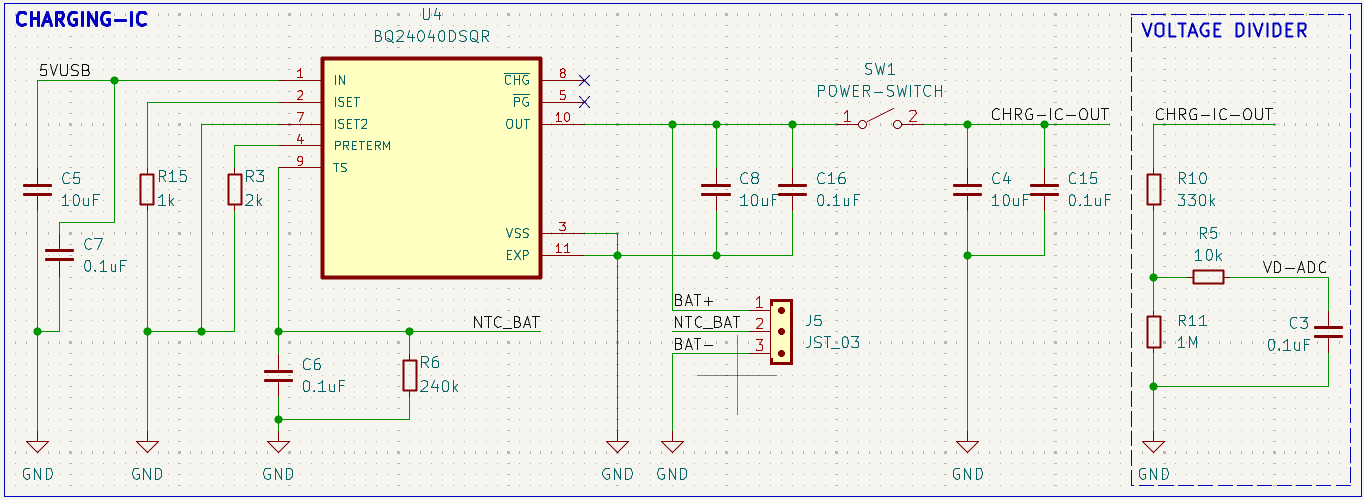
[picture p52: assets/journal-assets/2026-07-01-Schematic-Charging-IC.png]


So I used the exact same IC before and it worked flawlessly. The only thing that I changed was that I made
use of the temperature sense terminal.
I looked into the datasheet of the IC and what could cause the charging IC to be disabled:

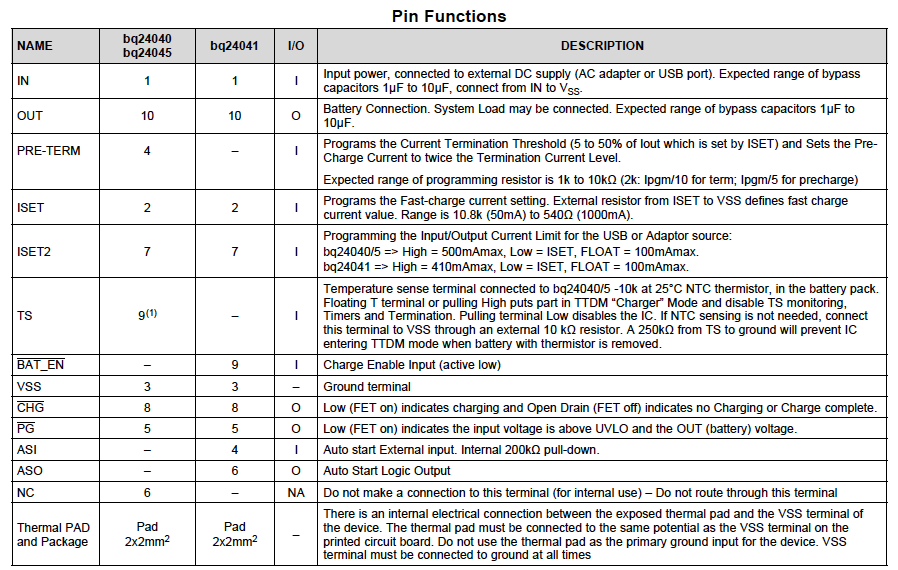
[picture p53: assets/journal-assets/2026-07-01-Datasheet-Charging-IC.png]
 

The TS (temperature-sense) is the BQ24040's veto over charging. When the NTCs resistance (changes
resistance with temperature of the bat pack) is not in the range that the BQ24040 likes, the battery is 
either to cold/absent or to hot. - Bc of safety, i wanted to implement it.
I measured TS-to-GND and got 237 kΩ. The key insight is from the datasheet is:
The IC pushes a fixed 50 µA through whatever's on TS and watches the *voltage*. At 50 µA a healthy 10 k NTC
sits around 0.5 V, dead center of the charge window. My 237 kΩ slams that node way
past the ~1.6 V "thermistor removed / freezing" threshold, so the IC decided
the battery was impossibly cold (or absent) and quietly disabled charging.

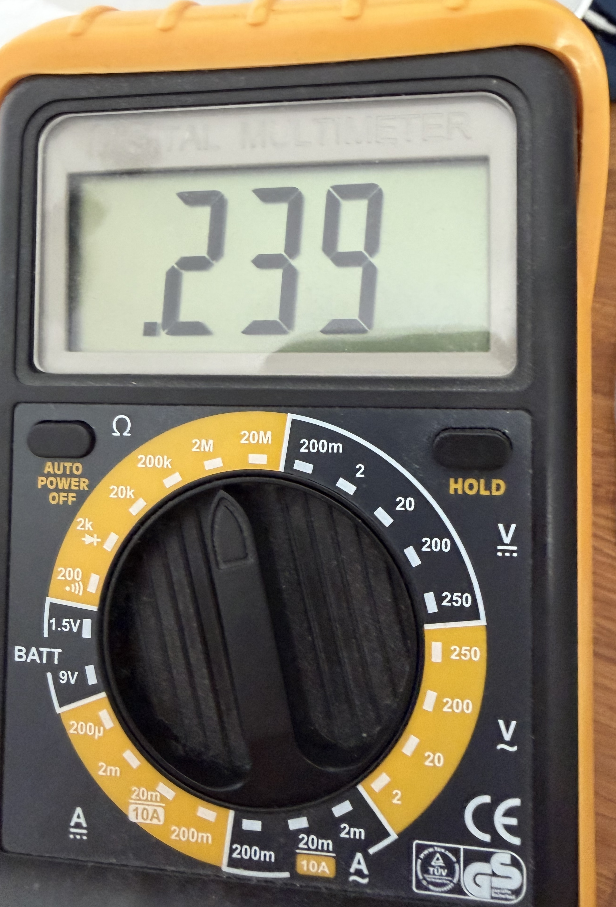
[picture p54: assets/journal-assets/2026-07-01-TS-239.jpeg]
Multimeter reading ~237 kΩ from the TS pin to GND — the smoking gun


R6 is 240 k and it's supposed to sit in *parallel* with the pack's 10 k NTC → 10k ∥ 250k ≈ 9.6 kΩ.
If the NTC were actually in the circuit I could never measure *above* 10 k. Reading 237 k meant
the thermistor's return path was gone.

But why is the pack's NTC was never electrically present?
I asked Claude:
1. Either cold joints
2. BAT– isn't tied to the same GND R6 references → the NTC has no return path
3. The pack's third wire isn't a 10 k NTC.

And guess what? Yes, it was #3 again. I added the third wire (NTC) to the battery myself, because the battery
came without it. And I thought it was no problem as the BMS of the battery clearly labeled a third pad "NTC",
but it seems like the pad was just connected to no thermistor, because after measuring the resistance between
NTC and GND directly, there was none. Haha

Solution:
I don't need JEITA temp protection for the keypad to work (I will just get a LiPo with 3 wires the next time),
so I took the datasheet's sanctioned shortcut: a fixed 10 kΩ from TS to GND to pin the node back into the
normal window. In parallel with R6 that's ~9.6 kΩ → ~0.48 V on TS → charging
enabled.

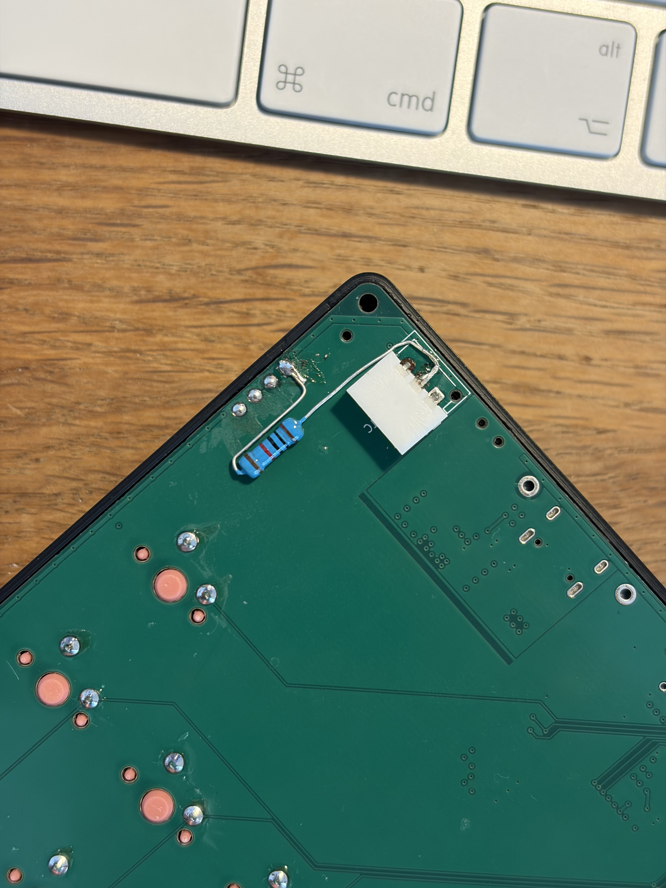
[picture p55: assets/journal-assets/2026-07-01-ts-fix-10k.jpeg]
The 10 kΩ resistor tacked in from TS to GND


Plugged in USB and the charge status finally went active — the pack is pulling
current for the first time.

Not charged
Charge status showing the pack actually charging - after a few minutes

**tl;dr:** LiPo wouldn't charge because the BQ24040's TS pin saw 237 kΩ (the
NTC was never in-circuit) and disabled charging. A 10 kΩ from TS to
GND put it back in range and enabled charging. For new keypads, I will just get the batteries with
3 wires.

**Time spent this session: 4 hours**

#### July 2: Wrote the BOM

I added and wrote BOMs (yes, plural) to fill some gaps in the repo and make the macro keyboard reproducible.

I noticed, that the shipping instructions for my project specifically ask for a bill of materials (BOM) to 
enable others to reproduce it. The current version doesn't have one, former ones had.

Why BOMs? - I landed on a multi-BOM structure (or idk how to call it):
- One BOM for PCBA under /hardware/PCB/KiCad/Macro-Keyboard-v4/production/bom.csv: After manufacturing the PCB, its populated with the components in this BOM. This step is the PCB assembly. Only the parts for this manufacturing steps are in this BOM. (e.g. nRf module, caps, resistors, usb port, etc.)
- PCB BOM under /hardware/BOM_PCB: Some of the parts, that need to be soldered onto the PCB, can't be soldered in the PCBA step, usually because those parts are to big. So I solder those manually. (e.g. key switches, OLED display, JST connector for LiPo - that's all)
The production BOM (for PCBA) captures only the parts for PCBA and the PCB BOM captures all of the parts, that need to be soldered onto the PCB, including the parts from PCBA.
- Master/build cost BOM: This BOM lists all of the on-PCB parts, which couldn't be populated with PCBA, + PCBA + the PCB itself (isn't included in neither PCB BOM or PCBA BOM) + all of the off-PCB parts. (e.g. enclosure + screws, the LiPo battery, bearings, keycaps, etc.)
This explains the structure. I will put this also in the README.md (probably in shorter form).

Only in the master/build cost BOM I added in the approximate costs for the components. I didn't also add 
prices to the PCB BOM, because PCBA cost might very, some components might need to be exchanged for other 
ones, tax and shipping costs can also change. Shipping cost, tax, customs duties are also listed as they 
are quite substantial.
In the end of the master BOM I calculated the approximate price per keyboard unit (without labour), which 
turned out to be about 61,38€. That could have been worse. But it needs to be said: If you somehow decide 
to build one on your own, you will end up paying more then just the price for one unit, because there are 
minimum ordere quantities for many components (above of what is needed for one keyboard unit). For example, 
the PCBs need to be ordered in quantity of 5 or above with JLCPCB.

To the main BOM I also added Notes to clarify in which group the components belong (on-PCB, on-PCB PCBA, 
off-PCB) beside the vendor.

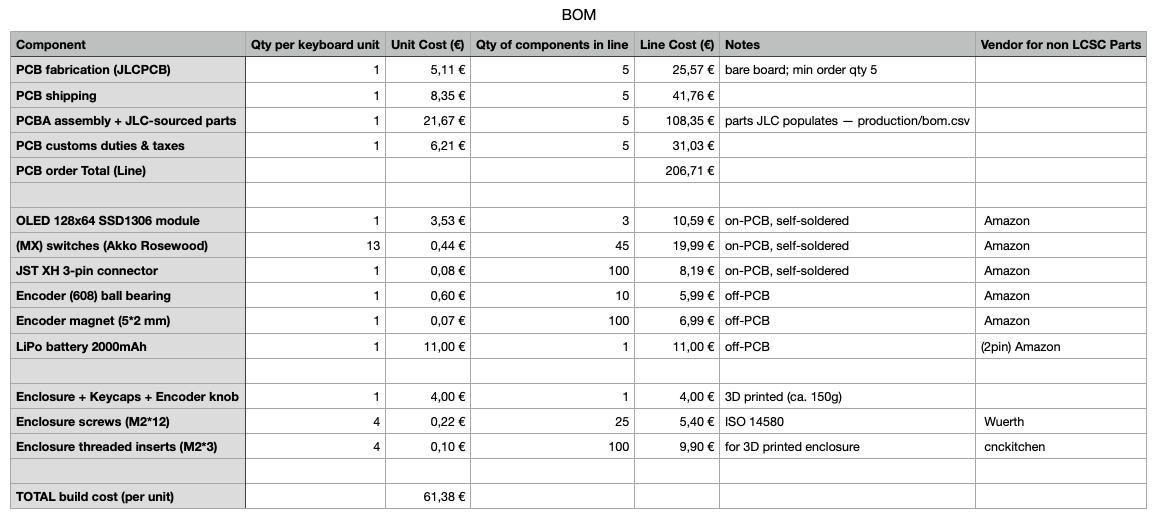
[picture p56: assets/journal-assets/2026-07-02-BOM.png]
Picture of cost BOM

Sorry that this is the only pic...

**tl;dr:** I added the BOMs, which gave me a good view on the hardware of this project.

**Time spent this session: 3 hours**

#### July 23: Starting to write the README.md and did some repo health/prep for shipping

Today is the day where I add a README.md. For doing so, I followed the [README](https://guides.horizons.hackclub.com/guides/readme-guide/)
and [shipping guide](https://guides.horizons.hackclub.com/guides/shipping-guide/#-hardware) of Hackclub in
order to make sure, that I forget nothing in the README. Additionally I started prepping up the repo for
finally shipping this project to Hackclub.

This will be a very short journal entry, because there is nothing special to it.

Firstly repo health:
Yesterday I needed to fix the demo videos from this journal. I thought that you could embed videos
(in .mov format) just like pictures in a markdown document and make them playback, when viewing on
GitHub. Turns out, this doesn't work, because GitHub doesn't support viewing videos in markdowns yet
as well as PDFs. Therefore I just gave a link to the demo videos and I think it's fine for now.
In the future, I could convert the videos into GIFs, which can be played back, but this sounds like
it could cost me more time...

That PDFs can't be viewed either is a good insight, because I was planning to show off my schematic
in the README.md (as a PDF), and this doesn't work. So I will rasterize them into a .jpeg or so.

Today I moved the journal-assets folder to a new assets folder at root, because I realized that the
other documents would profit from pictures and other assets as well. And having one assets folder with
a sub folder for the journal is clean.

Now the README.md:
This is quite straightforward, but it's still a lot of work. You need to describe your project in 
enough a way that anyone who isn't familiar with it, but has a basic understanding of computers, 
especially in the field of microcontrollers, can understand it.
This is also why I created a dedicated section titled "What is a Macro Keyboard?" before explaining
what mine actually does. This explains the core concept of macro keyboards quite nice.
Getting down to the following core functionality of the device was also different and took some effort.
The use of my language is different too. This journal uses an intentionally informal language, whereas 
the README uses a more formal writing style.

In case that it is unclear what a bootloader is for the reader, I also incorporated the way they work
and why I chose a UF2 bootloader for flashing my macro keyboard.
And some more stuff. But if you read the README, it makes sense and doesn't need to be repeated.

In the end though, this README.md offers a nice overview of the project.

But the README.md is not finished yet. I still need to add all of the pics and pic out a license.

**tl;dr:** Started the README.md + gave the repo some care; the README.md offers a good overview.

**Time spent this session: 3.5 hours**

#### July 25: Adding the Hero + layout shot to the README.md, fixing KiCanvas + formatting

Starting with the photos: Today I created the Hero and Layout shot of my macro keyboard.

1. For the Hero shot I used a white back ground and placed the background and my keyboard in front
of my window in order to light the scene evenly. I would have liked to use my phone to capture the
image, but I couldn't due to not having enough control over the iso, aperture  and shutter speed.
Because the scene was lit brightly and a lot of light hit the sensor of my phone camera, the shutter
speed was increased. (Or the time, that light hits the sensor, was decreased).
This is problem, because this is what the display looks like up close:

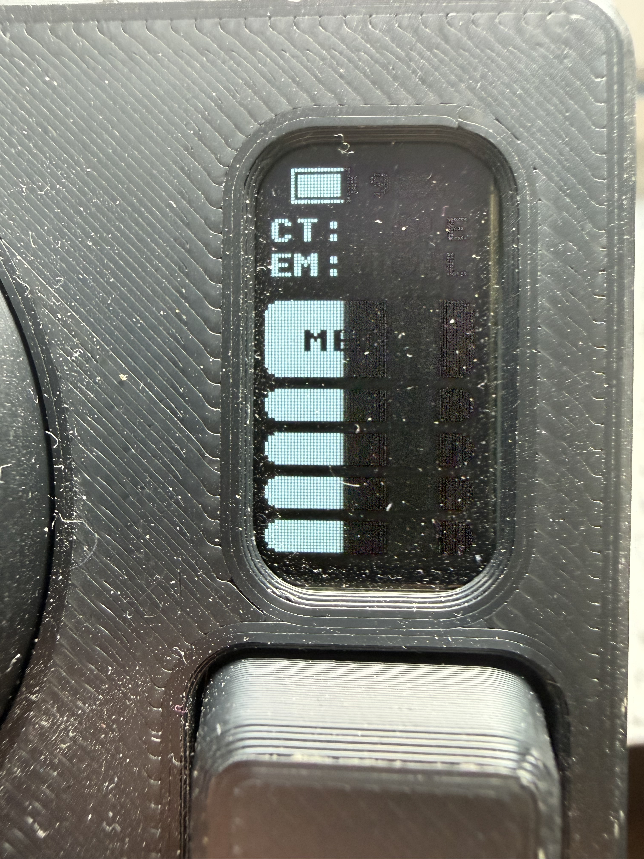
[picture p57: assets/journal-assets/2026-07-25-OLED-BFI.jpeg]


I knew this effect from an LTT video about nvidias pulsar technique on LCD monitors to decrease motion blur.
Quick google search, to explain it correctly:
This is **Backlight Strobing** or **Black Frame Insertion** (BFI)
> How it works: Instead of leaving the backlight or pixels on continuously (sample-and-hold), the display 
> briefly turns off the light or inserts a black frame between each real frame. This cuts down how long an 
> image stays visible on your retina, stopping the smear effect as your eyes track movement.

But the reason, why my OLED also inserts black bars, is probably that this is also the way, in which brightness
is controlled. (like over PWM) - Inserting black bars, between frames, is probably easier than dimming
the brightness of individual pixels... considering that the OLED is driven over I2C with limited bandwidth
and full array dimming mean that instead pushing a buffer with 1bpp it would require n/2 many bits per pixel
for n many brightness levels.

This also means, that I wont be able to change it (probably), only if I run the OLED at full eye-blinding brightness.

Sorry for nerding out about this. It is ok, if the time I spent on this work session, is not account for.
And it might not all be correct. I am speculating.

This effect is not visible by a human eye, because our eyes are exposed to light for a long time and are
sluggish. - So to get rid of the BFI, I just need to mimic the human eye, by exposing the sensor of my
camera to light for longer.

This is what shutter speed controls. But the problem is that I don't have control over it. This is why I told
you in the beginning that I couldn't use my phone.

My camera worked though. There I had full control over the shutter speed and took this picture with the white
background:

Macro Keyboard

2. Layout picture: I screenshotted the top view of the keyboard in CAD (I use Autodesk Fusion)
with different render settings.
I put in the solid body view into photo shop with the visible edges and then overlayed another photo with a full
wire frame view with the same perspective and adjusted the coverage (Deckkraft auf Deutsch).
This results in a clear photo with faint internals of the macro keyboard.

Then I marked the important periphere with text and exported this pic:

Macro Keyboard layout

3. For KiCanvas I needed to change the address to the path of my KiCad project root in order for KiCanvas to
find the PCB and schematic.

Macro Keyboard layout
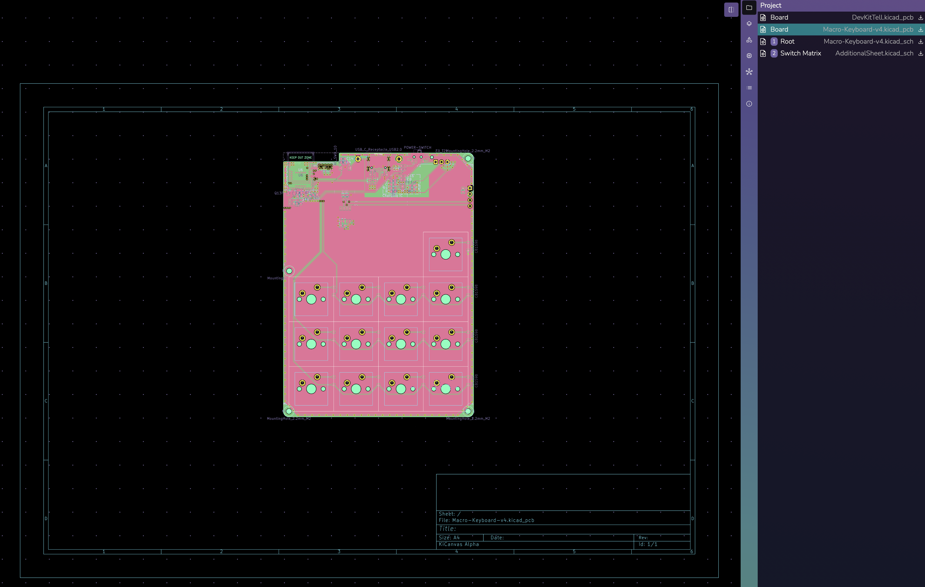
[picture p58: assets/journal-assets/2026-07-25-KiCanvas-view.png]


4. Lastly I changed some formatting in the README.

**tl;dr:** Took the hero picture of the macro keyboard, which made me discover the effect BFI has when
photographing it with a high shutter speed - was able to solve it by using my separate camera; created the 
layout photo by mashing together multiple view exports from my CAD; lastly fixed KiCanvas and did formatting.

**Time spent this session: 4 hours**

#### July 25: Adding licenses to the GitHub repo 

The ship requirement of horizons was to pic out and add a license to the repo. So I added two licenses!

This was actually pretty simple. I looked up common licenses for hardware projects and software projects
on GitHub. Especially the projects that went into my direction. For example, there is this one guy, who
built a [split keyboard](https://github.com/GEIGEIGEIST/TOTEM/tree/main?tab=readme-ov-file) based on the
Seeed Studio XIAO nRF52840 BLE or XIAO RP2040.
I actually discovered him a while ago (almost a year) when I first started with my project and was looking
for other people that also had a problem. Ever since seeing his sleek split keyboard, he has been a great
inspiration, even though he built a split keyboard instead of a macro keyboard.

And he chose the "CERN Open Hardware Licence Version 2" - which I also liked. It basically says:

> Anyone may study, modify, fabricate and sell your board. But if they distribute a modified design,
> or distribute a product made from it, they must make the complete corresponding design sources 
> available under CERN-OHL-S v2 too, keep your notices, and — where practicable — keep the source 
> location visible on the product's case (§4). So a company can build and sell your keypad, but they
> can't fork the PCB into a closed product.

So I chose this license for the hardware. Not for the whole repo, because I already use open source
firmware ZMK and I tailored and expanded it with modules, that could be very useful to other people.
For example: The OLED module. And the problems I had are documented (e.g. artifacting, custom screen
failing, anti aliased text that looked weird, assigning multiple bits to a 1bpp pixel or config I set
up was flipped back to default by just changing to the custom screen instead of the built in one)
Or an other example is the AS5600 driver that was adapted from Zephyr to work seamlessly with ZMK.
This can be used by other people and I don't need to be that strict there.

So for the Software part I chose the MIT license:
> Maximally permissive. Anyone can use, modify, sell, or close-source my ZMK module, driver and config;
> the only obligation is keeping my copyright line and the licence text with copies. I give no warranty
> and take no liability. It does not require anyone to publish their changes back to me. 

This is also the same license ZMK itself uses, so there's no friction there.

Sound good.

So I went onto https://ohwr.org/cern_ohl_s_v2.txt and opensource.org/license/mit and added them to
the Repo and explained the dual license structure in the README.md shortly:

> | Part | License | File |
> |---|---|---|
> | Firmware, ZMK config, scripts, docs (everything outside `hardware/`) | **MIT** | [LICENSE](./LICENSE) |
> | Hardware design — KiCad schematic/PCB, Gerbers, CAD/case, BOMs (everything in `hardware/`) | **CERN-OHL-S v2** | [hardware/LICENSE](./hardware/LICENSE) |

GitHub only detects a license at the repo root. It reads LICENSE there and nowhere else, so 
whichever license sits at root becomes the badge on the repo page and the value in the API.
The convention is: root = default, subdirectory = override. And in multi-license repos the root
file is read as covering everything not otherwise stated, and a LICENSE deeper in the tree scopes
that subtree. 
So hardware/LICENSE overriding for hardware/ is the pattern people expect, and it puts the CERN text
right next to the files it governs.

The one weakness of the current split could be that a root LICENSE invites the readers that MIT covers
hardware/ too, and someone who only reads the root file might not go looking for the override. 
But the README table from the top is what resolves that (or should).
(The usual fix is a short NOTICE file at root stating the split, rather than adding prose to LICENSE 
itself — but keeping LICENSE as pure license text is what keeps GitHub's detector happy...)

So this is why I landed on the structure.

**tl;dr:** I needed to add a license to the repo, so I was going through many licenses, especially
those assigned to similar projects. I added two licenses: CERN for hardware, MIT for firmware; 
I made sure nothing collides with other open source projects I use (e.g. ZMK) and ´I don't break to many
conventions with the license structure in the README (MIT as root and CERN as override for hardware
subpath).

**Time spent this session: 3 hours**

#### July 25: Adding the build guide

There is nothing special to it. There's no point in repeating what's already written there.
So I'll just add a few things I paid attention to:
1. I had to go through the entire process once—from ordering the PCB to verifying that everything works (+ add some nice pics along the way), which was time consuming, but gave me once again a nice overview on what producing the macro keyboard actually involves. (because the build guide rounds up nicely and pulls the whole repo togther). The overview comes from the round up, not by being high level and lacking detail (the guide doesn't lack important details).
2. I noticed some mistakes in other documents:
   - for example: The BOM_PCB.csv didn't mark the DNP components
   - or that I gave the bootloader a wrong attribute ("nice_nano" instead of the "MDBT50Q-1MV2") in the CLAUDE.md, so I changed that as well: Bootloader was right, but I said it belonged to a different board instead of exactly my MCU
3. In the README.md I forgot to declare that the local toolchain would need to be installed in order to build the firmware.
4. I came on the idea to just add build artifacts to the repo, so Users don't need to install a local toolchain. (only if they want to modify the firmware)
5. I also needed to explain why the bootloader is optional, what to do if you don't want to use one, and that the debugger was irrelevant and the two different versions of the firmware and what to do at each step, if one is chosen. 
6. Or the macOS scroll acceleration and what to do.

Just think every possible path through!

And then these are the mistakes you notice when you think through the users perspective and go though everything one by one.

There is much more to it and writing everything down and explaining it, would take a while, so this will do...

**tl;dr:** I added the build guide and made my way through the entire repository for all the different paths a user could take, which made me change more than just the build guide.

**Time spent this session: 6 hours**

#### July 26: Adding photos of the keypad + CAD exports + demo video

It is still the same night, but now the 26th.

1. I exported the meshed from Fusion + its source to hardware/CASE.
2. Took some more photos of the finished product and put them in the README.md
3. Captured a quick demo video of the functionality of the macro keyboard and uploaded it to youtube

**tl;dr:** Go to sleep.

**Time spent this session: 1.5 hours**

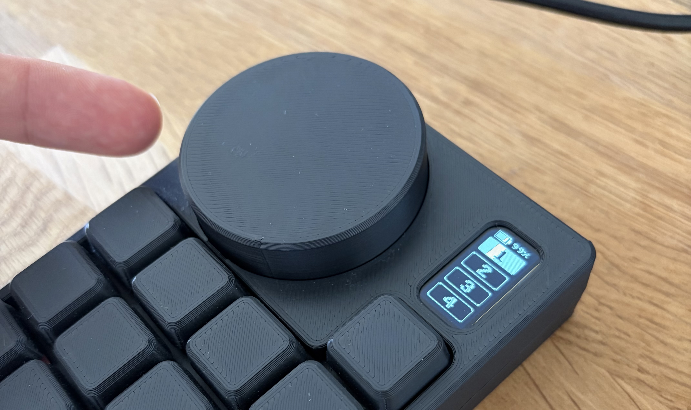
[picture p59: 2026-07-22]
assets/journal-assets/2026-06-07-Knob-Location.jpeg

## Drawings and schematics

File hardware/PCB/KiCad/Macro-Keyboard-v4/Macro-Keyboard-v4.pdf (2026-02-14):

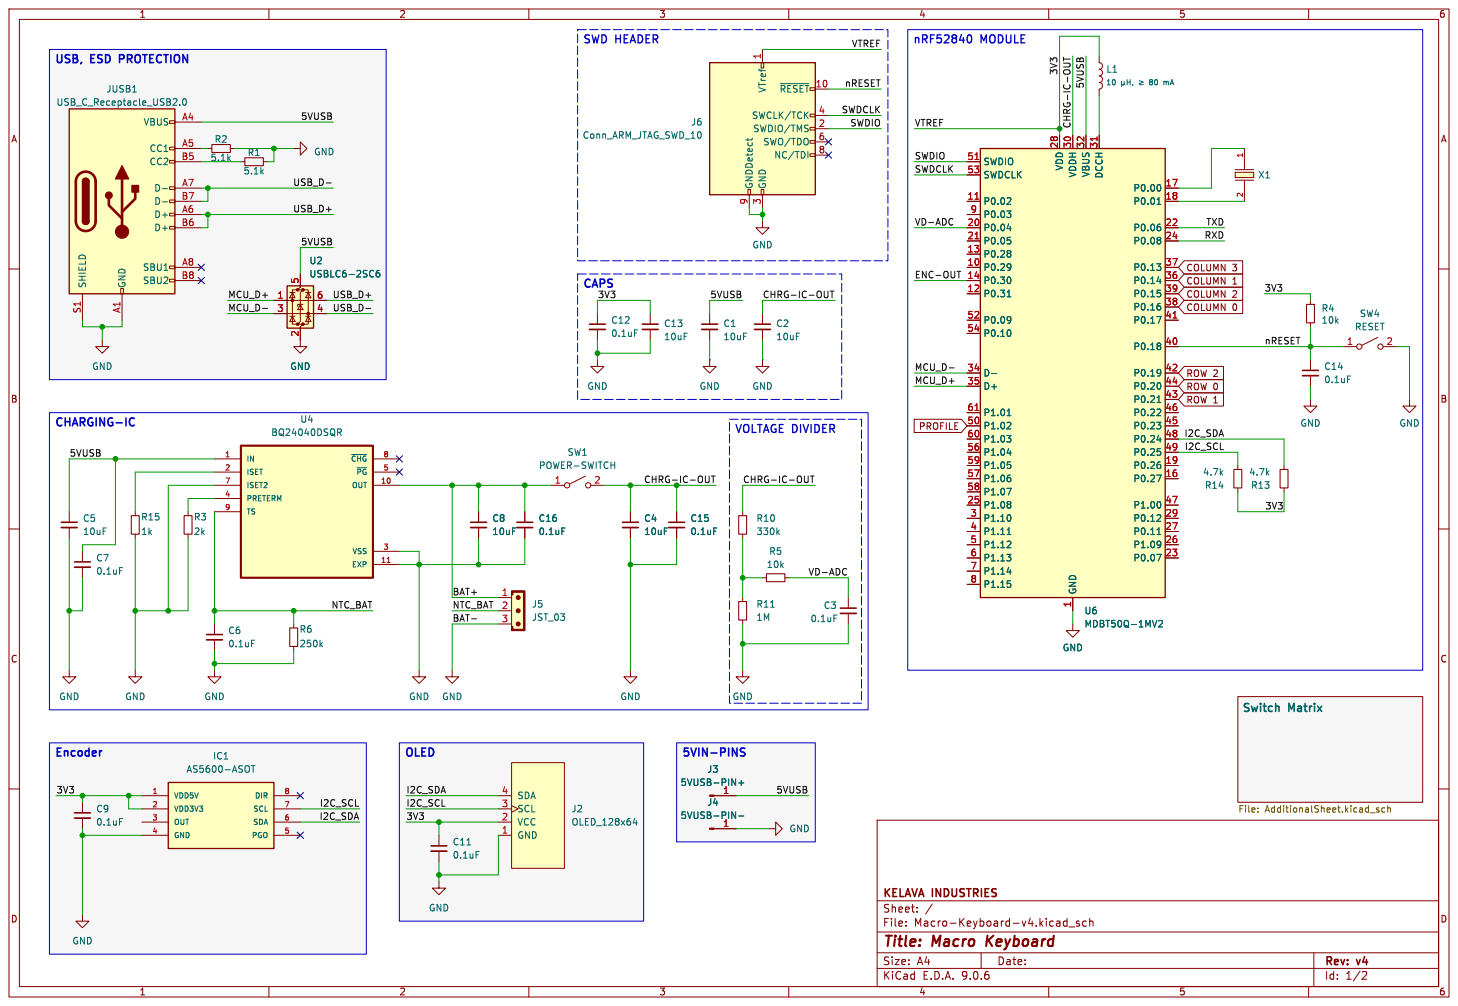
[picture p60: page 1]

3 ~{RESET}10 SWCLK/TCK 4 SWDIO/TMS 2 SWO/TDO 6 NC/TDI 8

TXD
ROW 2 ROW 1 ROW 0 COLUMN 2 COLUMN 0 COLUMN 1 COLUMN 3

Id: 1/2 Title: Macro Keyboard

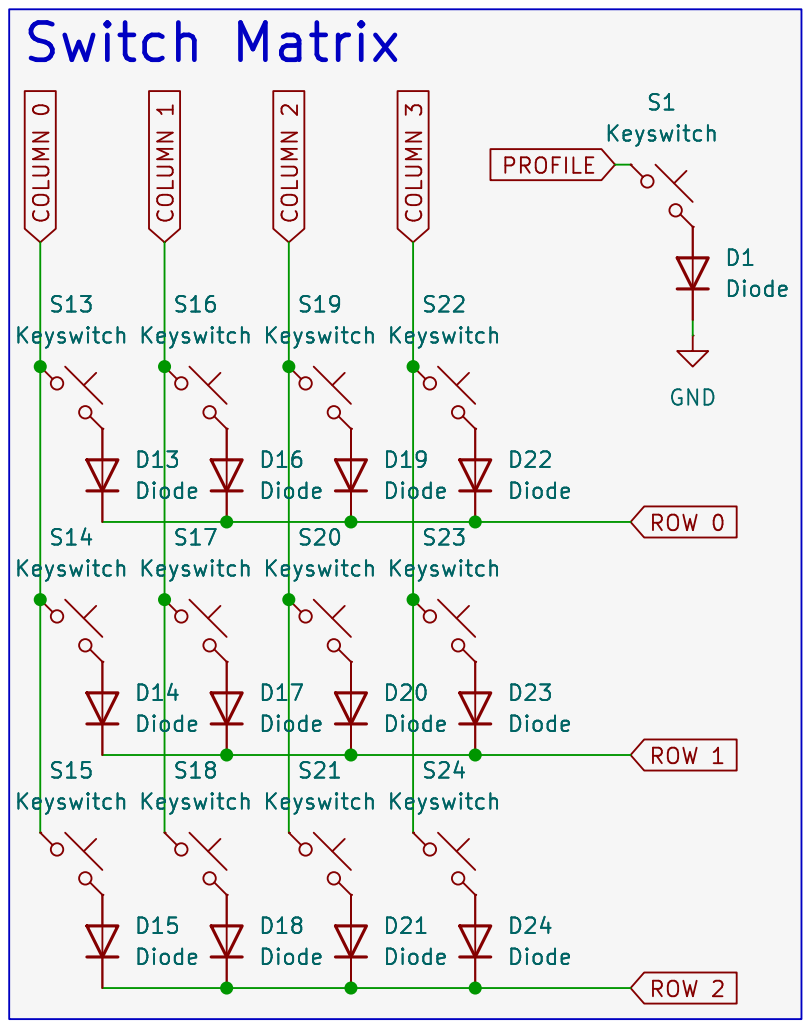
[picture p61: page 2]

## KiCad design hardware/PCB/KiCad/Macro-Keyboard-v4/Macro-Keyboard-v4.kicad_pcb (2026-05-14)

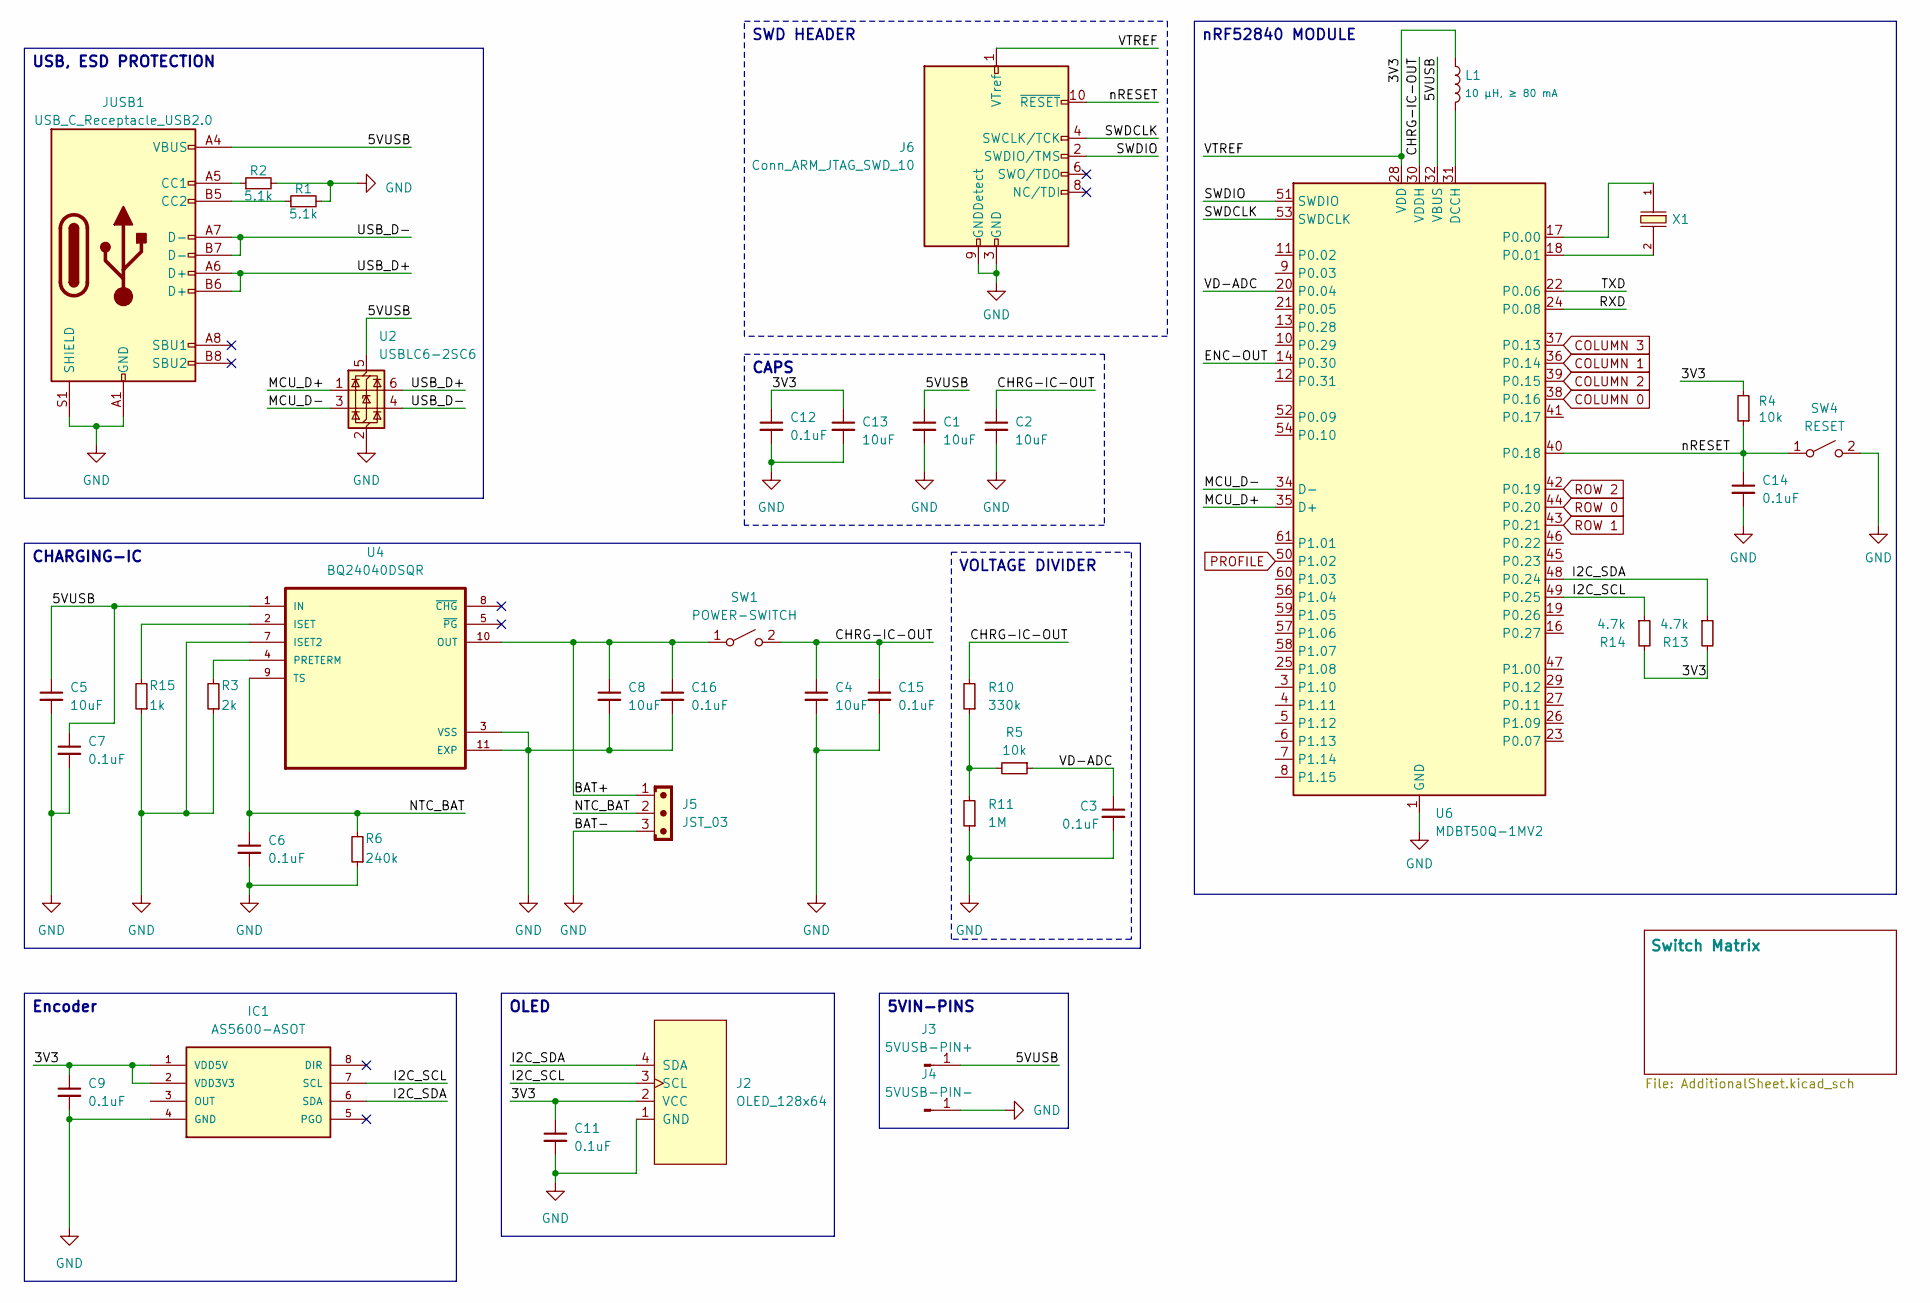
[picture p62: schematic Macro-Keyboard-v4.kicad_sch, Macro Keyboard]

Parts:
C1, C2, C4, C5, C8, C13: 10uF; C_0603_1608Metric
C3, C6, C7, C9, C11, C12, C14, C15, C16: 0.1uF; C_0603_1608Metric
IC1: AS5600-ASOT; SOIC127P600X175-8N; MOUSER_PART_NUMBER 985-AS5600-ASOT
J2: OLED_128x64
J3: 5VUSB-PIN+; BatteryPad
J4: 5VUSB-PIN-; BatteryPad
J5: JST_03; JST_XH_B3B-XH-AM_1x03_P2.50mm_Vertical
J6: Conn_ARM_JTAG_SWD_10; PinHeader_2x05_P1.27mm_Vertical
JUSB1: USB_C_Receptacle_USB2.0; USB_C_Receptacle_GCT_USB4105-xx-A_16P_TopMnt_Horizontal
L1: 10 µH, ≥ 80 mA; L_TDK_MLZ1608
R1, R2: 5.1k; R_0603_1608Metric
R3: 2k; R_0603_1608Metric
R4, R5: 10k; R_0603_1608Metric
R6: 240k; R_0603_1608Metric
R10: 330k; R_0603_1608Metric
R11: 1M; R_0603_1608Metric
R13, R14: 4.7k; R_0603_1608Metric
R15: 1k; R_0603_1608Metric
SW1: POWER-SWITCH; SW_SPDT_PCM12
SW4: RESET; SW_SPST_B3U-1000P; LCSC C720477
U2: USBLC6-2SC6; ESD_SOT-23-6; LCSC C2827654
U4: BQ24040DSQR; SON40P200X200X80-11N
U6: MDBT50Q-1MV2; Raytac_MDBT50Q
X1: Q13FC1350000400; FC-135R_L3.2-W1.5; Frequency Tolerance ±20ppm; Part Q13FC13500004; LCSC C32346

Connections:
/3V3: C9.1, C11.1, C12.1, C13.1, IC1.1 (VDD5V), IC1.2 (VDD3V3), J2.2 (VCC), J6.1 (VTref), L1.1, R4.2, R13.2, R14.2, U6.28 (VDD)
/5VUSB: C1.1, C5.1, C7.1, J3.1, JUSB1.A4 (VBUS), JUSB1.A9 (VBUS), JUSB1.B4 (VBUS), JUSB1.B9 (VBUS), U2.5 (VBUS), U4.1 (IN), U6.32 (VBUS)
/BAT+: C8.1, C16.1, J5.1, SW1.1 (A), U4.10 (OUT)
/CHRG-IC-OUT: C2.1, C4.1, C15.1, R10.2, SW1.2 (B), U6.30 (VDDH)
/ENC-OUT: U6.14 (P0.30)
/I2C_SCL: IC1.7 (SCL), J2.3 (SCL), R14.1, U6.49 (P0.25)
/I2C_SDA: IC1.6 (SDA), J2.4 (SDA), R13.1, U6.48 (P0.24)
/MCU_D+: U2.1 (I/O1), U6.35 (D+)
/MCU_D-: U2.3 (I/O2), U6.34 (D-)
/NTC_BAT: C6.1, J5.2, R6.2, U4.9 (TS)
/RXD: U6.24 (P0.08)
/SWDCLK: J6.4 (SWCLK/TCK), U6.53 (SWDCLK)
/SWDIO: J6.2 (SWDIO/TMS), U6.51 (SWDIO)
/TXD: U6.22 (P0.06)
/USB_D+: JUSB1.A6 (D+), JUSB1.B6 (D+), U2.6 (I/O1)
/USB_D-: JUSB1.A7 (D-), JUSB1.B7 (D-), U2.4 (I/O2)
/VD-ADC: C3.1, R5.1, U6.20 (P0.04)
/nRESET: C14.1, J6.10 (~RESET), R4.1, SW4.1 (A), U6.40 (P0.18)
COLUMN 0: U6.38 (P0.16); also elsewhere on the board
COLUMN 1: U6.36 (P0.14); also elsewhere on the board
COLUMN 2: U6.39 (P0.15); also elsewhere on the board
COLUMN 3: U6.37 (P0.13); also elsewhere on the board
GND: C1.2, C2.2, C3.2, C4.2, C5.2, C6.2, C7.2, C8.2, C9.2, C11.2, C12.2, C13.2, C14.2, C15.2, C16.2, IC1.4 (GND), J2.1 (GND), J4.1, J5.3, J6.3 (GND), J6.5 (GND), J6.9 (GNDDetect), JUSB1.A1 (GND), JUSB1.A12 (GND), JUSB1.B1 (GND), JUSB1.B12 (GND), JUSB1.S1 (SHIELD), R1.2, R2.2, R3.1, R6.1, R11.1, R15.1, SW4.2 (B), U2.2 (GND), U4.3 (VSS), U4.7 (ISET2), U4.11 (EXP), U6.1 (GND), U6.2 (GND), U6.15 (GND), U6.33 (GND), U6.55 (GND); also elsewhere on the board
unnamed: JUSB1.A5 (CC1), R2.1
unnamed: JUSB1.B5 (CC2), R1.1
unnamed: R5.2, R10.1, R11.2
unnamed: R15.2, U4.2 (ISET)
unnamed: R3.2, U4.4 (PRETERM)
unnamed: L1.2, U6.31 (DCCH)
unnamed: U6.17 (P0.00), X1.1
unnamed: U6.18 (P0.01), X1.2
PROFILE: U6.50 (P1.02); also elsewhere on the board
ROW 0: U6.44 (P0.20); also elsewhere on the board
ROW 1: U6.43 (P0.21); also elsewhere on the board
ROW 2: U6.42 (P0.19); also elsewhere on the board

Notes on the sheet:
OLED
USB, ESD PROTECTION
CAPS
SWD HEADER
Encoder
nRF52840 MODULE
5VIN-PINS
VOLTAGE DIVIDER
CHARGING-IC

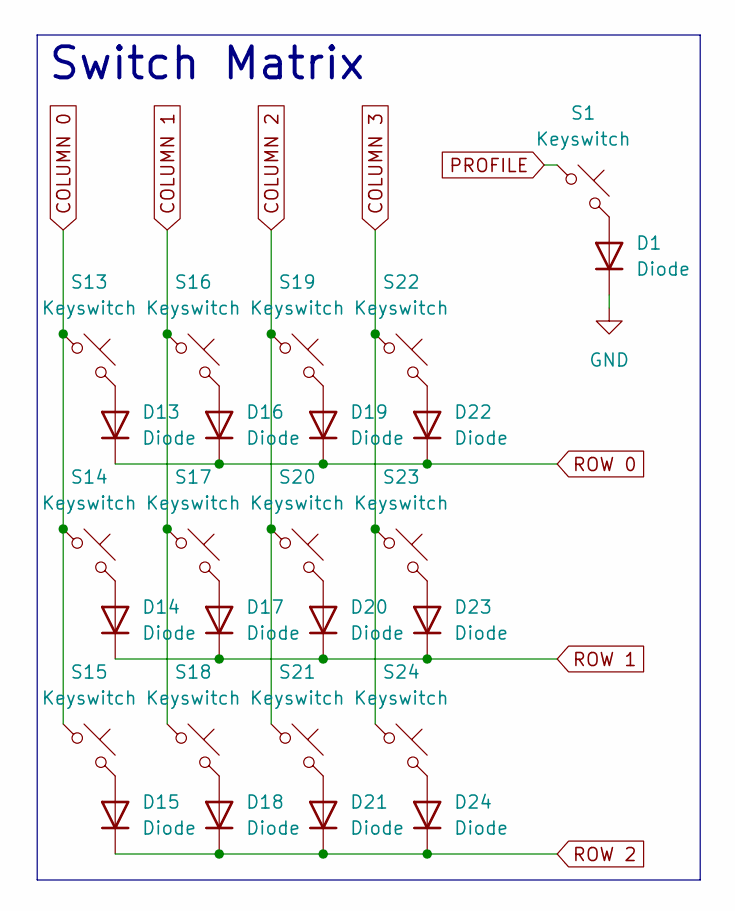
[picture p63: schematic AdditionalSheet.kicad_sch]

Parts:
D1, D13, D14, D15, D16, D17, D18, D19, D20, D21, D22, D23, D24: Diode; Diode_SOD-123
S1, S13, S14, S15, S16, S17, S18, S19, S20, S21, S22, S23, S24: Keyswitch; MX_PCB_1.00u

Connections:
COLUMN 0: S13.1, S14.1, S15.1; also elsewhere on the board
COLUMN 1: S16.1, S17.1, S18.1; also elsewhere on the board
COLUMN 2: S19.1, S20.1, S21.1; also elsewhere on the board
COLUMN 3: S22.1, S23.1, S24.1; also elsewhere on the board
GND: D1.1 (K); also elsewhere on the board
unnamed: D1.2 (A), S1.2
unnamed: D13.2 (A), S13.2
unnamed: D14.2 (A), S14.2
unnamed: D15.2 (A), S15.2
unnamed: D16.2 (A), S16.2
unnamed: D17.2 (A), S17.2
unnamed: D18.2 (A), S18.2
unnamed: D19.2 (A), S19.2
unnamed: D20.2 (A), S20.2
unnamed: D21.2 (A), S21.2
unnamed: D22.2 (A), S22.2
unnamed: D23.2 (A), S23.2
unnamed: D24.2 (A), S24.2
PROFILE: S1.1; also elsewhere on the board
ROW 0: D13.1 (K), D16.1 (K), D19.1 (K), D22.1 (K); also elsewhere on the board
ROW 1: D14.1 (K), D17.1 (K), D20.1 (K), D23.1 (K); also elsewhere on the board
ROW 2: D15.1 (K), D18.1 (K), D21.1 (K), D24.1 (K); also elsewhere on the board

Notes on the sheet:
Switch Matrix

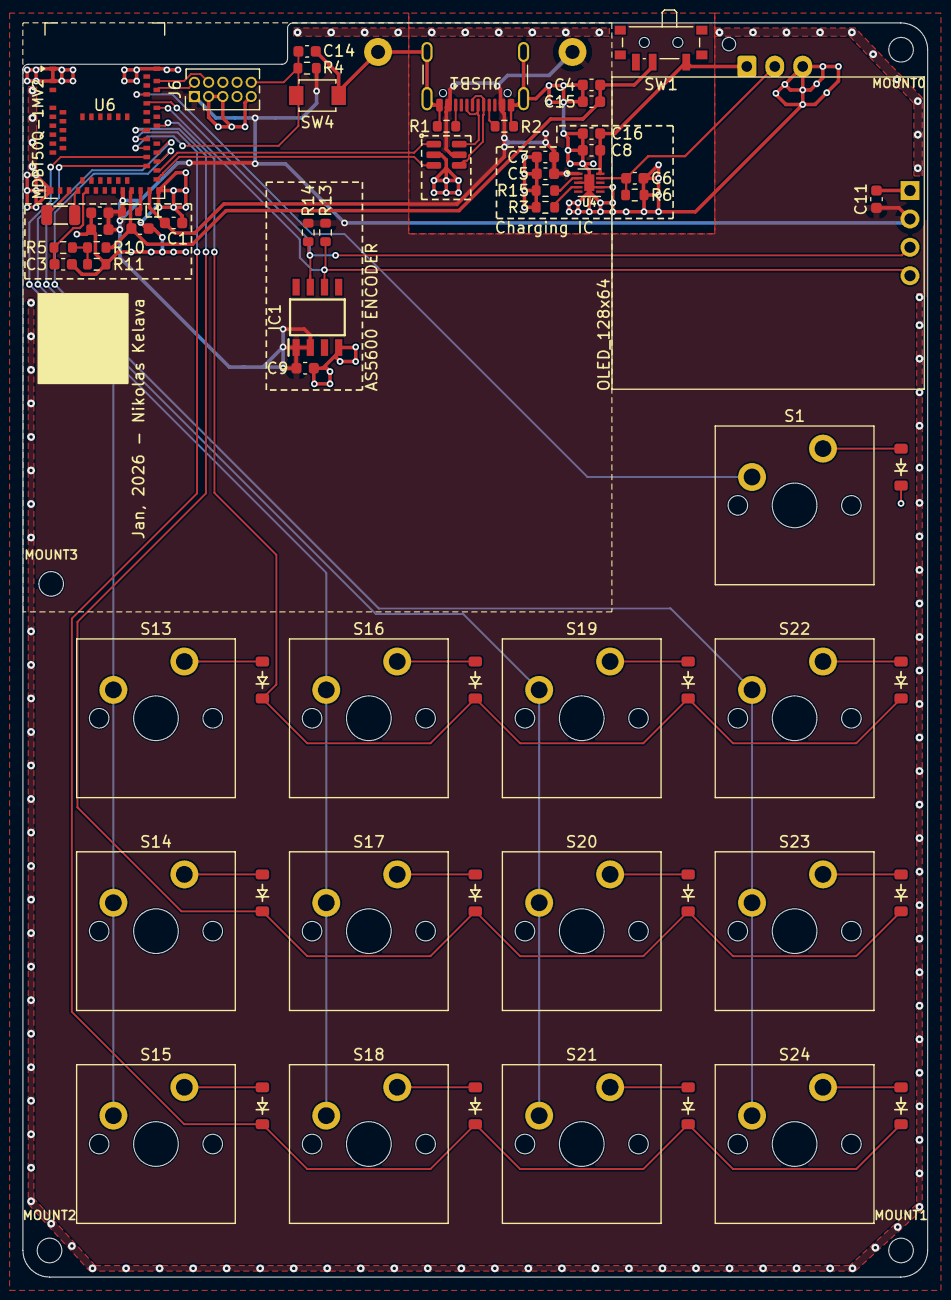
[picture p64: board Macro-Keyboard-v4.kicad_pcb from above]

Board: 4 copper layers, 81.0 x 112.2 mm, 70 parts (1 on the bottom side), 45 nets.

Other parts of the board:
MOUNT0, MOUNT1, MOUNT2, MOUNT3: MountingHole_2.2mm_M2

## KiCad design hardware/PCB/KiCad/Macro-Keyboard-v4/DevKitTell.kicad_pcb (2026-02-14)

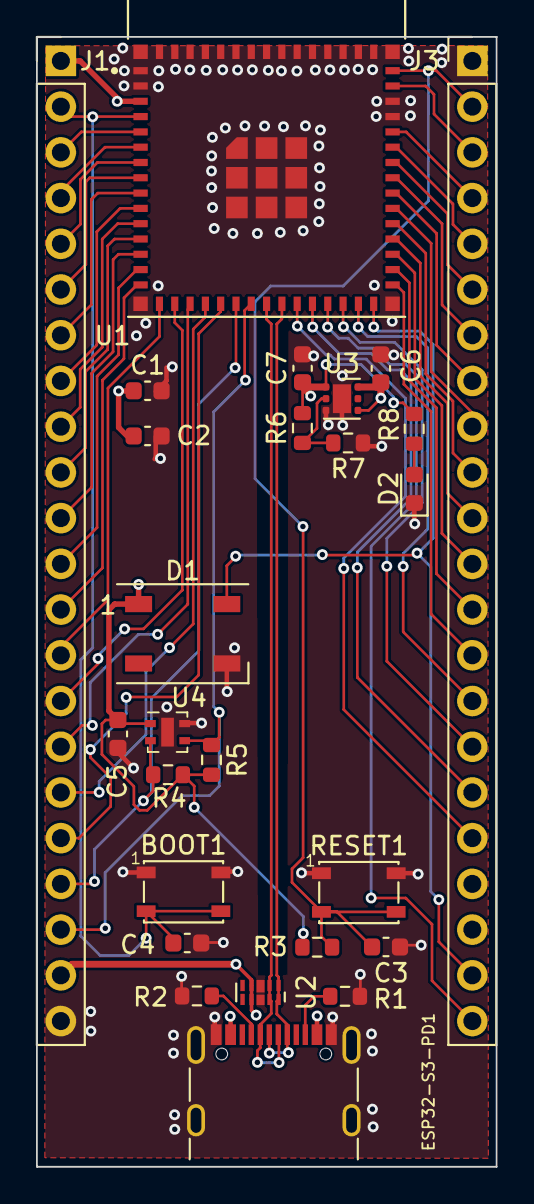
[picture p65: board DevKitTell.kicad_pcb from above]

Board: 4 copper layers, 25.5 x 62.8 mm, 26 parts (0 on the bottom side), 47 nets.

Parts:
BOOT1: SW_SPST_PTS810
C1, C3, C4, C5: 0.1uF; C_0603_1608Metric
C2, C6, C7: 10uF; C_0603_1608Metric
D1: WS2812B; LED_WS2812B_PLCC4_5.0x5.0mm_P3.2mm
D2: LED; LED_0603_1608Metric
J1, J3: PinHeader_1x22_P2.54mm_Vertical
JUSB1: USB_C_Receptacle_USB2.0; USB_C_Receptacle_GCT_USB4105-xx-A_16P_TopMnt_Horizontal
R1, R2, R8: 5.1k; R_0603_1608Metric
R3, R4, R5: 10k; R_0603_1608Metric
R6: 1M; R_0603_1608Metric
R7: 200k; R_0603_1608Metric
RESET1: SW_SPST_PTS810
U1: ESP32-S3-MINI-1-N8; XCVR_ESP32-S3-MINI-1-N8
U2: D3V3XA4B10LP; Diodes_UDFN-10_1.0x2.5mm_P0.5mm
U3: TLV75801PDRV; WSON-6-1EP_2x2mm_P0.65mm_EP1x1.6mm
U4: ENS210; AMS_QFN-4-1EP_2x2mm_P0.95mm_EP0.7x1.6mm

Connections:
/3V3: C1.1, C2.1, C5.1, C7.1, D1.1 (VDD), J1.1, R3.2, R4.2, R5.2, R6.2, R8.1, U1.3 (3V3), U3.1 (OUT), U4.1 (VDD)
/5VUSB: C6.1, J1.21, JUSB1.A4 (VBUS), JUSB1.A9 (VBUS), JUSB1.B4 (VBUS), JUSB1.B9 (VBUS), U2.4, U2.7 (NC), U3.4 (EN), U3.6 (IN)
/ESP32_EN: C3.1, J3.2, R3.1, RESET1.3 (K), RESET1.4 (A), U1.45 (EN)
/GPIO0: BOOT1.3 (K), BOOT1.4 (A), C4.1, J1.2, U1.4 (IO0)
/GPIO1: J1.3, U1.5 (IO1)
/GPIO2: J1.4, U1.6 (IO2)
/GPIO3: J1.5, U1.7 (IO3)
/GPIO4: J1.6, U1.8 (IO4)
/GPIO5: J1.7, U1.9 (IO5)
/GPIO6: J1.8, U1.10 (IO6)
/GPIO7: J1.9, U1.11 (IO7)
/GPIO8: J1.10, U1.12 (IO8)
/GPIO9: J1.11, U1.13 (IO9)
/GPIO10: J1.12, U1.14 (IO10)
/GPIO11: J1.13, U1.15 (IO11)
/GPIO12: J1.14, U1.16 (IO12)
/GPIO13: J1.15, U1.17 (IO13)
/GPIO14: J1.16, U1.18 (IO14)
/GPIO15: J1.17, U1.19 (IO15)
/GPIO16: J1.18, U1.20 (IO16)
/GPIO21: J3.18, U1.25 (IO21)
/GPIO26: J3.17, U1.26 (IO26)
/GPIO33: J3.16, U1.28 (IO33)
/GPIO34: J3.15, U1.29 (IO34)
/GPIO35: J3.14, U1.31 (IO35)
/GPIO36: J3.13, U1.32 (IO36)
/GPIO37: J3.12, U1.33 (IO37)
/GPIO38: J3.11, U1.34 (IO38)
/GPIO39: J3.10, U1.35 (IO39)
/GPIO40: J3.9, U1.36 (IO40)
/GPIO41: J3.8, U1.37 (IO41)
/GPIO42: J3.7, U1.38 (IO42)
/GPIO45: J3.4, U1.41 (IO45)
/GPIO46: J3.3, U1.44 (IO46)
/GPIO47: J3.22, U1.27 (IO47)
/GPIO48: D1.4 (DIN), J3.21, U1.30 (IO48)
/I2C_SCL: J1.19, R4.1, U1.21 (IO17), U4.2 (SCL)
/I2C_SDA: J1.20, R5.1, U1.22 (IO18), U4.3 (SDA)
/RXD: J3.5, U1.40 (RXD0)
/TXD: J3.6, U1.39 (TXD0)
/USB_N: JUSB1.A7 (D-), JUSB1.B7 (D-), U1.23 (IO19), U2.2, U2.9 (NC)
/USB_P: JUSB1.A6 (D+), JUSB1.B6 (D+), U1.24 (IO20), U2.1, U2.10 (NC)
GND: BOOT1.1, BOOT1.2, C1.2, C2.2, C3.2, C4.2, C5.2, C6.2, C7.2, D1.3 (VSS), D2.1 (K), J1.22, J3.1, JUSB1.A1 (GND), JUSB1.A12 (GND), JUSB1.B1 (GND), JUSB1.B12 (GND), JUSB1.S1 (SHIELD), R1.2, R2.2, R7.1, RESET1.1, RESET1.2, U1.1 (GND), U1.2 (GND), U1.42 (GND), U1.43 (GND), U1.46 (GND), U1.47 (GND), U1.48 (GND), U1.49 (GND), U1.50 (GND), U1.51 (GND), U1.52 (GND), U1.53 (GND), U1.54 (GND), U1.55 (GND), U1.56 (GND), U1.57 (GND), U1.58 (GND), U1.59 (GND), U1.60 (GND), U1.61 (GND), U1.61_1 (GND), U1.61_2 (GND), U1.61_3 (GND), U1.61_4 (GND), U1.61_5 (GND), U1.61_6 (GND), U1.61_7 (GND), U1.61_8 (GND), U1.62 (GND), U1.63 (GND), U1.64 (GND), U1.65 (GND), U2.3 (VSS), U2.8 (VSS), U3.3 (GND), U3.7 (GND), U4.4 (GND), U4.5 (GND)
unnamed: D2.2 (A), R8.2
unnamed: JUSB1.A5 (CC1), R2.1
unnamed: JUSB1.B5 (CC2), R1.1
unnamed: R6.1, R7.2, U3.2 (FB)

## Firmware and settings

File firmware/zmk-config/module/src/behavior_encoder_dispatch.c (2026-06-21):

/*
 * Copyright (c) 2026 The ZMK Contributors
 * SPDX-License-Identifier: MIT
 *
 * Custom ZMK sensor behavior: &enc_dispatch.
 *
 * Bound as the sensor-binding on every profile layer. Instead of a fixed
 * action, it reads the current profile's encoder mode (see encoder_mode.c) at
 * the moment of each tick and emits the matching action:
 *
 *   ENC_MODE_VOLUME  -> &kp C_VOL_UP / C_VOL_DN       (queued key presses)
 *   ENC_MODE_VSCROLL -> INPUT_REL_WHEEL  report        (up/down)
 *   ENC_MODE_HSCROLL -> INPUT_REL_HWHEEL report        (right/left)
 *   ENC_MODE_TABS    -> &kp LC(TAB) / LC(LS(TAB))      (next/prev browser tab)
 *
 * Per-mode resolution. This accumulates raw rotation in micro-degrees and
 * quantises it with the *current mode's* own triggers-per-rotation, so each
 * mode picks how many ticks a full turn produces:
 *   - volume + tabs use a COARSE value (a small turn = one step), and
 *   - the scroll modes use a finer value.
 * The sub-tick remainder is carried, so nothing is lost and switching mode
 * mid-turn is seamless.
 *
 * --- Scroll model (clean linear stream; the host owns the feel) -------------
 * Long investigation conclusion: on macOS the scroll *feel* (smoothing +
 * acceleration) is owned by the host. macOS velocity-caps the report rate
 * (more reports/s does not scroll faster) and either applies its own bad accel
 * curve or, via an app, normalises magnitude. The good outcome is a smooth-
 * scroll app (Mac Mouse Fix / Mos) doing pixel smoothing + tunable
 * acceleration. So the firmware deliberately does NO acceleration: it emits a
 * clean LINEAR stream of wheel line-deltas (d_scroll = ticks * scroll-units)
 * and lets the app shape it. Base speed is set by scroll-triggers-per-rotation
 * (lines per revolution). One report per sensor event keeps the rate bounded.
 *
 * CW (positive rotation) maps to volume-up / scroll-up / scroll-right / next-tab.
 */

#define DT_DRV_COMPAT zmk_behavior_encoder_dispatch

#include <zephyr/device.h>
#include <zephyr/kernel.h>
#include <zephyr/logging/log.h>

#include <dt-bindings/zmk/keys.h>

#include <drivers/behavior.h>
#include <zmk/behavior.h>
#include <zmk/behavior_queue.h>
#include <zmk/keymap.h>
#include <zmk/sensors.h>
#include <zmk/virtual_key_position.h>

#include "encoder_mode.h"

#if IS_ENABLED(CONFIG_ZMK_POINTING)
#include <zephyr/input/input.h>
#include <zephyr/dt-bindings/input/input-event-codes.h>
#endif

LOG_MODULE_DECLARE(zmk, CONFIG_ZMK_LOG_LEVEL);

#if DT_HAS_COMPAT_STATUS_OKAY(DT_DRV_COMPAT)

/* Rotation is accumulated in micro-degrees so the modes can use very different
 * resolutions without rounding drift. */
#define MICRODEG_PER_DEG 1000000
#define MICRODEG_PER_REV 360000000

#if IS_ENABLED(CONFIG_ZMK_POINTING)
/* The &msc node's device doubles as the input device its listener consumes. */
static const struct device *const scroll_dev = DEVICE_DT_GET(DT_NODELABEL(msc));
#endif

struct enc_dispatch_config {
    int tap_ms;
    int scroll_units;          /* wheel line-delta per scroll tick (keep small)   */
    int volume_tpr;            /* triggers per rotation in volume mode (coarse)   */
    int tab_tpr;               /* triggers per rotation in tab mode (coarse)      */
    int scroll_tpr;            /* triggers per rotation in scroll modes           */
    int scroll_max_value;      /* safety clamp on the per-report wheel magnitude  */
    int scroll_min_interval_ms; /* min gap between scroll HID reports (coalesce)  */
};

struct enc_dispatch_data {
    int32_t accum_microdeg[ZMK_KEYMAP_SENSORS_LEN][ZMK_KEYMAP_LAYERS_LEN];
    int ticks[ZMK_KEYMAP_SENSORS_LEN][ZMK_KEYMAP_LAYERS_LEN];
#if IS_ENABLED(CONFIG_ZMK_POINTING)
    /* Scroll report coalescing/rate-limit state (per sensor). */
    int32_t scroll_pending[ZMK_KEYMAP_SENSORS_LEN]; /* signed line-deltas not yet sent */
    uint16_t scroll_axis[ZMK_KEYMAP_SENSORS_LEN];   /* INPUT_REL_WHEEL / HWHEEL         */
    uint32_t last_scroll_ms[ZMK_KEYMAP_SENSORS_LEN]; /* last emit time                  */
#endif
};

/* Triggers-per-rotation for the active mode: coarse for the discrete key modes
 * (volume, tabs), finer for the scroll modes. */
static int enc_dispatch_tpr(const struct enc_dispatch_config *cfg, enum encoder_mode m) {
    switch (m) {
    case ENC_MODE_VOLUME:
        return cfg->volume_tpr;
    case ENC_MODE_TABS:
        return cfg->tab_tpr;
    default:
        return cfg->scroll_tpr;
    }
}

static int enc_dispatch_accept_data(struct zmk_behavior_binding *binding,
                                    struct zmk_behavior_binding_event event,
                                    const struct zmk_sensor_config *sensor_config,
                                    size_t channel_data_size,
                                    const struct zmk_sensor_channel_data *channel_data) {
    const struct device *dev = zmk_behavior_get_binding(binding->behavior_dev);
    const struct enc_dispatch_config *cfg = dev->config;
    struct enc_dispatch_data *data = dev->data;

    ARG_UNUSED(sensor_config); /* resolution is per-mode (below), not the node's */
    ARG_UNUSED(channel_data_size);

    const struct sensor_value value = channel_data[0].value;
    const int sensor_index = ZMK_SENSOR_POSITION_FROM_VIRTUAL_KEY_POSITION(event.position);

    /* Accumulate rotation in micro-degrees. The AS5600 driver reports
     * whole+fractional degrees on SENSOR_CHAN_ROTATION. */
    int32_t accum = data->accum_microdeg[sensor_index][event.layer] +
                    value.val1 * MICRODEG_PER_DEG + value.val2;

    /* Quantise with the current mode's triggers-per-rotation; carry the
     * sub-tick remainder. */
    const int tpr = enc_dispatch_tpr(cfg, encoder_mode_get());
    const int32_t trigger_microdeg = MICRODEG_PER_REV / tpr;
    const int ticks = accum / trigger_microdeg;

    data->accum_microdeg[sensor_index][event.layer] = accum - ticks * trigger_microdeg;
    data->ticks[sensor_index][event.layer] = ticks;
    return 0;
}

static int enc_dispatch_process(struct zmk_behavior_binding *binding,
                                struct zmk_behavior_binding_event event,
                                enum behavior_sensor_binding_process_mode mode) {
    const struct device *dev = zmk_behavior_get_binding(binding->behavior_dev);
    const struct enc_dispatch_config *cfg = dev->config;
    struct enc_dispatch_data *data = dev->data;

    const int sensor_index = ZMK_SENSOR_POSITION_FROM_VIRTUAL_KEY_POSITION(event.position);

    if (mode != BEHAVIOR_SENSOR_BINDING_PROCESS_MODE_TRIGGER) {
        data->ticks[sensor_index][event.layer] = 0;
        return ZMK_BEHAVIOR_TRANSPARENT;
    }

    int ticks = data->ticks[sensor_index][event.layer];
    if (ticks == 0) {
        return ZMK_BEHAVIOR_TRANSPARENT;
    }

    const bool cw = ticks > 0;
    const int count = cw ? ticks : -ticks;
    const enum encoder_mode m = encoder_mode_get();
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

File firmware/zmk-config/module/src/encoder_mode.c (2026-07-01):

/*
 * Copyright (c) 2026 The ZMK Contributors
 * SPDX-License-Identifier: MIT
 *
 * Per-profile encoder-mode state. See encoder_mode.h.
 */

#include <zephyr/logging/log.h>
#include <zephyr/settings/settings.h>

#include <zmk/keymap.h>

#include "encoder_mode.h"

LOG_MODULE_REGISTER(encoder_mode, CONFIG_ZMK_LOG_LEVEL);

ZMK_EVENT_IMPL(zmk_encoder_mode_changed);

/* One mode slot per keymap layer (profile). Sized to the compile-time layer
 * count so it scales with however many profiles exist. */
#define PROFILE_COUNT ZMK_KEYMAP_LAYERS_LEN

/* Default mode per profile; profiles beyond these zero-init to ENC_MODE_VOLUME
 * (value 0). Reach horizontal scroll by cycling &enc_mode_next. These defaults
 * apply on a fresh device; settings_load() (below) overwrites them with the
 * persisted values at boot if any were saved. */
static enum encoder_mode modes[PROFILE_COUNT] = {
    ENC_MODE_VOLUME,
    ENC_MODE_VSCROLL,
    ENC_MODE_TABS,
    ENC_MODE_VOLUME,
};

/* Persistence (NVS via the settings subsystem). The per-profile modes are saved
 * under "encmode/modes" as the raw array blob and reloaded at boot by ZMK's
 * settings_load() in main.c. The save is dispatched immediately (K_NO_WAIT) on
 * the system work queue rather than debounced: mode changes are deliberate and
 * infrequent, and the user wants a cycle to survive an immediate power-off, so
 * we persist as soon as possible (off the caller's stack — flash writes don't
 * belong in the behavior/event context). Rapid cycles within one work-queue
 * tick still coalesce into a single save of the final value. The blob size is
 * stable across Studio add/remove (PROFILE_COUNT is the compile-time layer
 * count, incl. reserved slots); a length mismatch on load (e.g. a firmware
 * rebuild that changed the layer count) is ignored, falling back to defaults. */
#if IS_ENABLED(CONFIG_SETTINGS)

static void encoder_mode_save_work_cb(struct k_work *work) {
    ARG_UNUSED(work);
    int ret = settings_save_one("encmode/modes", modes, sizeof(modes));
    if (ret) {
        LOG_WRN("Failed to persist encoder modes (err %d)", ret);
    }
}

static K_WORK_DELAYABLE_DEFINE(encoder_mode_save_work, encoder_mode_save_work_cb);

static void encoder_mode_save(void) {
    k_work_reschedule(&encoder_mode_save_work, K_NO_WAIT);
}

static int encoder_mode_settings_set(const char *name, size_t len, settings_read_cb read_cb,
                                     void *cb_arg) {
    if (settings_name_steq(name, "modes", NULL)) {
        if (len != sizeof(modes)) {
            LOG_WRN("Stored encoder modes size %u != expected %u; using defaults", (unsigned)len,
                    (unsigned)sizeof(modes));
            return -EINVAL;
        }
        int ret = read_cb(cb_arg, modes, sizeof(modes));
        if (ret <= 0) {
            LOG_WRN("Failed to read encoder modes from settings (err %d)", ret);
            return ret;
        }
    }
    return 0;
}

SETTINGS_STATIC_HANDLER_DEFINE(encoder_mode, "encmode", NULL, encoder_mode_settings_set, NULL, NULL);

#else

static void encoder_mode_save(void) {}

#endif /* IS_ENABLED(CONFIG_SETTINGS) */

/* Profile == highest active keymap layer (same source &profile_next advances),
 * clamped into range for safety. */
static int current_profile(void) {
    int p = zmk_keymap_highest_layer_active();
    if (p < 0 || p >= PROFILE_COUNT) {
        p = 0;
    }
    return p;
}

enum encoder_mode encoder_mode_get(void) {
    return modes[current_profile()];
}

void encoder_mode_cycle(void) {
    int p = current_profile();
    modes[p] = (modes[p] + 1) % ENC_MODE_COUNT;
    encoder_mode_save();
    raise_zmk_encoder_mode_changed((struct zmk_encoder_mode_changed){.mode = (uint8_t)modes[p]});
}

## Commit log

2026-02-14 Adding Hardware Files
    [3D_MODEL_D3V3XA4B10LP-7.stp, AdditionalSheet.kicad_sch, DevKitTell.kicad_pcb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]
2026-02-19 Minimal Board Config
    Adding the minimal required board files so Zephyr recognizes the board, including ZMK-Studio support and a cursorrules file
2026-02-19 Adding missing features
    Profile system: adding 4 profiles as layers and a dedicated profile switch button to cycle between the profiles, OLED enablement: turn on I2C OLED support and integrate display updates for battery + active profile indicator, Battery reporting, Encoder integration: add AS5600-based encoder input and map per-profile encoder actions (volume/vertical scroll/horizontal scroll), ZMK Studio support for all of that
2026-02-19 Restructuring hardware folders
    [AdditionalSheet.kicad_sch, DevKitTell.kicad_pcb, Macro-Keyboard-v4.kicad_pcb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]
2026-04-12 Revert board config
    Board config had fundamental problems. Deleting them in order to completely start from scratch.
    [Macro-Keyboard-v4.kicad_pcb]
2026-04-13 Milestone 1: Create minimal board config
2026-05-06 Milestone 1: Flash partition layout (fixed)
    [BOTTOM-v27.stl, Case-v27.step, macro_keyboard_v4.3mf]
2026-05-06 Milestone 2: Activate UI + sensors
2026-05-14 Milestone 3: Profiles
    Additionally redefined the Milestones
    [Macro-Keyboard-v4.kicad_pcb, macro_keyboard_v4.3mf]
2026-05-28 Milestone 4: BUILT_IN screen
    [macro_keyboard_v4.3mf]
2026-05-31 Cosmetics Screen (Battery icon + layout)
    [macro_keyboard_v4.3mf]
2026-06-08 Milestone 5: AS5600 Encoder (+smooth scrolling without acceleration)
    + fixed the overheating issue of the mac when flashing the board via uf2
    [as5600.c, behavior_encoder_dispatch.c, behavior_encoder_mode_next.c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]
2026-06-08 Milestone 5: Encoder documentation
2026-06-21 Milestone 5: Adding high res scrolling + tab mode + usb hang fix (root cause)
    [behavior_encoder_dispatch.c, encoder_mode.c]
2026-07-01 Milestone 6 + bug fixes
    [as5600.c, encoder_mode.c, status_screen.c]
2026-07-03 Adding BOMs and PCB(A) production files
    [AdditionalSheet.kicad_sch, BOM.csv, BOM_PCB.csv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]
2026-07-04 BOM.csv: comma-delimited for GitHub; ignore SHIP_CHECKLIST
    [BOM.csv]
2026-07-22 Adding in the journal entries from 05-28 to 06-30
    [macro_keyboard_v4.3mf]
2026-07-25 KiCad pics directory in journal fixed
2026-07-25 Adding BUILD.md + improving README.md + CLAUDE.md
    [BOM_PCB.csv]
2026-07-25 Adding demo photos + case files (fusion source + meshes)
    [enclosure+knob.obj, keycap-corner-left.obj, keycap-corner-right.obj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]
